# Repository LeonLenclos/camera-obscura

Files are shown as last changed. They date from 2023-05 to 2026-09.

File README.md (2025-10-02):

# Camera Obscura
Théâtre optique post-cinéma

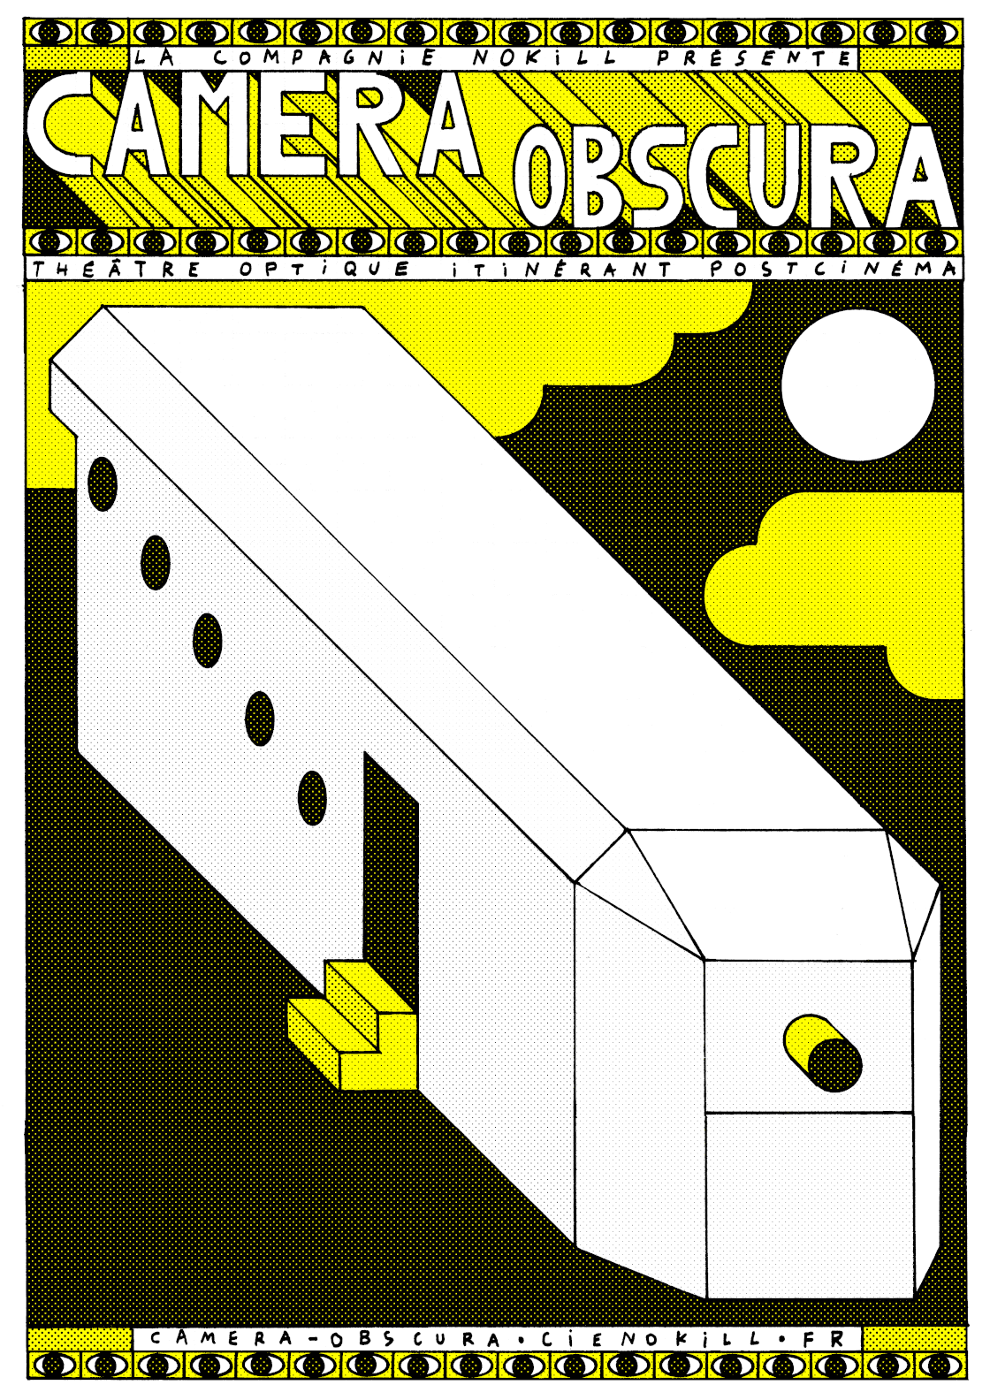
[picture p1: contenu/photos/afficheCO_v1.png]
Affiche Camera Obscura


*Camera Obscura* est un spectacle de théâtre optique itinérant de la Cie Nokill dont la première a eu lieu le 3 aout 2024. 

### Le dispositif

*Camera Obscura* est un dispositif qui propose au public l'expérience unique d'une séance de cinéma sans électricité. Les spectateur·ices s'installent dans la camera obscura et assistent à la projection d’un film réalisé en temps réel à l’extérieur. Les images sont projetées grâce à un système optique fait de lentilles et de miroirs. Les sons et la musique sont produits et interprétés en direct sur un ensemble d’instruments acoustiques et mécaniques.

### Souvenirs du futur

Le film projeté est [*Souvenirs du futur*](contenu/ecriture/souvenirs-du-futur.md). C'est une collection de fragments, des évocations vagues ou anecdotiques de futurs possibles. Des récits d'anticipation qui s'affranchissent des thèmes de la science fiction et proposent une vision ni utopique ni apocalyptique d'un futur pluriel, banal et étrange.

### Documentation du projet

Sur ce site nous avons rassemblé au fur et à mesure de la création, tous les contenus artistiques et techniques utiles. 

Même si à la base cette documentation est un outil de travail personnel, nous avons décidé de la mettre à disposition de toute personne intéressée par ce projet.

### Sommaire

- [Remorque](contenu/remorque.md), construction du théâtre optique "Camera Obscura".
- [Écriture](contenu/ecriture), textes, scenarios, découpages et références.
- [Objets](contenu/objet), plaques animées, marionettes, costumes, accéssoires, décors, utilisés dans le film.
- [Technique](contenu/technique), questions et réponses concernant les differents défis techniques. 
- [Prototypes](contenu/prototypes), liste des chambres construites pendant la création.
- [Production](contenu/production.md), partenaires du projet et calendrier des résidences.
- [Bibliographie](contenu/bibliographie.md), liens et documents utiles.

#### Documents

- [Dossier de création](contenu/dossier/dossier-camera-obscura.pdf), télécharger le dossier en pdf.
- [Fanzine](contenu/dossier/leprincipedelacameraobscura.pdf), télécharger *Le principe de la camera obscura* en pdf.
- [Ateliers](contenu/dossier/ateliers-camera-obscura.pdf), télécharger la doc des ateliers en pdf.

#### Divers

- [Todo](contenu/todo.md), bloc-notes des trucs à faire.
- [Media](contenu/media.md), liste de tous les media liés à la documentation de la création.
- [Meta](contenu/meta.md), Ressources liées à l'écriture de ce site.

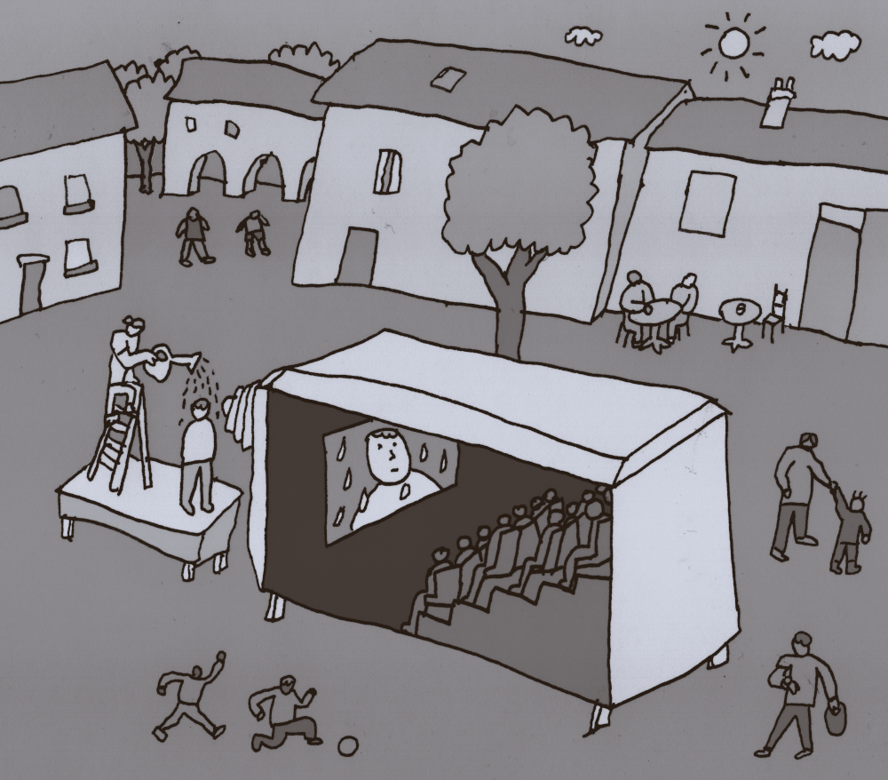
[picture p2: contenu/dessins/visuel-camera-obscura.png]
Dessin de la remorque


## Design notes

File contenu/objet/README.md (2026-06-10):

# Objet

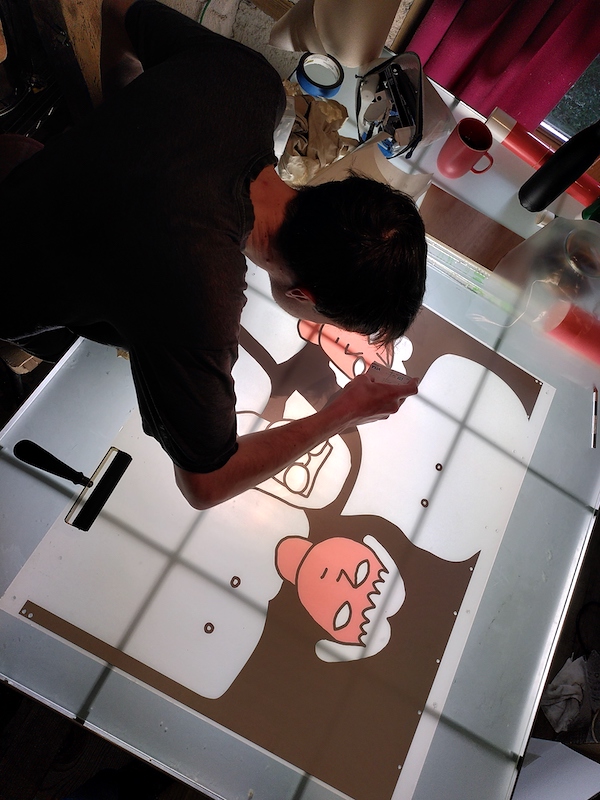
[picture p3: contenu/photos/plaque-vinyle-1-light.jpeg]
Pose de vinyle


Objets utilisés dans le film [*Souvenirs du futur*](../ecriture/souvenirs-du-futur.md).

- [Décors et accessoires](decors-accessoires.md)
- [Costumes](costumes.md) (et maquillage, coiffure)
- [Maquettes](maquettes.md)
- [Animations](animations.md) (plaques animées et marionettes)
- [Photos](photos.md)

## Rouleaux

- [titre](rouleau-titre.md) (source)
- [titre](rouleau-titre.pdf) (pdf)
- [photo](rouleau-photo.md) (source)
- [photo](rouleau-photo.pdf) (pdf)

```
# Créer pdf rouleau titre
wkhtmltopdf -T 0mm -B 0mm -L 0mm -R 0mm \
--page-width 500 --page-height 7010mm \
"https://camera-obscura.cienokill.fr/contenu/objet/rouleau-titre" rouleau-titre.pdf

# Créer pdf rouleau photo
wkhtmltopdf -T 0mm -B 0mm -L 0mm -R 0mm \
--page-width 780 --page-height 4010mm \
"https://camera-obscura.cienokill.fr/contenu/objet/rouleau-photo" rouleau-photo.pdf
```

## Billets

- [billets](billets/planche.md) (source)

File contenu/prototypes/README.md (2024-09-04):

# Les prototypes de chambres noires

dessin de trois prototypes
*De gauche à droite, les cameras 01, 02 et 03*

D'ici, on peut accéder aux fiches des différents protos de chambres noires (camera obscura). On distingue 2 types de réalisations :
- Les chambres individuelles, pour 1 regardeur à la fois (00, 01, 02, 03). Concues au départ pour tester les principes optiques du projet final (05) qui accueillera le spectacle, elles peuvent être disposées dans l'espace public en libre accès.
- Les chambres collectives pour un groupe de regardeurs dont le nombre peut varier de six (04) à vingt (05).

## Chambres individuelles

- [Camera obscura 00 - Mini camera obscura](camera00.md)
- [Camera obscura 01 - Les yeux dans le dos](camera01.md)
- [Camera obscura 02 - Chambre à antotype](camera02.md)
- [Camera obscura 03 - Chambre grand format](camera03.md)

## Chambres collectives

- [Camera obscura 04 - Chambre sprinter](camera04.md)
- [Camera obscura 05 - Chambre remorque](../remorque.md)

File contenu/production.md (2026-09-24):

[CLIQUER ICI POUR ALLER DIRECTEMENT À *MAINTENANT* DANS LE CALENDRIER DES RÉSIDENCES ↓](#maintenant)

# Historique de la création

- Août 2016 : Léon rencontre une camera obscura au musée du cinéma de Gérone
- Décembre 2017 : Bertrand rencontre une camera obscura naturelle dans sa chambre à coucher
- Mai 2019 : Léon rencontre une camera obscura naturelle dans le camion de la compagnie lors d'une résidence de *Turing Test*
- Mai 2020 : début du développement du spectacle
- Juillet 2020 : première tentative de créer des camera obscura dans des pièces de la maison avec différents objectifs placés sur des fenêtres obstruées
- Janvier 2021 : premier dossier de présentation
- Décembre 2022 : fabrication du premier prototype de camera obscura, *Les yeux dans le dos*
- Octobre 2023 : début de construction de la remorque
- Janvier 2024 : finalisation du scénario de *Souvenirs du futur*
- Avril 2024 : début du travail de mise en scène avec Lucile
- Août 2024 : première du spectacle

Soit quatre ans d'échanges et de réflexions éparses, deux ans de recherche et développement, un an de prototypage, un an de création à plein temps

# Générique

Un film de :

- Bertrand Lenclos
- Léon Lenclos

Avec :

- Lucile Balézeaux
- Bertrand Lenclos
- Léon Lenclos

Diffusion :

- Myléna Profit

Construction Remorque :

- Fabien Durand (Soudure)
- Zou Lenclos (Construction)

Aménagement Remorque :

- Jean-Claude Azemar (Vitrerie)
- Laurent Fayard (Menuiserie)
- Didier Pons (Peinture Carrosserie)
- Éva Ricard (Couture)

Accessoires :

- Steffie Bayer (Prothèse-marionette)
- Marco Cohen (Réflecteur)

Costume

- Lucile Balézeaux

Musique et Design Sonore

- Bertrand Lenclos

Dessin

- Léon Lenclos

Production :

- NOKILL

Coproduction :

- MIMA
- Le Parvis
- Le Quai des savoirs

Accueil en résidence :

- Le Kiwi / ARTO
- Le Périscope
- CIRCA
- Les Scènes croisées de Lozère
- L'Association des clous

Soutien :

- DRAC Occitanie
- DGCA Commission Art de la Rue
- Région Occitanie

Remerciements :

- Eric Amblard
- Sylvain Bahos
- Ronan Bouvier 
- Joël Boya
- Elise de Couleurs Papilles
- CréaLab de Graulhet 
- Jérémie Dain
- Paco Labat
- Florence Laffitte
- Zou Lenclos
- Thomas Letellier
- Frederic Lombardo
- Francis Lopez
- Juan P. Martínez Pastor
- Les Pasticiens Volants
- Marc Reynaud
- Evelyne Salançon
- Virginie Talou
- Gérard Tayeb
- Cie Titanos
- Arnaud Vidal

Logiciels libres :

- GIMP
- Git
- Inkscape
- LibreCAD 

Fournisseur :

- Aquabrasion
- Schiavon
- Ferrières
- Capus

Musique additionnelle :

*Marina*, Interprété par Georges Briez et son orchestre

# Historique de la création

- Août 2016 : Léon rencontre une camera obscura au musée du cinéma de Gérone
- Décembre 2017 : Bertrand rencontre une camera obscura naturelle dans sa chambre à coucher
- Mai 2019 : Léon rencotre une camera obscura naturelle dans le Camion de la compagnie lors d'une résidence de *Turing Test*
- Mai 2020 : Début du développement du spectacle
- Juillet 2020 : Première tentative de créer des camera obscura dans des pièces de la maison avec différents objectifs placés sur des fenêtres obstruées.
- Janvier 2021 : Premier dossier de présentation
- Décembre 2022 : Fabrication du premier prototype de camera obscura, *Les yeux dans le dos*
- Octobre 2023 : Début de construction de la remorque
- Janvier 2024 : Finalisation du scénario de Souvenirs du Futur
- Avril 2024 : Début du travail de mise en scène avec Lucile
- Août 2024 : Première du spectacle

Soit quatre ans de d'échanges et de réflexion éparses, deux ans de recherche et développement, un an de prototypage, un an de création à plein temps

# Calendrier des résidences

## Résidences passées

### du 7/12/2022 au 14/12/2022 : Graulhet (81) - Nokill
- construction maquette "les yeux dans le dos"
- début construction chambre à anthotypes

### du 2/3/2023 au 4/3/2022 : Graulhet (81) - Nokill
- finitions chambre à anthotype
- début construction chambre grand format
- début construction double miroir

### du 6/3/2023 au 8/3/2022 : Toulouse (31) - QDS
- Améliorations protos
- Recherches autour du soufflet
- Documentation des protos
- Tests en extérieur

### du 1/4/2023 au 6/4/2023 : Graulhet (81) - Chez Pons et au Fablab de la MJC de Graulhet
- construction soufflets des cameras 2 et 3
- construction du prisme de miroirs en toit d'Amici
- début construction camera 4
- prise de contact avec le Fablab d'Airbus 
- Amélioration cameras 1 et 2
- Construction camera 3
- Tests en extérieur
- Documentation vidéo avec Mathieu

### du 9/5/2023 au 12/5/2023 : Toulouse (31) - QDS
- Finissions soufflet OK
- Test anamorphose OK. On renonce à la projection frontale depuis le toit car la déformation est ingérable.
- Test camera sprinter OK. Ecran inadapté, à tester avec Grey +
- Test objectifs et lentilles OK. Les objectif ne remplissent pas l'écran. Les lentilles offrent un résultat exploitable.
- Test double mirroir OK. On fixe l'angle de prise de vue à 47° max. Ce qui correspond à 35mm en 4/3 sur le boitier 24/36. Soit un tirage de 2,25 m pour un écran de 2 m.
- màj doc et contact Gérard, Marc et Ronan
- pas de retour du Fablab Airbus

### du 10/6/2023 au 18/6/2023 : Mirepoix (09) - Mima
- Arrivée de Zou
- test camion
- test lentille achromatique Dia : 154 mm / focale : 2250 mm
- Tester 4 lentilles Dia 60 mm (focale : 2000 mm / 1500 mm / 850 mm / 660 mm) avec du montage.
- Tester lentilles avec miroir Amici.
- Tester bouts de séquence (ouverture, le pire).
- ecriture
- construction et test de marios

### en juillet 2023 (du 11 au 13) : Ramonville (31) - Arto
- test camion

### du 24/07/2023 au 28/07/2023 : Marseille (13) - Nokill
- plans remorque
- plans planchettes
- Mario

### du 9/10/2023 au 28/10/2023 : Graulhet (81) - Chez les Plasticiens volants
- Semaine 1 :
  - Extension plateau ✔
  - Fabrication des dix arches ✔
  - Fabrication de certains renforts ✔
  - Fabrication de certaines structures de l'avant ✔
- Semaine 2 :
  - À caler en plus de tout ça :
    - Proto hublots
    - Anticiper commande/achat materiaux :
      - pvc hublots
      - vitres hublots
      - Plancher OSB
      - Moquette (bleu foncé ?)
      - tissu parois kamut
      - Clous tapissiers ronds noir ?
      - Rails pour fixation isorel paroie et plafond
      - Peinture noire paroie régie ?
  - Lundi :
    - Fabrication Structure 2
    - Refaire renforts 5 et 6 en rajouttant 61mm
    - Couper les pates des structures 3 et 4
    - Préparer plateau (faisceau, accessoirs, etc.)
    - proto manchon
    - Découpe et pose du bas de caisse
  - Mardi :
    - Découpe et pose du bas de caisse
  - Mercredi (Pose du squelette sur la remorque) :
    - Fixer les gardes boue
    - Monter les arches par l'avant et l'arrière variable d'ajustement entre arches 7 et 6.
    - Rentrer les poutres de 6m, les renforts 9, les renforts 1
    - Refaire les renforts 4 en fonction.
  - Jeudi et Vendredi :
    - Fabrication proto fauteuils

- Semaine 3 :
  - Bonus :

  - Lundi matin
    - [x] Passage Fabien sur soudure et meulage
    - [x] encadrement des portes (prépa)
    - [x] prépa structure ecran
    - [x] Prépa renfort plancher gradins et toiture et renforts 1 (environ 22 renforts)
  
  - Lundi aprem
    - [x] Prépa Manchons x 80
    - [x] Soudure  renforts
   
  - Mardi matin
    - [x] Courses
    - [x] Soudure encadrement portes
    - [x] prépa trapes arrières et trapes latérale
    - [x] Souder Manchons x 80
    - [x] pate et fourrure (2 personnes)
    - [x] appeler Les clous.
    - [x] bouchage plateau
    - [x] fixer portes (1h)

  - Mardi aprem
    - [x] Soudure renforts plancher gradins et toiture et renforts 1 (environ 22 renforts)
    - [x] Poser Manchons
    - [x] Pose renforts plancher gradins et toiture et renforts 1 (environ 22 renforts)

  - Mercredi/Jeudi
    - [x] souder trapes arrières et trapes latérale
    - [x] Proto chaise avec accoudoir (2h prépa + 2h soudure)
    - [x] Tole et joints

  - Vendredi
    - [x] hublots
    - [x] faisseau electrique
    - [x] régler l'occultation base souflet
    
### du 30/10/2023 au 5/11/2023 : Assier (46) - Des clous
- Aménagement remorque :
    - [x] finition carosserie
    - [x] joint mastic PU
    - [x] plancher principal
    - [x] mofif trappe avant
    - [x] plancher coffre
    - [x] joint mastic PU
 
- Peut-être inviter Florian et Ludmila des scènes croisées à venir visiter la remorque (pour le choix du lieu quand on ira chez eux)

### Du 22/01/2024 au 30/01/2024 : Serre Boyer (04) - Chez Florence.
  - [x] écriture textes et musiques
  - [x] découpage et storyboard
  - [x] réalisation animatic
  - [x] dépouillement du storyboard
  - [x] Arrivée de Lucile

À prendre à Graulhet :
- petit sac caméra FX3 complet avec pied, semelle, lecteur cartes.
- couple schoeps, R87, cables audio, pied de micro, casque.
- instrument : Harmonium, scie, pavillon et percus
- ordi + disque dur externe
- planche et système pédale orgue, support pavillon.
- visseuse, boite vis, caisse rouge

À prendre à Marseille :
- Banc titre
- Ordi + cables bancs titre + clavier
- Matos dessin

### Du 30/01/2024 au 09/02/2024 : Graulhet chez les Plasticiens (81)

- [x] habillage alu bas grille extraction
- [x] cornière trappe est
- [x] Médium mur sud
- [x] finition Médium raccord plafond
- [x] alu trappe
- [x] passer cable caméra recul
- [x] cales plafond
- [x] contre marche
- [x] grille sur plancher
- [x] isolation sous plancher bas
- [x] Medium nord et porte
- [x] test enduit bas de caisse galva
- [x] coup de peinture noire
- [x] redessiner caisses à la bonne dimension

### Du 12/02/2024 au 16/02/2024 : avec Fabien (81)

 - [x] support Amici
 - [x] série fauteuils
 - [x] claisse clim

### Du 12/02/2024 au 16/02/2024 : Marseille (13)

 - [x] conception et dessin exostructure en tube
 - [x] conception et dessin tourelle + adaptation lentille existantes
 - [x] conception et dessin télécommande
 - [x] prépare une anim pour test

### Du 19/02/2024 au 25/02/2024 : Graulhet chez les Plasticiens (81)

 - [x] verrou
 - [x] coupe pied fauteuil
 - [x] conception machine à vent
 - [x] installation musique

Courses et fournitures :

 - [x] 10 crochet 50mm + 12 crochet 35 mm PROZIC
 - [x] disque tronconneuse 38 mm speed clic
 - [x] METISSE COTON 100 mm + PLAQUE LIEGE 30 mm

### Du 26/02/2024 au 03/03/2024 : Graulhet chez les Plasticiens (81)

Jour 1:

- [x] Structures en alu
  - [x] réalisation  rail
    - [x] couper alu
    - [x] assembler / fixer à la remorque (→ VIS RACCORDS / CROCHETS)
 - [x] réalisation chariot
    - [x] couper alu
    - [x] assembler (→ VIS RACCORDS)
    - [x] Fixer roues (→ VIS)
    - [x] Fixer paliers (→ 4× VIS M60 L=50)
 - [x] réalisation cage
    - [x] couper alu
    - [x] réparer manchons concernés
    - [x] assembler / fixer à la remorque  (→ VIS RACCORDS / CROCHETS)

Jour 2:
- [x] courses CP 
- [x] Planchette
  - [x] Fabrication planchette (→ BOIS CP10?)
  - [x] Fixation planchette-chariot (CROCHETS)
- [x] Soufflet
  - [x] Fixation soufflet-remorque
  - [x] Fixation soufflet-planchette
- [x] Écran
  - [x] Fixation écran
- [x] test image avec une lentille d'opticien collée à l'arrach sur la planchette.

Jour 3:
- [x] courses metal

Jour 4:
- [x] Test Plaque MIRE
  - [x] Montage tringle sur cage (→ ACIER / CROCHETS)
  - [x] Installation reflecteur
  - [x] Test image + mécanique 

Jour 5:
- [x] Amici
  - [x] Couper miroir
  - [x] Poser miroir
  - [x] Finir structure
  - [x] Perche
  - [x] Installer sur chariot (CROCHETS)

### Du 04/03/2024 au 11/03/2024 : Léon à Marseille (13)

 - [x] conception et dessin réflecteur
 - [x] conception et dessin support décor
 - [x] fin dessin plaque

### Du 04/03/2024 au 31/03/2024 : Graulhet chez les Plasticiens (81)

Courses et fournitures :
 - [x] SMBOIS
   CP antifeu plafond + siège 5 plaques CP IGNIFUGE peuplier

 - [x] BRUSSON
- 2 x CALE DE ROUE PETIT MODELE UK46 Ref. 1310009 
- 1m x FIL PLAT 2 X 0.75mm système rapide 9 à 36volts Ref. 0560970
- 1 x POIGNEE ST ETIENNE nouveau modèle embouti Ref. 0680096
- 12 x FERMETURE CAISSE MUNITION mini. Ref. 0700421
- 4 m x CLIP / JOINT CAOUTCHOUC A RECOUVREMENT Ref. 1400524
- 10 m x RONDIN Ø 9mm ADHESIF JOINT CAOUTCHOUC Ref. 1400170
- 8 m x JOINT DEMI-LUNE 7.7 x 11 mm sur ADHESIF Ref. 1400169 

 - [ ] COPROVER
vitre soufflet 6mm à mesurer et commander coprover

 - [x] CONNEXION PRESSION
- 2 x ARB2B040BU
- 2 x ARV1Z032CU
- 1m x ATF1Z032AU

 - [x] ARCELLOR
- 16 barres de 6m Tube carré 30x2mm Aluminium extrudé AW6060T6 EN 573-3 6000
- 4 barres de 6m  tube rond 50x2mm Aluminium extrudé AW6060T6 EN 573-3 6000
- 10 barres de 6m barre rectangulaire 40x5mm Aluminium extrudé AW6060T6 EN 573-3 6000

 - [x] OUTLET
- https://www.roues-roulettes-outlet.fr/gris-roulette-pivotante-blockage-total.html

 - [x] PIXARPRINTING
- [x] test transparent 1 plaque
- [x] 11 fichiers plexi noir

 - [x] PLEXIGLASS
- https://www.plexiglas-shop.com/fr/produits/plexiglas-gs-0f00-gt-clear.html
1/2 plaque 4mm pour rail
1/2 plaque noir pour marios
 - [x] compter les autres
 - [x] plaques sauf entières (pixart printing)

 - [x] ANTALIS

 - [x] CENTURION

 - [x] ROULETTES CDISCOUNT

 - [x] VIS EXPRESS
- https://www.vis-express.fr/fr/ecrou-relieur-tete-bombee-fendue-inox-a4/39289-980475-ecrou-relieur-tete-bombee-fendue-6x8-m4-6-dk9-inox-a4-3663072187511.html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
- https://www.vis-express.fr/fr/vis-metaux-fhc-tete-fraisee-empreinte-hexagonale-creuse-hexagonal-creux-classe-109-iso10642vs4721/48099-931086-vis-metaux-fhc-tete-frai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
- https://www.vis-express.fr/fr/vis-metaux-sans-tete-six-pans-creux-sthc-hexagonal-creux-bout-pointeau-din-914/32266-526584-vis-metaux-sans-tete-six-pans-creux-sans-te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
- (https://www.vis-express.fr/fr/ecrou-oreilles-din-315/31487-950900-ecrou-oreilles-m5-acier-zing-blanc-3663072092501.html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)
- https://www.vis-express.fr/fr/ecrou-embase-collerette-crantee-din-6923-din-6923collerette-crantee/31363-1001456-ecrou-a-a-collerette-embase-crantee-m5-acier-zing-bla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

 - [ ] VELCRO
 
  - [x] rail caisses clim
  - [x] plaque clim
  - [x] Aller chez schiavon
  - [x] découpe tourelle (→ ALU 4mm)
  - [x] rectification usinage arbres
  - [x] montage arbre tourelle
  - [x] Découpage fût (-> MATERIAUX ?)
  - [x] Assemblage fût
  - [x] obturateurs
  - [x] commande obturateurs
  - [x] montage arbre télécommande
  - [x] adaptation remorque
  - [x] seuil porte avec plat
  - [x] cache avant
  - [x] test Découpage vinyl et plexi
  - [x] réalisation structure  réflecteur
  - [x] pose Caméra recul

### Du 1/04/2024 au 7/04/2024 : Graulhet (81)
 - [x] couper plexi avec marge 1 cm
 - [x] coupe et perce 40 barres de 800 en alu ep 5 x 40
 - [x] reserver FabLab du mardi au vendredi pour laser plexi et coupe vinyle

### Du 08/04/2024 au 13/04/2024 : Graulhet chez les Plasticiens (81)

Dans l'ordre du plus ou moins urgent:

- [x] courses chez brusson
- [x] repérage Ramonville 
- [x] Percer les plaques (barres)
- [x] crochets plaques
- [x] Réflecteur (roues, surface, système de réglage)

### Du 15/04/2024 au 20/04/2024 : Nimes (30) - Périscope

Objectifs :

- Finir fabrication plaques
- Travailler manip et bande son anims.
- "Un atelier collectif autour de la création d'un court film qui utilise certaines des techniques en jeu dans la création en cours Camera Obscura. Les techniques en question se situant quelque part entre papier decoupé, théâtre d'ombre et lanterne magique."

### Liste matos pour Nimes

##### Les plaques

- 28 (14×2) Crochets (avec boulon et poulie)
- 28 (14×2) Barres en alu
- Toutes les plaques fixes (imprimées et vierges) et toutes les plaques d'anim
- Rails et autres accéssoires
- Pièces des marionettes
- Les rouleaux de vynile précoupé
- Le carton des chutes (vynile et plexi) au cas où
- sangles et mousse

##### Matos et outils pour fabriquer les plaques

- Table en verre + Néon
- Makita (mèches M4, M5, Fraise)
- Martyrs et cales pour perçage
- Réglette gabaris en plexi pour perçage.
- Cutter / Exacto / Ciseaux
- Planche à découper
- Elastiques
- Pinceau propre
- Rouleau d'essuie-tout
- Pschit-pschit avec le mellange (1.3 litres d'eau / 4 gouttes de liquide vaisselle / 4 cuillères à soupe d'alcool à 90 (isopropylique))
- 1 bouteille alcool
- Rouleau de transfert
- Rouleau à maroufler, carte bleu usagée
- Grosse poubelle noire du local (?)
- Torchon
- scie sauteuse
- scie à métaux
- papier de verre (avec cale à poncer)
- Kit visserie plaques (vis de 4 courtes/longues fraisées/bombées, écrous de reliure, vis pour écrous de reliure, rondelles)
- clé à laines, clé à pipes

##### Pour tester les plaques en intérieur

- Une découpe
- 3 pieds projo
- geuzes
- Le rail
- Écran papi pour reflecteur interieur
- Gants blancs

##### Pour tester les plaques en exterieur

- Le grand réflecteur
- Un praticable (?)
- 2 escabeau

##### Son

J'ai listé les instruments cité dans le séquenciers aux sequences animées, a toi de voir si c'est la peine de prendre tout ou moins ou plus.

- Clés
- Harmonium
- Ocean drum
- Spring Drum
- Coquillages
- Scie
- Bulles
- Grinçoir
- Guitare
- Tube accordé
- Frog drum
- Balle rebondissante
- Aplaudisseur
- Rondelles
- Gramophone
- Disque pour craquement)
- Percus pour comportement (monocorde, cymbales, gong, grosse caisses)

##### Kit cinéma

- Pied camera
- Sac camera avec micros, cable et pied

##### Projection

- 1 VP secour avec rotule
- 1 écran/moniteur TT

##### Ateliers

- Carton fin (pochette dessin)
- Tissu noir
- Les écrous de relieurs achetés à graulhet chez cuir shop là malette verte
- Emporte pièce adapté
- Si il y a : Une plaque de plexi transparent environ A3 ou A2 pour servir de support aux animations verticales faites pendant l'atelier
- Des bons ciseaux

##### Divers

- 2 Prolongs + 2 Multiprises
- Pinces et serre-joints stanley
- 2 caisses de plaques
- scotch bleu
- Ordi + chargeur + HD cables
- Kit camera de reccul
- caisse rouge
- bijoute totale
- glaciere garnie

##### A prendre de marseille

- Papiers noir, papiers transparents, papiers colorés.
- Emporte pièce
- Perforeuse classeur
- Table lumineuse (?)
- Poscas / marqueurs
- Exacto

### Atelier du samedi

- On fait tout en 2D
- Pantins qui se manipulent à l'envers (marche), bras en l'air, etc.
- Animation style plaque de lanterne à système.
- Cutout animation en stop-motion (?)
- Privilégier les silhouettes 
- Faire écrire un ou des souvenirs du futur
- Choisir une palette limitée
- Filmer à l'horizontale et à la verticale.

## Premières résidences de mise en scène

### Du 22/04/2024 au 30/04/2024 : Auch (32) - Circa

- FX3 + Liaison HF CARO + tvlogic pour retour vidéo. Vidéoprojecteur.
Accessoires :
  - lunettes spéciales
  - clavier tt

Pirouette Circaouette mercredi 24 avril entre 15h30 et 16h30 dans la roulotte
29/4 à 15h am ou 30/4 à 11h

Objectif pour auch, pouvoir travailler toutes les scènes sauf :
- Je me souviens de l’embouteillage

- écriture et jeu

### Du 6/05/2024 au 07/06/2024 : Graulhet chez les Plasticiens (81)

Achat : 

- [x] tracker ★★★

| modele | prix | abo | autonomie |
|---|---|---|---|
| [Slkon](https://www.sklon.fr/218-traceur-gps-espion-ultra-longue-autonomie-jusqu-a-240-jours.html) | 229€ | payer sim avec sms | 240 jours |
| [Protech AT701](https://www.hd-protech.com/traceur-gps/795-traceur-gps-longue-autonomie-4g-lte-m1-nb-iot-suivi-temps-reel-at701.html) | 289€ | payer sim avec sms et data | 5 ans à 1 pos/j |
| [Protech AT705](https://www.hd-protech.com/traceur-gps/808-traceur-gps-sans-cablage-sans-abonnement-aimante-tres-longue-autonomie-at705.html) | 299€ | payer sim avec sms et data | 10 ans à 1 pos/j |
| [TrackMy](https://trakmy.fr/produit/traceur-gps-ultra/) | 129€TTC | 46.80€TTC/an (1 an offert) | 5 ans à 3h/5j/semaine |
| [Capturs](https://www.capturs.com/fr/produit/endurance-traceur-gps/) | 139€HT | 36€HT/an | 5 ans à 1 pos/j |
| [Secutec](https://www.secutec.fr/balise-gps-4g-ultra-longue-autonomie-4-ans-maximum.html/) | 349€ | 19/an (2 ans offert) | 4 ans à 1pos/j |

- [x] ★★★ velcro reflo
- [x] ★★★ acrifix
- [x] ★★★ aimant x 40 percé fraisé 2cm
- [x] ★★★ Lame de scie ruban (HY-7305080144)
- [x] ★★★ fil Alu 0,8mm
- [x] ★★★ velcro siège et mur
- [x] ★★★ rivets M5

Todo reportés de avant nimes

- [x] ★★★ Rack plaques XL + 10 cm en haut + 20 cm en bas + profonde (voir manivelle photo)
- [x] ★★ **1H** tronconner support droite dans un rack et support gauche dans l'autre. 
- [x] ★★★ rangement des outils

Todo notés à Nimes Concernant les plaques
- [x] ★★★ **1H** *Podium* test collage réparation
- [x] ★★★ **1H** *Golden Record 2*  Fixer un bout de plexi pour butée là où c'est cassé
- [x] ★★ *Podium* Poignées en plexi pour le 8e (4mm) 
- [x] ★★ *Podium* dessiner et dé<coupe laser Suite des marches (raccord + aimant)
- [x] ★★ *Période malheureuse* poignée en plexi (4mm)
- [x] ★★ *Période malheureuse* Vinyle (tout)
- [x] ★ *Période malheureuse* doubler les rails
- [x] ★ *Niveau de l'eau* animer mario dame
- [x] Raccourcir crochets :
  - [x] *Periode heureuse* Droit
  - [x] *Mutation 2* Gauche + droit
  - [x] *Période malheureuse* gauche + droit

Reflecteur
 - [x] ★★★ **2H** poser velcro
 - [x] ★★★ **4H** fabriquer tissus noir
 - [x] ★ roues plus grosses

Rail, Amici et planchette
 - [x] ★★★ **1H** faire 2 rails de 5m (3+2) avec 3 crochet et 2 support bas de 5m (3+2) avec 3 crochet
 - [x] ★★★ rainure moyeux tourelle
 - [x] ★★★ **3H** changement miroir Amici (4 mm decoupe laser) coller alu sur cadre
 - [x] ★★★ **2H** remonter planchette / fabriquer cache

Régie
 - [x] ★★ **1H** revoir embouchure pavillon
 - [x] ★★ **2H** support tom tonerre, coquillages, clés etc...
 - [x] ★★★ **2H** SAS régie
 - [x] ★★ porte guitare
 - [x] ★★ raccourcir manivelle vent

New Plaques
 - [x] ★★★ faire photo St Tropez et mode
 - [x] ★★★ faire fichier film photos + journal pour print
 - [x] ★★★ faire fichier générique
 - [x] ★★★ **2H** monter plaque photo
 - [x] ★★★ **2H** monter plaque générique

Fauteuil
 - [x] ★★★ **4H** prépa bois fauteuil
 - [x] ★★ achat mousse fauteuil
 - [x] ★★ achat tissus fauteuil

Etanchéité
 - [x] ★★★ achat rivet M5
 - [x] ★★★ achat rondelle caoutchou M5
 - [x] ★★★ **32H** remplacement rivet toit et avant

Fermeture/huisserie
 - [x] ★★★ **1H** verrou régie
 - [x] ★★★ **4H** pose plexi hublot

Finition salle
 - [x] ★★★ pose plafond
 - [x] ★★★ **4H** cache écran (côtés et haut en tissus) fixé avec velcro éventuellement finition cornière noire.

acces public 
 - [x] ★★★ dessiner escalier
 - [x] ★★★ coupe alu escalier
 - [x] ★★★ **2H** coupe Bois escalier
 - [x] ★★★ **4H** montage escaliers

### Le 29/05/2024 : Marseille (13) - Photos

- 3 x St Tropez / 1 mode

### Du 11/06/2024 au 13/06/2024 : Graulhet chez les Plasticiens (81)

- Décor et installation technique/Montage

### Du 16/06/2024 au 22/06/2024 : Graulhet chez les Plasticiens (81)

- Mise en scène

### Du 17/06/2024 au 23/06/2024 ou du 24/06/2024 au 30/06/2024 : Mende (48) - Scènes croisées de Lozère
 - [ ] Anticiper accés et emplacement roulotte à Mende

- Tringle costumes
- Table accessoires
- Table marionettes
- Efffet neige
- Effet vent

LISTE MINI MATÉRIEL CO
 - [ ] 3 Rack anim
 - [ ] pochette mario + pochette bateau
 - [ ] 2 décors
 - [ ] reflecteur + 2 triangles + 4 traverses + 2 bidons + 2 élingues
 - [ ] 3 praticables + 8 pieds 80 + 4 peids 40 + 4 escaliers + 16 lawyer
 - [ ] sac accessoire CO (Poulie niveau de l'eau, 12 jonctions praticables, 2 cornières réflecteur)
 - [ ] 4 rails plaques (3m + 2m)+ pied gravity avec adaptateur + support décor
 - [ ] Cage (HE, HO, HN, NE, NO)
 - [ ] rail (2 arches + 2 traverses)
 - [ ] Chariot + miroir Amici
 - [ ] Soufflet
 - [ ] Valises costumes
 - [ ] Instruments
 - [ ] Accessoires
 - [ ] Table marionettes
 - [ ] Table accessoires

OUTILS/ACCESSOIRES
 - [ ] Makita
 - [ ] niveau bulle
 - [ ] Caisse outil rouge
 - [ ] Caisse bleue rivet
 - [ ] Sac scotch/sangles/pinces
 - [ ] Sac bijoute
 - [ ] Caisses visserie
 - [ ] meuleuses/scie sauteuse/base consommables (disque/papier de verre/lame scie)
 - [ ] Talkie
 - [ ] Frein filet
 - [ ] Colle plexi
 - [ ] Chutes plexi + Chutes vynile
 - [ ] Marches en bois

CAPTA
- [ ] Appareil photo
- [ ] VP
- [ ] Schopes
- [ ] Cables
- [ ] Ordi

 MATERIEL
 - [ ] Tube de 35
 - [ ] Crochets
 - [ ] Planches
 - [ ] Vynile noir
 - [ ] Vitre 6mm
 - [ ] Fil de fer

COURSES
- [x] 2x tiges filetés 1m M12

- Mise en scène

- ### Du 03/07/2024 au 14/07/2024 : Graulhet chez les Plasticiens (81)
finitions remorque et autres

PLAQUES
- [x] ★★ *Niveau de l'eau* Poignées poissons
- [x] ★★ Bavettes transitions :
  - [x] *Titres* 
  - [x] *Mutation*
  - [x] *Golden Record* 
  - [x] *Comportement*
- [x] ★ *Prologue* Améliorer fluidité bateau essayer une manivelle
- [x] ★ *Comportement 1* Allonger rails des 2 petits caches noirs.
- [x] ★ *Podium* Vinyle points verts
- [x] ★ *Période heureuse* fluidité

NEW PLAQUES
 - [x] ★★★ faire fichier générique OK
 - [x] ★★★ print générique OK
 - [x] ★★★ achat support plastique
 - [x] ★★★ monter rouleau photo
 - [x] ★★★ monter rouleau générique

MARIOS
 - [x] ★★★ système rangement mario

DIVERS
 - [x] ★★ **2H** SACD
 - [x] ** **4H** Isolation trappes

REFLECTEUR
 - [x] ★★★ decaler axe
 - [x] ★★★ reparer barre bouladou

MACHINERIE
 - [x] ★★ **1H** revoir 2 réglages
 - [x] raccourcir l'avant du chariot

FAUTEUIL
 - [x] ★★★ **1H** fin polissage fauteuil
 - [x] ★ fin couture housse
 - [x] ★ montage fauteuils

REGIE
 - [x] ★★★ tube extérieur avec passage de cuve
 - [x] ★★ new installation percu basse

DECOR
 - [x] ★★★ **4H** décor chambre taille double (200x145 - Remonter décor de 5cm - matelas du bord gauche au centre à 35cm du haut du décor, couverture à 20cm du haut du matelas)
 - [x] ★★ syteme rangement décors (housse en skaï blanc)

COSTUME
 - [x] ★★★ achat costumes      
 - [x] ★ finition prothèse (rallonge tige et col)

ETANCHEITÉ
 - [x] ★★★ **2H** finition pose joint trappe et plaque arrière
 - [x] ★★ **1H** remplacement rivets arrière

FERMETURE
 - [x] ★★ **4H** pose volets hublot

SALLE
 - [x] ★★ pose tissus

PUBLIC
 - [x] ** Rampes escalier

CLIM
 - [x] ★★ poignée caisses clim
 - [x] ★★ Achat Excelsior : matériel intérieur caisse clim
 - [x] ★ conception ventilation

### Du 15/07/2024 au 21/07/2024 ou du 22/07/2024 au 28/07/2024 : Tarbes (65) - Le Parvis
 - [x] Anticiper accés et emplacement roulotte
       
- Mise en scène + 2 avant-premières

### du 29/7/2024 au 4/8/2024, Mirepoix (09) - Mima
- [x] Anticiper accés et emplacement roulotte

- Finitions et premières

### du 12/4/2025 au 15/5/2025, Graulhet (81) - Plastoc - Améliorations techniques et reprise
 - [x] ★★★ rampe PMR
 - [x] ★★★ système démontage sièges place PMR
 - [x] ★★★ cablage  
 - [x] ★★★ pose panneaux solaires/chargeur batterie dans boitier.
 - [x] ★★★ pose Tableau 220V/circuit alim/circuit intérieur
 - [x] ★★★ sortie de secour
 - [x] ★★★ système ventilation arrière
 - [x] ★★★ peinture noire intérieure
 - [x] ★★★ pose mini-ventilateur

### du 19/5/2025 au 30/5/2025, Graulhet (81) - Plastoc - Améliorations
 - [x] ★★★ achat et installation extincteur
 - [x] ★★★ achat lunette
 - [x] ★★★ modif reflo hauteur réglable (manchon)
 - [x] ★★★ défonce plancher porte
 - [x] ★★★ reparation orgue
 - [x] ★★★ changer 1 ventilo
 - [x] ★★★ changer 1 mini-ventilo
 - [x] ★★★ fixation ventilo
 - [x] ★★★ trouver renfort pour montage VES
 - [x] ★★★ prépa Bobigny
 - [x] ★★★ resa hotel Bobigny
 - [x] ★★★ 2 strap XLR
 - [x] ★★★ lumière feu de gabarit
 - [x] ★★★ range mailloche
 - [x] ★★★ chgt matière machine à pluie
 - [x] ★★★ achat IVECO C15 3.0l L2H2
 - [x] ★★★ storyboard clip
 - [x] ★★★ pose prise alume cigare 12V + USB + Voltmetre soute
 - [x] ★★★ boite Tracker

### du 19/6/2025 au 30/6/2025, Graulhet (81) - Plastoc - Améliorations

 - [x] ★★★ carte grise
 - [x] ★★★ chgt assurance new CG
 - [x] ★★★ ré-impresion générique et photo
 - [x] ★★★ couchette remorque
 - [x] ★★★ Arrêt sur les rails des plaques
 - [x] ★★★ Refaire plaque période malheureuse 
   - [x] ★★★ découpe plexi
   - [x] ★★★ découpe vynile
 - [x]  ★★★ Maintence plaque 
 - [x]  ★★★ Prépa tournage
 - [x]  ★★★ Cache fusible camion
 - [x]  ★★★ tester gaufre carton

### du 30/7/2025 au 3/8/2025, Graulhet (81) - Plastoc - Améliorations
 - [x]  reparation reflo
 - [x]  test tuyau microporeux

### du 30/8/2025 au 5/9/2025, Graulhet (81) - Plastoc - Améliorations
 - [x]  changer depron

# MAINTENANT

### hiver 2025/2026

GENERAL

 - [ ] ★★★ achat cric + chandelles
 - [x] ★★★ installation tuyau micro poreux + structure
 - [ ] ★★★ solution pour reglage latéral aimant principal
 - [ ] ★★★ avoir des pieds de 60 pour les praticables 
 - [ ] ★★★ centrer gravité antotype
 - [ ] ★★ peinture porte
 - [x] ★★ revoir jeu de cales
 - [ ] ★★ renfort rampe PMR

CAMION
 - [ ]  ★★★ Caméra(s) de recul
 - [ ]  ★ Sono camion

REGIE
 - [x] ★★★ changer sim tracker 
 - [x] ★★★ cale démarrage gramophone
 - [ ] ★★★ pluie seau
 - [ ] ★★ diffusion arrière passer les PVC ?
 - [ ] ★ trouver machine à applaudir
 - [ ] ★ corde contrebasse
 - [ ] ★★ régler flair soufflet
 - [ ] ★★ régler étanchéïté cache avant
 - [ ] ★★★ Kit nettoyage optique
 - [ ] ★★★ arret tourelle

EXT
 - [ ] ★ niveau + boussole
 - [ ] ★★★ système locket trappe arrière en acier
 - [x] ★★★ cadenas trappes arrieres
 - [ ] ★★★ bavette en skaï blanc
 - [ ] ★★★ sécu ext fermetures portes trappes
 - [ ] ★★★ réparer portes trappes latérales 
 - [ ] ★★★ réparation porte principale

PLAQUES
 - [/] ★★★ barre de vérouillage plaque
 - [ ] ★★★ descendre la vis de calage du podium
 - [x] ★★★ peigne frites
 - [ ] ★★★ faire spare marionnette parapluie

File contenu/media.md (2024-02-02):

# Media

Cette page rassemble tous les medias liés à la documentation de la création. Ce sont les images, vidéos, etc. utilisées dans les différentes pages du site.

# Vidéos

Les vidéos sont hébergées sur Vimeo et rassemblées dans [un showcase nommé Camera Obscura](https://vimeo.com/showcase/10324493)

<div style='padding:56.25% 0 0 0;position:relative;'>
    <iframe src='https://vimeo.com/showcase/10324493/embed' allowfullscreen frameborder='0' style='position:absolute;top:0;left:0;width:100%;height:100%;'></iframe>
</div>

# Images

Les images sont réparties dans 4 dossiers. Elles sont hébergées sur le git. Les images en bitmap (non vectorielles) sont compressées pour alléger le site.

## Animations

le dossier [`animations/`](https://github.com/LeonLenclos/camera-obscura/tree/main/contenu/animations) contient les fichiers des animations (voir aussi : [objet/animations](objet/animations).

{% include gallery.html folder="/contenu/animations/" %}

## Photos

le dossier [`photos/`](https://github.com/LeonLenclos/camera-obscura/tree/main/contenu/photos) contient les photos prises pendant la création.

{% include gallery.html folder="/contenu/photos/" %}

## Plans

le dossier [`plans/`](https://github.com/LeonLenclos/camera-obscura/tree/main/contenu/plans) contient les dessins techniques, patrons et plans utiles pendant la création.

{% include gallery.html folder="/contenu/plans/" %}

## Dessins

le dossier [`dessins/`](https://github.com/LeonLenclos/camera-obscura/tree/main/contenu/dessins) contient les dessins non-techniques et les illustrations.

{% include gallery.html folder="/contenu/dessins/" %}

## Img

le dossier [`img/`](https://github.com/LeonLenclos/camera-obscura/tree/main/contenu/img) contient toutes les images qui n'entrent pas dans les catégories précédentes, notamment les gif animés et les montages photos.

{% include gallery.html folder="/contenu/img/" %}

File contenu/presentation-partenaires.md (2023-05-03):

# Camera Obscura
#### Fiche de présentation à l'intention des partenaires techniques et scientifiques.

*Camera Obscura* est un projet de théâtre optique itinérant dont la première est prévue pour l'été 2024.

<div style="display:flex;flex-direction:row;flex-wrap:wrap;">
illustration camera obscura
illustration camera obscura
</div>

## En résumé

Une salle de cinéma est posée dans l'espace public, une vingtaine de spectateurs s'y installent, la salle est plongée dans le noir et le public assiste à la projection d'un court-métrage d'une vingtaine de minutes.

La particularité de ce film est qu'il est produit sans pellicule, ni vidéo, ni électricité, et qu'il n'utilise comme énergie que celle du soleil et des comédiens.

<div style="display:flex;flex-direction:row;flex-wrap:wrap;">
illustration camera obscura
illustration camera obscura
</div>

Les images sont des captations du monde extérieur qui transitent par un dispositif optique fait d'objectifs, de prismes et de miroirs. Les sons et la musique sont produits et interprétés en direct grâce à un ensemble d'instruments acoustiques et mécaniques.

L’enjeu principal de cette création est donc de créer l’illusion de la projection d’un film et de reproduire les codes et les formes du cinéma, sans en utiliser la technologie.

Cette démarche s'inscrit à la fois dans une idée de sobriété énergétique et dans la volonté de créer une esthétique et une expérience unique.

## Défis techniques

Ce projet s'accompagne d'un grand nombre de défis techniques dans des domaines variés :
- Comment afficher une image [lumineuse](technique/luminosite.md) de [grande dimension](technique/calage.md) sans autre source de lumière que le soleil dans un véhicule transformé en salle de cinéma itinérante ?
- Comment [redresser une image](technique/renversement.md) naturellement renversée par son passage à travers un objectif ?
- Comment maintenir une [température supportable](technique/isolation.md) et assurer un renouvellement de l'air dans une remorque exposée au soleil sans apport extérieur d'énergie ?
- Comment servir des popcorns aux spectateurs, sans utiliser ni gaz ni électricité pour les cuire ?
- Comment donner l'[illusion d'un son "cinéma"](technique/son.md) en se limitant à des systèmes acoustiques ?
- Comment construire une [salle de cinéma](prototypes/camera05.md) légère, durable, compacte et mobile adaptée à l'accueil du public ?

Pour relever ces défis, nous cherchons activement des partenaires : des interlocuteurs pour la conception, mais aussi des lieux et des moyens de fabrication, et des circuits d'achat ou de récupération de matériel.

<div style="display:flex;flex-direction:row;flex-wrap:wrap;">
illustration camera obscura
illustration camera obscura
</div>

## La compagnie Nokill

*Camera Obscura* sera le cinquième spectacle de notre compagnie. Dans les spectacles précédents dont les teasers et les descriptions sont disponibles sur [le site de la compagnie Nokill](http://cienokill.fr/), nous convoquons régulièrement sur scène des dispositifs techniques qui nous servent de supports pour raconter des histoires, des robots dans [*Turing Test*](http://turing-test.cienokill.fr/), des machines pré-cinématographiques dans [*L'Envol*](http://cienokill.fr/spectacles/lenvol/), des hologrammes dans [*Elektra*](http://cienokill.fr/spectacles/elektra/). *Camera Obscura* s'inscrit dans la continuité de cette démarche.

## La documentation du spectacle

Comme nous avons eu l'occasion de le faire pour [*Turing Test*](http://turing-test.cienokill.fr/), nous documentons l'intégralité du processus de création sur [un site dédié à *Camera Obscura*](https://camera-obscura.cienokill.fr/), vous pourrez y trouver du contenu concernant les différents aspects du spectacle (technique, artistique, production). Nous sommes aussi disponibles pour échanger [par mail](http://cienokill.fr/contact/) ou en visio, pour répondre à vos questions et vous parler du projet plus en détail.

<div style="display:flex;flex-direction:row;flex-wrap:wrap;">
illustration camera obscura
illustration camera obscura
</div>

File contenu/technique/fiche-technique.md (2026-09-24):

## Fiche technique
# *Camera Obscura*, Cie NOKILL

<small>Version du 24 juin 2026 <span class="print">(La version la plus récente est consultable en ligne à cette adresse :<br/>[camera-obscura.cienokill.fr/contenu/technique/fiche-technique.html](https://camera-obscura.cienokill.fr/contenu/technique/fiche-technique.html)</span> </small>

<span class="web">Une version PDF de ce document est téléchargeable à cette adresse :<br/>
[camera-obscura.cienokill.fr/contenu/technique/fiche-technique-camera-obscura.pdf](https://camera-obscura.cienokill.fr/contenu/technique/fiche-technique-camera-obscura.pdf)</span>

## Équipe
#### Contact comédien·nes
- Léon Lenclos – 06 27 65 68 33 – contact@leonlenclos.net
- Bertrand Lenclos – 06 09 90 38 97 – bebert@nokill.fr
- Lucile Balezeaux – 06 64 08 84 31 – lucile.balezeaux@gmail.com

#### Contact technique
- Léon Lenclos – 06 27 65 68 33 – contact@leonlenclos.net
- Bertrand Lenclos – 06 09 90 38 97 – bebert@nokill.fr

#### Contact diffusion
- Myléna Profit – 06 11 99 24 73 – diff@nokill.fr
  
#### Contact administration et production
- Bertrand Lenclos – 06 09 90 38 97 – admin@nokill.fr

## Représentations
### Résumé
Camera Obscura est une salle de cinéma itinérante. Le public entre à l'interieur de la camera obscura pour assister à la projection d'un film produit en direct à l'exterieur.

### Durée 
- Accueil public : 5 minutes
- Spectacle : 30 minutes
- Sortie : 5 minutes

Total : 40 minutes

### Horaires
4 représentations par jour à des horaires ensoleillés.
Les horaires possibles dépendent de l'angle d'élévation du soleil qui doit être supérieur à 30°.

Par exemple : 
- à Toulouse le 20 juin la plage des horaires possible est de 10h30 à 19h30 (Par exemple : 11h30 - 12h00 / 15h30 - 16h00 / 16h30 - 17h00 / 17h30 - 18h)
- à Toulouse le 2 octobre la plage des horaires possible est de 12h à 17h30 (Par exemple : 12h30 - 13h / 14h30 - 15h00 / 15h30 - 16h00 / 16h30 - 17h)

Il est indispensable de nous consulter avant de définir les horaires de jeu.

## Public

### Jauge 
Par représentation :

- 21 places assises
- ou 19 places assises + 1 place PMR
- ou 17 places assises + 2 places PMR

### Accessibilité
- Accès PMR : par rampe TPMR côté sortie de secour.
- Personnes malvoyantes : peut convenir (contient textes, bruitages et musiques).
- Personnes malentendantes : peut convenir (spectacle très visuel).

### Accueil public
- À partir de 8 ans.
- Prévoir une personne avant les représentations pour accueil billetterie.
- Prévoir éventuellement une personne pendant les représentations pour gestion du public à l'extérieur (à valider en amont en fonction des lieus).

## Accueil compagnie

### Accès au site

Véhicules sur site :
- La "remorque" : la salle de spectacle *Camera Obscura*
- Le "camion" : transport du matériel, tracteur de la remorque et loge rapide

Caractéristiques véhicules :
- Hauteur remorque : 3,10 m
- Largeur remorque : 2,50 m
- Longueur remorque : 7,50 m
- Longueur remorque + camion : 13,5 m
- Poids remorque : inférieur à 3,5 t
- Poids camion : inférieur à 3,5 t
- Poids remorque + camion : inférieur à 7 t

Du fait de l'encombrement des véhicules, l'itinéraire d'accès au site doit être étudié en amont avec la compagnie.

### Montage/Démontage
- Montage : 1 service
- Démontage : 1 service
- Un·e technicien·ne supplémentaire nécessaire pour le montage et le démontage

### Transport, repas, nuitées
À la charge de l'organisateur. Nuitées en chambres individuelles. Pas de régime alimentaire particulier.

## Besoins techniques

### Implantation

- Dimensions remorque : 2,50 × 7,50 m
- Espace minimum nécessaire : 8 × 13 m
- Terrain : plat (pente max : 3 %)
- Orientation : l'avant de la remorque doit être orienté nord-nord-est (entre 20 et 25°)
- Ensoleillement : l'espace de jeu doit être ensoleillé pendant les horaires de jeu (pas d'ombre portée d'arbre ou d'architecture sur l'espace de jeu)

La Camera Obscura s'installe en ville ou à la campagne, sur une place vivante, dans une zone industrielle abandonnée, dans un parc, en pleine nature, au coeur d'un festival, etc.

Le camion doit rester à proximité de l'espace de jeu (à moins de 30 m).

Prévoir un gardiennage la nuit.

###  À fournir

- Un point d'eau à moins de 25 m (connecteur rapide type gardena) pour remplir des bidons pour lester le matériel et pour alimenter le système de refroidissement de l'air à l'intérieur de la remorque. 
- Une ligne 16A à la remorque.

###  Contraintes météo

- Le spectacle peut être joué par temps couvert et faibles précipitations.
- Le spectacle ne peut pas être joué en cas de pluie abondante (>1 mm/h) ou de vent dépassant 65 km/h.
- Pour la santé des comédiens et le bien-être du public, le spectacle ne peut pas être joué à des températures dépassant 40°C.

## Plan

implantation

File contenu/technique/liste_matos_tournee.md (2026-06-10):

JEU

 - [ ] Remorque Camera Obscura + roue de secours + Manivelle + 2 cales métal + clés
 - [ ] Caisse grise de cales bois + boule antivol rouges et basteing + Niveau bulle jaune
 - [ ] Sac mangrove accessoire CO
   - [ ] Poignées portes x 4 + 2 carrés
   - [ ] Poulie niveau de l'eau
   - [ ] contre-poids chariot
   - [ ] 12 jonctions praticables
   - [ ] 2 cornières réflecteur
   - [ ] 12 ? colliers clamp
   - [ ] clavette commande tourelle
 - [ ] 4 Stapontins
 - [ ] 3 Racks anim
 - [ ] 1 Racks mario
 - [ ] 2 Décors chambre
 - [ ] Reflecteur
   - [ ] 2 triangles
   - [ ] 4 traverses
   - [ ] 2 bidons
   - [ ] 2 élingues
   - [ ] Table polycarbonate accessoires
   - [ ] Miroirs
   - [ ] Sac linge sale
 - [ ] 4 praticables + 8 pieds 80 + 12 pieds 40 + 3 escaliers
 - [ ] 8 lawyer grand + 8 lawyer petits
 - [ ] 6 basteings
 - [ ] 4 rails plaques (3m + 2m)+ pied gravity avec adaptateur
 - [ ] 2 pieds manivelles avec crochets + 2 Barres décor
 - [ ] Cage (HE, HO, HN, NE, NO)
 - [ ] Rail (2 arches + 1 traverse)
 - [ ] Chariot
 - [ ] miroir Amici
 - [ ] Soufflet
 - [ ] Drapeau reflecteur + clamp
 - [ ] Tuyau PVC voix extérieures
 - [ ] 2 systèmes ventilos soutes 12 V
 - [ ] 2 cadres refroidissement + pompe + Tuyan en Y
 - [ ] Piscine + bache 2m
 - [ ] gonfleur Ryobi
 - [ ] Sac secteur (1 x P17/P17, 1 P17/secteur, 2 rallonges, 1 triplette)
 - [ ] 1 tapis brosses
 - [ ] pompe à vélo rouge
 - [ ] Tissus Bavettes noires
 - [ ] 1 enrouleur tuyau eau + petit tuyau + adaptateurs
 - [ ] Talkies
 - [ ]  Instruments en place
   - [ ]  (gramophone avec disque, cale et aiguilles
   - [ ]  Guitare avec médiateur et bottle neck
   - [ ]  Scie avec colophane et archet
   - [ ]  Orgue avec pédale et ficelle
   - [ ]  Sanza
   - [ ]  Machine à pluie
   - [ ]  Machine à vent
   - [ ]  Clés
   - [ ]  Coquillages
   - [ ]  Machine à tonerre
   - [ ]  Daff
   - [ ]  Appeau
   - [ ]  Tube ré
   - [ ]  2 sticks et 2 mailloches
   - [ ]  Seau eau + éponge
   - [ ]  Talon aiguille
 - [ ] 3 housses costumes
   - [ ] ...
   - [ ] ...
 - [ ] Prothèse
 - [ ] Valise Accessoires jeu
   - [ ] ...
   - [ ] ...
 - [ ] Clavier
 - [ ] Tabouret de jeu
 - [ ] Corde et pancartes "spectacle en cours"

SPARE

 - [ ] Spare optiques
 - [ ] Spare miroirs
 - [ ] Spare gramophone
 
OUTILS/MAINTENANCE

 - [ ] Makita avec embouts et selection mèches
 - [ ] Caisse outil rouge
 - [ ] Sacs scotch/sangles/pinces/bijoute
 - [ ] Caisses visserie vrac
 - [ ] caisse maintenance plexi (colle, visserie 4mm)
 - [ ] Raclette, aspirateur
 - [ ] Poubelle
 - [ ] Sac chiffon et alcool

MERCH/DETENTE/ACCUEIL

 - [ ] 4 chaises longues
 - [ ] Table campings + 4 tabourets
 - [ ] Carton affiche, cartes postales et fanzines, caisse monnaie
 - [ ] Porte affiches/horaires
 - [ ] Caisse jouets optiques
 - [ ] Caisse bibliotheque
 - [ ] livres des confs

BRICOLAGE

 - [ ]  vis M4 + raclette à maroufler + vaporisateur
 - [ ]  carton gaufre

OPTION CAPTA

Image

- [ ] Appareil photo complet (4 cartes, 3 batteries, Chargeur, lecteur USBC)
- [ ] 3 optiques fixes + 1 Zoom
- [ ] Petit panneau LED + ses batteries + chargeur
- [ ] Pied camera
- [ ] Clamp, Rotule, pied manfroto (meme que pour EXPERIENCE 2250mm)
- [ ] Ronin
- [ ] Led Lenser

ordi

- [ ] Ordi complet + casque
- [ ] 2 disques durs

Son
- [ ] Schoeps + suspension
- [ ] 4 Cables
- [ ] pied de micro
- [ ] perchette + suspension
- [ ] HF Léon

OPTION CAMPING

- [ ] 2 ventilateurs Envol
- [ ] frigo
- [ ] 4 vélos
- [ ] une remorque
- [ ] 1 table camping + 1 chair
- [ ] réchaud à gaz
- [ ] bouteilles de gaz
- [ ] kit vaiselle
- [ ] auvent barnum
- [ ] lumière extérieure
- [ ] douchette
- [ ] hamac
- [ ] drap Léon + Ber + Nina
- [ ] gros bidon eau potable
- [ ] 2 matelas
- [ ] kit rallonge triplette camping
- [ ] rideaux camion
- [ ] bouilloire

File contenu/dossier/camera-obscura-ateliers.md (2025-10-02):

# Ateliers Camera Obscura

La Cie Nokill propose un atelier autour du spectacle *Camera Obscura* animé par deux de ses comédien·nes.

### En Pratique

* Nombre de Participant·es : 15 personnes ou 30 personnes avec un·e encadrant·e.
* Public : adultes et enfants à partir de 8 ans.
* Durée : entre 2 et 3 heures.
* Nombre d'intervenant·es : 2
* Matériel à fournir : Une paire de ciseaux par personne.
* Coût de l'atelier : Le devis peut être demandé par mail à cie@nokill.fr il comprend les salaires des intervenant·es et le prix du matériel fourni par la compagnie.

### Présentation

Cet atelier est une introduction au principe optique de la *camera obscura*. Malgré quelques éléments théoriques, il se concentre plus sur l'expérimentation pure à travers l'expérience de différentes *camera obscura* et la fabrication d'une caméra originale par participant·e.

### Objectifs

* Découvrir le principe de la *camera obscura*, un phénomène naturel utilisé jusque dans nos téléphones portables et se le réapproprier à travers une démarche low-tech. 
* Se construire une camera par personne en conciliant rigueur pour la réalisation technique et créativité pour la décoration.
* Repartir de l'atelier avec une *camera obscura* par personne.

### Déroulé

* Présentation rapide du spectacle (~10 min)
* Explication rapide du concept de *camera obscura* (~10 min) : sans trop entrer dans les détails techniques, on explique en quoi consiste le principe de la *camera obscura*, son histoire et ses applications dans la vie de tous les jours.
* Démonstration (~20 min) : un prototype amené par la compagnie est montré aux participant·es. Si l'espace le permet on peut aussi tenter l'expérience de transformer la salle dans laquelle se déroule l'atelier en une *camera obscura* géante !
* Fabrication (~60 min) : chaque participant·e se lance dans la fabrication de sa caméra en suivant les consignes données par les intervenant·es.
* Décoration (~30 min) : à l'aide de ciseaux de papier et de colle, chaque participant·e décore sa caméra de manière libre.
* Exploration (~30 min) : le groupe sort à l'extérieur pour regarder le monde à travers sa caméra.

### Les caméras fabriquées

Les caméras sont conçues à partir d'une boite ou d'un tube en carton. D'un côté de la caméra : une lentille (fournie par la compagnie). À l'intérieur un écran (en papier calque) sur lequel l'image de l'extérieur apparaît à l'envers. Sur les parois, on colle du papier découpé pour personnaliser la caméra. L'objet obtenu mesure une trentaine de centimètres de long.



### En amont des ateliers et du spectacle

Si vous souhaitez préparer l'atelier ou le spectacle en amont (facultatif) voici quelques pistes :

* Le fanzine : [https://camera-obscura.cienokill.fr/contenu/dossier/leprincipedelacameraobscura.pdf](https://camera-obscura.cienokill.fr/contenu/dossier/leprincipedelacameraobscura.pdf)
* Le site du spectacle : [https://camera-obscura.cienokill.fr/](https://camera-obscura.cienokill.fr/)

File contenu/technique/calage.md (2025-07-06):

## Calage des éléments optiques

### Contraintes liées au spectacle

- Les dimensions limitées de la remorque nous imposent un léger gradinage (20 cm par rang) et une rétroprojection. C'est avec cette configuration que nous obtenons le meilleur confort de vision pour une taille de remorque raisonnable.
- La régie : Nous voulons un espace de jeu d'1,4 m dans la remorque à l'arrière de l'écran.
- Nous voulons une taille d’image de 1,80 m × 1,31 m (format 1,37) sans trop de vignettage.
- Nous voulons utiliser plusieurs objectifs avec des focales différentes et des renvois d’angle, et alterner leur usage avec un système d'obturateurs manuels afin de reproduire l’illusion d’un montage type cinéma où plusieurs plans différents s’enchaînent.

### liste des objectifs et lentilles mis en oeuvre dans les essais :

Nous avons mené une longue recherche de lentilles adaptées à notre usage.

Objectifs et lentilles essayées et abandonnés :

- Process lens Fax Rokkor 150mm F4.5 : **Champs trop limité par le fût**
- Process lens Zeiss S-tessar 300 mm f5,6 : **Champs trop limité par le fût**
- Process lens Apo Ronar Rodenscock 360 mm - F9 : **Champs trop limité par le fût**
- Process lens Ilex Paragon 380 mm - F9 : **Champs trop limité par le fût**
- Process lens Nikon APO Nikkor 610 mm - F9 : **Champs trop limité par le fût**
- Process lens Wray Lustrar 1060 mm - F16 : **Champs trop limité par le fût**
- Lentilles brut d'opticien ø60 - 2000 mm / 1500 mm / 1000 mm / 750 mm : **Très bon résultats, mais pas assez lumineux**
- Doublet achromatique ø154 - 2250 mm et 750 mm : **Bonne luminosité mais trop d'abérations sur les bords**

Meilleur résultat a été obtenu avec la combinaison des lentilles suivantes :

- Lentilles brut d'opticien ø80 en polycarbonate - 800mm / 660mm : **Satisfaisant mais limite en luminosité**
- Lentilles "Full field diopters" (cinéma) ø138 - 2000mm / 1000mm : **meilleur compromis obtenu jusqu'à maintenant**

Solutions envisagées pour améliorer la luminosité des focales "courtes" :

- Fabrication sur mesure de Lentilles type ø138 Full field diopters - 800mm et 660mm

### Réglage de la mise au point

Le réglage de la mise au point sur le sujet qui se trouve à l’extérieur dépend directement de la distance objectif/écran (tirage) et de la focale.

Nous changeons de focale (changement d'objectif) pour changer radicalement la mise au point.

Nous déplacons la planchette (l'objectif) sur son axe pour un réglage plus fin de la mise au point. Ce mouvement est possible grace à l'utilisation d'un [soufflet](soufflet.md) d'un débatement de 40 cm.

Ces deux réglages (selection de l'objectif et translation de la planchette) sont commandés depuis la régie.

Les diagrammes suivants montrent la distance de mise au point en fonction de la distance de tirage pour les trois focales utilisées :

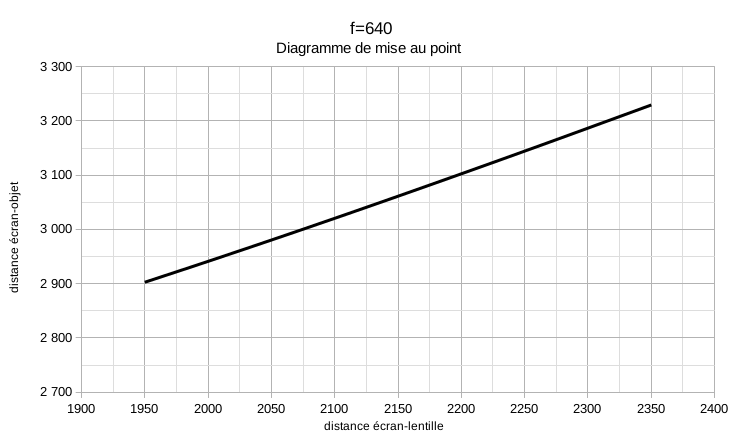
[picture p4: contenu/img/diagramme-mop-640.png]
Diagramme de mise au point f=640

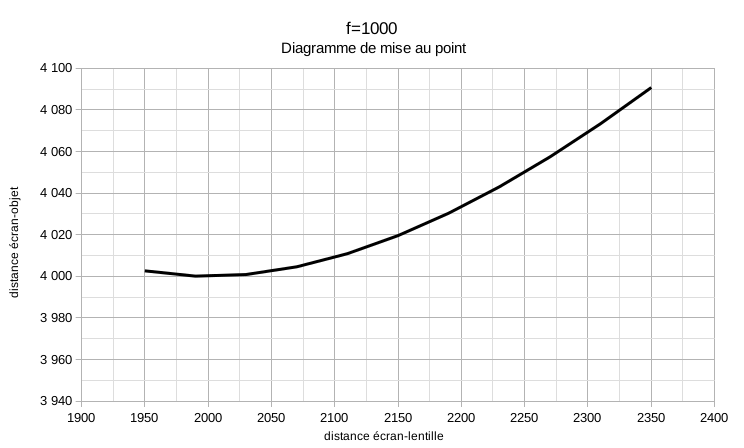
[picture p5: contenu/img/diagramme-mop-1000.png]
Diagramme de mise au point f=1000

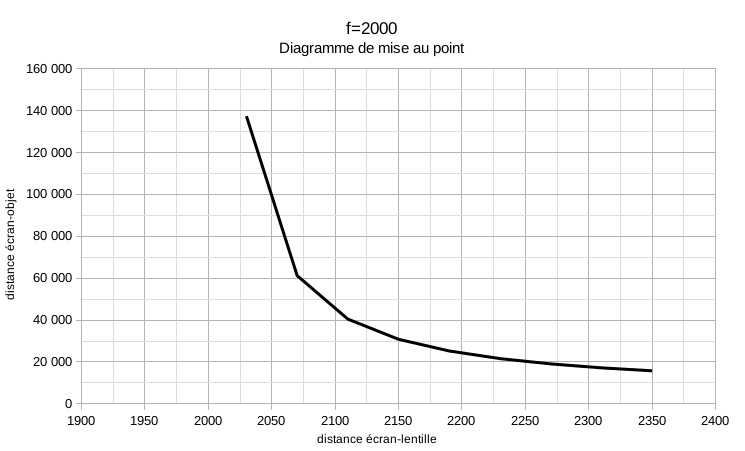
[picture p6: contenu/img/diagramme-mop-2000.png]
Diagramme de mise au point f=2000


### Angle de champ

Pour des raisons pratiques et artistiques nous avons fixé l’angle de champ horizontal à ~45°, ce qui correspond à un tirage de ~2,2 m pour notre écran de 1,8 m.

Cet angle (~45°) correspond à un objectif de 35mm en photo (format 24x36) et à un objectif de 24mm en cinéma (format 35mm).

Contre-intuitivement, le changement de focale n'affecte pas l'angle de champ si le tirage reste le même. L'angle de champ ne dépend que du tirage (distance lentille-écran).

Lorsque l'on déplace la planchette (translation) pour faire la mise au point, l'angle de champs varie (de +/- 3°) ce qui donne un effet *zoom*.

On a pris l'habitude de parler de l'angle entre la gauche et la droite de l'image (horizontal). Plus tard lors de discussions avec des opticiens on a compris qu'il pouvait être plus pertinent de parler de l'angle diagonal. Avec notre ratio d'image (1:1,37) un angle horizontal de ~45° correspond à un angle diagonal de ~55°.

### Valeur de plan

L'option choisie pour obtenir differentes valeurs de plan est de maintenir un tirage constant et de changer la focale.

Avec une focale égale à la distance de tirage, on aura le point à l'infini et donc un plan large.

Avec une focale plus courte, l'angle ne change pas mais la distance de mise au point diminue et un personnage pourra par exemple apparaître en gros plan.

Contre-intuitivement, les longues focales nous permetteront de faire les plans larges et les courtes focales, les plans serrés.

### Dynamiques

Avec une focale fixe, comment differentes valeurs changent si l'on change la distance lentille-écran.

Distance lentille-écran          | ↗ | ↘ |
---------------------------------|---|---|
Angle de champ                   | ↘ | ↗ |
Distance lentille-objet          | ↘ | ↗ |
Distance objet-écran avec f≳1000 | ↘ | ↗ |
Distance objet-écran avec f≲1000 | ↗ | ↘ |
Grandissement objet net          | ↗ | ↘ |
Grandissement objet fixe         | ↗ | ↘ |

Avec une distance lentille-écran fixe, comment differentes valeurs changent si l'on change la focale.

Focale                           | ↗ | ↘ |
---------------------------------|---|---|
Distance lentille-objet          | ↗ | ↘ |
Distance objet-écran             | ↗ | ↘ |
Profondeur de champ              | ↗ | ↘ |
Facteur d'éclairage              | ↗ | ↘ |
Vergence                         | ↘ | ↗ |
Grandissement objet net          | ↘ | ↗ |
Grandissement objet fixe         | = | = |
Angle de champ                   | = | = |

### Valeurs et formules

Valeurs :

- Largeur écran : 1,8 m
- Angle de champ horizontal : ~45°
- Distance lentille-écran (tirage) : 2,15 m

Formules :

- Relation de conjugaison : `1/2,15 + 1/d = 1/f`
- Distance objet en fonction de la largeur objet : `d ≈ l/(2*tan(22.5)) ≈ l/0.83`
- Focale en fonction de la distance objet : `f ≈ 1/(1/2,15 - 1/d) ≈ 1/(0.47-1/d)`
- Largeur objet en donction de la distance objet : `l ≈ d*(2*tan(22.5)) ≈  d*0.83`

### Tables

Version à jour de ces tableaux : [calcul_otpique.ods](calcul_otpique.ods)

#### Système

| | |
|---|---|
| **Ratio** | **1,37** |
| **Largeur écran** | **1800** |
| **Hauteur écran** | **1314** |
| **Diagonale écran** | 2229 |
| **Tirage** | **2150** |
| **Tirage min (t-)** | 1950 |
| **Tirage max (t+)** | 2350 |
| **Amplitude (amp)** | 400 |
| **CdC** | 0,5 |

#### Angle de champ

| angle | radian | degré |
| --- | --- | --- |
| **horizontal** | 0,79 | **45,4** |
| horizontal t-  | 0,86 | 49,6 |
| horizontal t+  | 0,73 | 41,9 |
| **vertical** | 0,59 | **34,0** |
| vertical t- | 0,65 | 37,2 |
| vertical t+ | 0,55 | 31,2 |
| **diagonal** | 0,96 | **54,8** |
| diagonal t- | 1,04 | 59,5 |
| diagonal t+ | 0,89 | 50,7 |

#### Détail lentilles souhaitées

| **Focale** | **2000** | **1000**  | **640** | **2000** | **1000**  | **660** |
| --- | --- | --- | --- | --- | --- | --- |
| **Diametre** | 154 | 154 | 154 | 80 | 80 | 80 |
| **Vergence** | 0,5 | 1,0 | 1,6 | 0,5 | 1,0 | 1,5 |
| **Ouverture** | 13,0 | 6,5 | 4,2 | 25,0 | 12,5 | 8,3 |
| **Ouverture conv** | f/11 | f/5,6 | f/4 | f/22 | f/11 | f/8 |
| **Facteur d’éclairage** | 0,52 | 0,26 | 0,17 | 0,27 | 0,14 | 0,09 |
| **Distances objet** | | | | | | |
| **Ditance objet-lentille** | **28 667** | **1 870** | **911** | **28 667** | **1 870** | **952** |
| Ditance objet-lentille t-  | #N/A | 2 053 | 953 | #N/A | 2 053 | 998 |
| Ditance objet-lentille t+  | 13 429 | 1 741 | 880 | 13 429 | 1 741 | 918 |
| Ditance objet-lentille amp | #N/A | 312 | 73 | #N/A | 312 | 80 |
| **Distance objet-ecran** | **30 817** | **4 020** | **3 061** | **30 817** | **4 020** | **3 102** |
| Distance objet-ecran t- | #N/A | 4 003 | 2 903 | #N/A | 4 003 | 2 948 |
| Distance objet-ecran t+ | 15 779 | 4 091 | 3 230 | 15 779 | 4 091 | 3 268 |
| Distance objet-ecran amp | #N/A | 88 | 327 | #N/A | 88 | 320 |
| **Profondeur de champ** | | | | | | |
| **H** | 616000 | 308000 | 197120 | 320000 | 160000 | 105600 |
| **PPN** | 27392 | 1858 | 907 | 26310 | 1848 | 944 |
| **DPN** | 30066 | 1881 | 915 | 31487 | 1892 | 961 |
| **PDF** | **2674** | **23** | **8** | **5178** | **44** | **17** |
| **Dimensions** | | | | | | |
| **Grandissement** | **0,07** | **1,15**  | **2,36**  | **0,07** | **1,15**  | **2,26**  |
| **Largeur objet** | 24 000 | 1 565 | 763 | 24 000 | 1 565 | 797 |
| **Hauteur objet** | 17 518 | 1 142 | 557 | 17 518 | 1 142 | 582 |
| Grandissement t- | #N/A | 0,95 | 2,05 | #N/A | 0,95 | 1,95 |
| Grandissement t+ | 0,18 | 1,35 | 2,67 | 0,18 | 1,35 | 2,56 |
| Grandissement amp | #N/A | 0,40 | 0,63 | #N/A | 0,40 | 0,61 |
| Grandissement obj fixe t-  | 0,07 | 1,04 | 2,14 | 0,07 | 1,04 | 2,05 |
| Grandissement obj fixe t+  | 0,08 | 1,26 | 2,58 | 0,08 | 1,26 | 2,47 |
| Grandissement obj fixe amp | 0,01 | 0,21 | 0,44 | 0,01 | 0,21 | 0,42 |

#### Résumé lentilles évoquées

| **Focale** | **2250** | **2000** | **1800** | **1500**  | **1200**  | **1000**  | **750** | **660**  | **640**  |
| --- | --- | --- | --- | --- | --- | --- | --- | --- | --- |
| **Distances objet** | | | | | | | | | |
| **Ditance objet-lentille** | **#N/A** | **28 667** | **11 057** | **4 962** | **2 716** | **1 870** | **1 152** | **952**  | **911**  |
| Ditance objet-lentille t-  | #N/A | #N/A | 23 400 | 6 500 | 3 120 | 2 053 | 1 219 | 998 | 953 |
| Ditance objet-lentille t+  | 52 875 | 13 429 | 7 691 | 4 147 | 2 452 | 1 741 | 1 102 | 918 | 880 |
| **Dimensions** | | | | | | | | | |
| **Grandissement** | **#N/A** | **0,07** | **0,19** | **0,43**  | **0,79**  | **1,15**  | **1,87**  | **2,26** | **2,36** |
| **Largeur objet** | #N/A | 24 000 | 9 257 | 4 154 | 2 274 | 1 565 | 964 | 797 | 763 |
| **Hauteur objet** | #N/A | 17 518 | 6 757 | 3 032 | 1 660 | 1 142 | 704 | 582 | 557 |

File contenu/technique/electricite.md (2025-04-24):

## Plan de l'installation électrique

plan

## Schéma de l'installation électrique 

schema

## Mesures

Ventilateur salle en série de 5 : 2,4 V - 75 mA - 0.18 W par ventil. (< 1 A les 10 ventil.)

- Résistance ventil 12 H
- En série 60 

- 5 ventilateurs en série = 0.2 A 
- 5 ventilateurs en série = 2 W

-> 0.75mm2 

25m de 0.75mm2

https://mon-fourgon-amenage.fr/electricite/section-de-cable

Ampoules GU5.3

Pour les blocs de secours : Ampoule LED SMD GU5.3 MR16 1,3W (9W) 80lm

- consomation totale 2.6 W
- cable 13m de 0.75mm2

Pour les services : Ampoule LED 24 SMD GU5.3 MR16 3W 280lm (120°)

- consomation 9 W
- 25m

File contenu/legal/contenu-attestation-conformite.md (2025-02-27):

---
type: legal
---

# Camera Obscura

## Contenu de l'attestation de conformité

Note : la numérotations des parties de ce document est celle de l'annexe 1 de l'arrêté du 4 mai 2023 portant expérimentation d'itinérance des établissements recevant du public.

### 1. Attestation de conformité

#### 1.1. Nom, raison sociale, adresse de l'établissement.

Nom de l'établissement recevant du public itinérant : CAMERA OBSCURA

CAMERA OBSCURA est une création de la Cie NOKILL.

SARL NOKILL  
Siège social : NOKILL — 6 rue du Dr Bastié — 81300 Graulhet  
SIRET :	39102418900055  
RSC : CASTRES 391 024 189  
Licence spectacle :	PLATESV-R-2022-004670 – Catégorie 2  

#### 1.2. Classement de l'établissement.

CAMERA OBSCURA est un Établissement Recevant du Public (ERP) itinérant du second groupe (catégorie 5).

#### 1.3. Description de l'établissement.

CAMERA OBSCURA est une salle de spectacle itinérante.

La **notice technique du fabricant** ci-jointe donne une description détaillée de l'établissement.

Les **PV de réaction au feu** ci-joints complètent cette description. 

##### 1.3.1. Plans de l'établissement proprement dit.

La **notice technique du fabricant** ci-jointe contient les plans de l'établissement.

##### 1.3.2. Plans des aménagements intérieurs possibles.

La **notice technique du fabricant** ci-jointe contient les plans des aménagements intérieurs possibles.

##### 1.3.3. Plans des installations électriques.

Veuillez trouver ci-joint le **plan des installations électriques**.

##### 1.3.4. Plans des installations de chauffage et de ventilation.

Veuillez trouver ci-joint le **plan des installations de ventilation**. Aucun chauffage n'est installé dans l'établissment. 

##### 1.3.5. Plans d'autres installations, techniques éventuelles.

La **notice technique du fabricant** ci-jointe contient les plans de toutes les installations techniques de l'établissemnet.

#### 1.4. Moyens de secours contre l'incendie.

##### 1.4.1. Inventaire du matériel.

Le document **Consignes de sécurité** ci-joint contient l'inventaire du matériel de secours contre l'incendie.

##### 1.4.2. Implantation des moyens d'extinction.

Le document **Consignes de sécurité** ci-joint contient un plan d'implantation des moyens d'extinction.

##### 1.4.3. Liste nominative du personnel chargé de la sécurité.

Voici la liste des personnes chargées de la sécurité de l'établissement :

- Léon Lenclos
- Bertrand Lenclos

##### 1.4.4. Consignes de sécurité.

Veuillez trouver ci-joint le document **Consignes de sécurité**.

#### 1.5. Contrôle de la solidité et de la stabilité à la conception, dans les conditions prévues à l'article 37 de l'arrêté du 25 juillet 2022 fixant les règles de sécurité et les dispositions techniques applicables aux structures provisoires et démontables.

En tant qu'ERP itinérant du second groupe, l'**attestation du fabricant** ci-jointe vaut Contrôle de la solidité et de la stabilité. 

#### 1.6. Etude de la sous-commission départementale pour la sécurité contre les risques d'incendie et de panique dans les établissements recevant du public pour les établissements du premier groupe et ceux du second groupe comportant des locaux d'hébergement définie au chapitre Ier du titre III du décret n° 95-260 du 8 mars 1995.

L'établissement n'est pas concerné en tant qu'ERP itinérant du second groupe ne comportant pas de locaux d'hébergements. (Voir l'article 4 de l'arrêté du 4 mai 2023 portant expérimentation d'itinérance des établissements recevant du public)

#### 1.7. Visite de réception et avis de la commission.

L'établissement n'est pas concerné en tant qu'ERP itinérant du second groupe ne comportant pas de locaux d'hébergements. (Voir l'article 4 de l'arrêté du 4 mai 2023 portant expérimentation d'itinérance des établissements recevant du public)

#### 1.8. Visa du préfet du département ou du préfet de police pour Paris.

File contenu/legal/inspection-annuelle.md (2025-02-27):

---
type: legal
---

# Camera Obscura

## Rapport d'inspection annuelle en exploitation

### Préambule

Ce rapport préremplit par NOKILL pour l'ensemble démontable CAMERA OBSCURA a été rédigé conformément à l'Arrêté du 25 juillet 2022 fixant les règles de sécurité et les dispositions techniques applicables aux structures provisoires et démontables.

Il a été rédigé en suivant le modèle de rapport de vérification après montage qui figure à l'annexe VI de cet arrêté.

Il doit être complété et signé par un·e technicien·ne comptétent·e après que les vérifications exhaustives soient réalisées par le ou la technicien·e compétent·e à l'issue d'une visite effectuée sur l'installation.

### Personne en charge de la vérification

**Nom et Prénom :** <input>  
**Courriel :** <input>  
**Téléphone :** <input>

### L'événement

**Nom de l'évennement :** <input>  
**Adresse :** <input>  
**Dates :** <input>  
**Description sommaire :** <input>

### La compagnie

La Cie NOKILL est l'exploitant et l'installateur de l'Établissement itinérant recevant du public CAMERA OBSCURA.

**Nom :** NOKILL   
**Adresse :** 6 Rue du Docteur Bastié — 81300 Graulhet 
**Courriel :** cie@nokill.fr
**Téléphone :** 0609903897

**Responsable du montage :** Léon Lenclos  
**Téléphone :** 0627656833  
**Fonction :** artiste / référent technique

### Documents consultés 

- Notice technique du fabricant ;
- plan d'implantation ;
- rapport de vérifications des installations électriques ;
- plan des installations électriques ;
- attestation de bon montage ;
- Consignes de sécurité ;
- PV de réaction au feu.

### Caractéristiques de l'ensemble démontable

__TODO: Vérifier toutes les dimensions de ce chapitre__

**Dénomination de l'ensemble démontable :** Camera Obscura
**Fabriqué par :** NOKILL  
**Descriptif sommaire :** Salle de spectacle itinérante  
**Catégories :**

- Établissement Itinérant Recevant du Public du second groupe (catégorie 5)
- Ossatures classées OP1 et OS1

**Description des tribunes :**

Gradins à l'intérieur de la remorque équipés de sièges.

- hauteur du plus au rand par rapport au plancher : 640 mm;
- ouverture : 2250 mm
- nombre de travées : 5
- nombre de rangs : 5 
- l'effectif maximum admissible : 25

**Déscription de la structure scénique :**

Structure tubulaire en aluminium fixée à la remorque autour d'une scène composée de deux praticables et équipée d'escaliers de service.

Dimension de la structure tubulaire :

- Ouverture : 2600 mm
- Profondeur : 2800 mm
- Hauteur : 3000 mm

**Description des accès public :**

__TODO: Faire la description des accès public__

**Description du réflecteur :**

Structure mobile sur roues.

- Dimensions au sol : 2000 × 2000 mm;
- Hauteur : 3000 mm;

### Constatations

**TODO: Vérifier si on est bon sur tous ces elements**

Chaque partie fait l'objet de l'un des avis suivants :

- Satisfaisant (S) : la constatation S valide la conformité de l'ensemble démontable. Elle valide également le constat d'adéquation de l'ensemble démontable avec le dossier de sécurité, le bon état de conservation de ses éléments constitutifs, le bon assemblage de son ossature, les points d'appui au sol, etc.
- Non satisfaisant (NS) : la constatation NS sanctionne les distorsions de conformité entre l'ensemble démontable monté et les règles de sécurité et les dispositions techniques qui lui sont applicables.
- Sans objet (SO) : la constatation SO est émise lorsque l'ensemble démontable n'est pas concerné par certaines dispositions ou qu'il ne comprend pas d'installation technique mentionné dans l'arrêté.
- Hors mission (HM) : la constatation HM s'applique aux articles des règles de sécurité et des dispositions techniques applicables à l'ensemble démontable dont la vérification n'a pas été confiée au vérificateur.
Les constatations portent sur tous les articles mentionnés dans le tableau ci-dessous.

Les constatations NS font l'objet d'un commentaire explicatif. Une liste complète de ces constatations, de leurs commentaires numérotés en une série unique, et de l'identification précise du matériel ou de l'équipement concerné, est établie en début ou en fin de rapport avant l'avis final.

Les autres constatations peuvent faire l'objet d'une explication ou d'une observation complémentaire.

Le tableau ci-dessous suis le modèle de l'annexe VI, mais a été modifié pour correspondre au cas particulier d'un ensemble de structures catégorisées OS1 et OP1, au cas particulier d'un établissement itinérant recevant du public du second groupe au sens de l'arrêté du 4 mai 2023 portant expérimentation d'itinérance des établissements recevant du public et aux spécificitées de l'ensemble visé par se rapport.

Note : la colonne "art." donne la référence de l'article de l'arrêté concerné par chaque point examiné.

|art.|Points examinés|Constatations et commentaires|S|NS|SO|HM|
| - | --- | ---|-|--|--|--|
|3| Principes généraux | | | | | |
|5| Adéquation de la capacité d'accueil | | | | | |
|6| Lieu d'implantation | | | | | |
|7| Adéquation avec le sol : Etat du sol, calage, plaque de répartition,… | | | | | |
|9| Identification ; Marquage : Marque, modèle, Année,… | | | | | |
|10| Respect des charges d'exploitation et charges climatiques | | | | | |
|11| Adéquation, état et assemblages des ossatures| | | | | |
|12| Etat et assemblage des planchers : Etat, jeu, décalage,… | | | | | |
|13| Etat et assemblage des contremarches : Etat, jeu, décalage,… | | | | | |
|14| Places assises pour les gradins : Nombre, implantation,… | | | | | |
|16| Dégagements : Nombre, qualité, répartition et balisage | | | | | |
|18| Dessous : Inaccessible au public, potentiel calorifique,… | | | | | |
|19| Escaliers et rampes accessibles au public : Qualité, état, assemblage,… | | | | | |
|20| Garde-corps : Qualité, état, assemblage,… | | | | | |
|21| Sièges et bancs fixes : Qualité, état, assemblage,… | | | | | |
|22| Sièges et bancs non fixes : Nombre | | | | | |
|23| Sièges : Caractéristiques, PV de réaction au feu | | | | | |
|25| Impact sur le niveau de sécurité du lieu d'accueil | | | | | |
|26| Examen d'adéquation : accroches, accessoires de levage | | | | | |
|27| Habillages : PV de réaction au feu, état, assemblage,… | | | | | |
|29| Les câbles électriques ne font pas obstacle à la circulation des personnes | | | | | |
|29| Présence du plan des installations électriques avec la localisation des dispositifs de coupure d'urgence. | | | | | |
|30| Présence du rapport de vérification des installations électriques. | | | | | |
|31| L'éclairage de sécurité est en adéquation avec les conditions d'exploitation. | | | | | |
|32| Modalités d'évacuation (existent ou pas)| | | | | |
|33| Diffusion de l'alarme et de l'alerte. | | | | | |
|34| moyens d'extinction | | | | | |
|36| Notices techniques : Présence | | | | | |
|47| Ensemble démontable existant : Avis solidité | | | | | |
|48| Ensemble démontable existant : Marquage | | | | | |

### Avis final

Ce rapport est rendu suite à la visite de l'ensemble démontable et après vérification de de la conformité de toutes les parties de l'ensemble démontable.

**Date de la vérification :** <input>  
**Date du rapport d'inspection :** <input>  
**Nombre de pages du rapport :** <input>  

**Observations :**

<input class=long>

**L'avis final est :** (Rayer la mention inutile)

- Favorable à l'exploitation de l'ensemble démontable 
- Défavorable à l'exploitation de l'ensemble démontable

**Nom et prénom du ou de la technicien·ne compétent·e ayant effectué la vérification :** <input>

Fait à <input>, Le <input>.

Signature du ou de la technicien·ne compétent·e :

**ATTENTION CE DOCUMENT EST EN COURS DE RÉDACTION NE PAS SIGNER**

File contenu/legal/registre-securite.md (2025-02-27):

---
type: legal
---

# Camera Obscura

## Registre de sécurité

Ce registre de sécurité est composé par NOKILL en tant qu'exploitant de CAMERA OBSCURA conformément à l'annexe I de l'arrêté du 4 mai 2023 portant expérimentation d'itinérance des établissements recevant du public. 

Il est composé de deux parties :

- [**L'attestation de conformité**](contenu-attestation-conformite.md) rassemble des informations et des éléments descriptifs concernant l'ERP, sa nature, sa sécurité et sa solidité, la conformité doit être attestée chaque année par le prefet.
- [**Le registre d'exploitation**](contenu-registre-exploitation.md) permet de faire l'historique des modifications et des vérifications de l'ERP pendant l'exploitation.

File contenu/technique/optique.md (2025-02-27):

# Principe optique

## Le principe de la camera obscura

Le spectacle consiste à inviter le public à l'interieur d'une chambre noire géante. La chambre noire (camera obscura en latin) est le principe optique à la base du fonctionnement de l'œil, des cameras et des appareils photos. C'est le procédé par lequel une image apparait sur un écran, quand on se trouve dans milieu sombre avec une petite ouverture donnant sur un milieu lumineux.

## Découverte de la camera obscura

La chambre noire est un dispositif étonnement basique et simple à mettre en oeuvre. Dans sa forme la plus primitive c'est donc :

- un espace obscure (intérieur)
- un espace éclairé (extérieur)
- un trou entre les deux espaces

Réunir ces conditions suffit pour que la magie opère et qu'une image de l'extérieur soit projetée à l'intérieur.

Le dispositif est tellement simple qu'il peut apparaître par hasard. Avec un peu de chance est d'attention il est très probable qu'au cours de sa vie on rencontre plusieurs camera obscura naturelles. Comme en se réveillant tard dans une chambre à coucher plongée dans l'obscurité dont l'un des volets est percé, le soleil qui brille déjà fort à l'exterieur et on découvre au plafond l'image en couleur et en mouvement des passants dans la rue.

Frappé par la rencontre d'une camera obscura naturelle et motivé par l'envie de pouvoir revivre l'expérience à volonté, on peut avoir envie d'en fabriquer une artificielle. On découvrira alors qu'un très grand nombre de variables sont en jeu, toutes plus ou moins dépendante les unes des autres et déterminante pour la qualité de l'expérience.

## Complexité liés à la fabrication d'une camera obscura

Malgré la simplicité du principe de base décrit ci-dessus. Quand on veut construire une chambre noire avec une image grande, nette et lumineuse, on se heurte à plusieurs problèmes pratiques et limites théoriques dus au grand nombre de paramètres et à l'interdépendance de certains de ces paramètres.

Ce diagramme résume les liens entre nos besoins et les différentes variables d'ajustement :

{% include pdf.html url="/contenu/img/systeme-optique-besoins-et-variables.pdf" %}

Lien du diagramme (modifiable) : [tldraw](https://www.tldraw.com/r/PTp9ABojWfnR5E5pJ1Lpf?viewport=-3313,-959,5296,2475&page=page:Pfaj0dIyyjuVpmR7na4eN)

## Principe optique

 plan d'ensemble

A : Acteur	S : Système optique	O : Opérateur		E : Écran	R : Regardeur

t : tirage	p : profondeur		h : hauteur		l : largeur	d : diamètre de l’écran

## Premiers essais

Les premiers essais ont été réalisés avec un process lens Zeiss tessar 5,6/360 chiné sur ebay.

Les process Lens étaient construits à l'origine pour des dispositifs de reproduction d’image et sont aujourd’hui utilisés par des photographes qui font du grand et du très grand format. Avec cet objectif, nous sommes arrivé à projeter une image de 60 cm de diamètre. La netteté à l'infini est obtenue en plaçant l'écran à environ 40 cm de la lentille frontale. L'image est magnifique, relativement lumineuse et incroyablement définie. Bien entendu elle est inversée. Suite à ces premiers test, nous avons identifié plusieurs problèmes à résoudre.

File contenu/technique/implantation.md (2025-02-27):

# Schéma d'implantation

Le schéma d'implantation est un document que l'on créé pour chaque lieu ou on implante Camera Obscura, le document montre la position de l'ensemble sur une carte du lieu.

Ces documents peuvent être trouvés dans le [répertoire des plans](https://github.com/LeonLenclos/camera-obscura/tree/main/contenu/plans) et s'appellent `implantation-carte-[NOM_DE_L_ORGA].pdf` (par exemple : [implantation-carte-mima.pdf](https://camera-obscura.cienokill.fr/contenu/plans/implantation-carte-mima.pdf)).

## À propos de l'implantation

L'implantation de la remorque nécessite un espace plat de 10×15m.

L'orientation se décide en fonction de la course du soleil pour avoir un éclairage optimal à tous les horaire de jeu.

Il y a deux axes de prise de vue, axe frontal et axe latéral la médiane entre ces deux axes doit être orienté au nord. La direction de l'axe Latéral est déterminé par la position du miroir d'Amici. On oriente l'avant de la remorque vers le nord-est si le miroir est à l'ouest et vers le nord-ouest si le miroir est à l'est :

La pente maximum qu'on a testé c'était 2%

## Schéma génériques

### Schéma de l'orientation nord-est

{% include pdf.html url="https://camera-obscura.cienokill.fr/contenu/plans/implantation-orientation-NE.pdf" %}

### Schéma de l'orientation nord-nord-est

{% include pdf.html url="https://camera-obscura.cienokill.fr/contenu/plans/implantation-orientation-NNE.pdf" %}

### Schéma de l'orientation nord-ouest

{% include pdf.html url="https://camera-obscura.cienokill.fr/contenu/plans/implantation-orientation-NO.pdf" %}

## Créer un schéma d'implantation à partir d'un plan OSM

1. Aller sur [OpenStreetMap](https://www.openstreetmap.org/)
2. Taper les coordonées du lieu dans le champs de recherche et cliquer sur *Aller*
3. Cliquer sur le bouton Partager (à droite)
4. Indiquer le format **PNG** 
4. Indiquer l'echelle `1280` (Echelle reelle **1:1000**) ou `640` (Echelle reelle **1:500**)
5. Cocher Définir les dimensions personnalisées et ajuster le cadre
6. Enregistrer l'image dans plans/ avec pour titre `carte-[ORGA].png` et l'importer sous Inkscape dans `plans/implantation-carte.svg`
7. Définir la position et l'orientation de la zone d'implantation avec l'outil symetrie
8. Enregistrer sous `plans/implantation-carte-[ORGA].svg` et `plans/implantation-carte-[ORGA].pdf`

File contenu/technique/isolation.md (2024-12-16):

# Gestion de la chaleur à l'intérieur de la remorque

Camera Obscura est un spectacle de rue, diffusé en été, et nécessitant une bonne luminosité extérieure. La remorque est donc placée en plein soleil et le problème du confort thermique des spectateurs est un point essentiel.

Nous trouvons des solutions techniques dans les domaines suivants :

## Isolation

### Surface de la remorque

La remorque est majoritairement blanche pour refléter un maximum du rayonnement solair.

### Isolation thermique

Utilisation d’un isolant efficace, de faible épaisseur et de faible poids. Les contraintes de dimension (largeur) et de jauge (24 spectateurs) nous imposent une épaisseur d’isolant réduite.

Épaisseur de l'isolant : 100 mm.

#### Sandwich

 Pour l'isolation des parois et du plafond, de l'exterieur à l'interieur :

| materiaux | épaisseur | rôle | lien |
|---|---|---|--|
| Tôle alu laquée | 1.5mm | Finition + Rigide + Réflecteur | [lien](https://e-steel.arcelormittal.com/FR/fr/Aluminium/T%C3%B4le-Aluminium/T%C3%B4le-aluminium-laqu%C3%A9e/T%C3%B4le-aluminium-laqu%C3%A9e-poudre/p/000000000002120158) |
| Panneau coton METISSE | 100mm  | Isolant | [lien](https://www.eco-logis.com/boutique/isolation/laine-coton-panneaux/?attribute_conditionnement=BUITEX) |
| Protecflam HDF | 2,5mm  | Rigide |[lien](https://protecflam.fr/fibroflam-panneaux-ignifuges/73-fibroflam-igni-m-protection-ignifuges-hdf.html) |
| Kalmut  | 2mm | Finition | [lien](https://www.azur-scenic.com/produit/kalmuk/) |

L'épaisseur totale réelle est de 104,5mm

Pour le faux plafond

| materiaux | épaisseur | rôle | lien |
|---|---|---|--|
| Tôle alu laquée | 1.5mm | Finition + Rigide + Réflecteur | [lien](https://e-steel.arcelormittal.com/FR/fr/Aluminium/T%C3%B4le-Aluminium/T%C3%B4le-aluminium-laqu%C3%A9e/T%C3%B4le-aluminium) |
| Panneau coton METISSE | 100mm  | Isolant | [lien](https://www.eco-logis.com/boutique/isolation/laine-coton-panneaux/?attribute_conditionnement=BUITEX) |
| Protecflam HDF | 2,5mm  | Rigide |[lien](https://protecflam.fr/fibroflam-panneaux-ignifuges/73-fibroflam-igni-m-protection-ignifuges-hdf.html) |
| Air | 100mm ? | Aération | |
| Protecflam HDF | 2,5mm  | Rigide |[lien](https://protecflam.fr/fibroflam-panneaux-ignifuges/73-fibroflam-igni-m-protection-ignifuges-hdf.html) |
| Peinture noire  | | Finition | |

Pour l'isolation du sol

| materiaux | épaisseur | rôle | lien |
|---|---|---|--|
| Tôle galva brut | 0,8mm | Rigide |  |
| Panneau coton BUTEX | 100 mm  | Isolant | [lien](https://www.eco-logis.com/boutique/isolation/laine-coton-panneaux/?attribute_conditionnement=BUITEX) |
| OSB | 15mm | Rigide | [lien](https://www.panofrance.fr/p/panneaux/panneau-kronoply-osb3-milieu-humide-250x125cm-15mm-A1012584) |
| Moquette | 6 mm | Finition + Isolant | [lien](https://www.saint-maclou.com/produit/moquette-velours-roxane-col-noir-rouleau-4-00-m-002109-00098#photos) |

#### Overtures

Bouches :

- Bouche d'aeration du faux plafond à l'exterieur
- Bouche d'aeration du faux plafond à l'interieur
- Bouche d'aeration de l'interieur à sous les gradins
- Bouche d'aération de sous les gradins à sous la remorque

Vitres :

- 10 hublots (2 vitres de 4mm par hublot)
- Vitre de projection  (6mm)

Portes :

- Portes public
- Trappes régie
- Trappes arrière

## L'air dans la remorque

On va aborder 3 axes :

- On veut que l'air soit bien renouvelé pour éviter que l'atmosphère soit "étouffante".
- On veut que la température de l'air soit basse pour qu'il fasse pas trop chaud.
- On veut des petits courants d'air pour donner une sensation de frais aux gens.

## Schéma

schéma de l'aération et isolation de la remorque

- En rouge : L'épaisseur d'isolant.
- Flèches : Direction de l'air à chaque endroit où une bouche d'aération permet une circulation de l'air.
- Zones :
  1. Sous la remorque : l'endroit ou l'air est le plus frais (voir : [raffraichissement-de-lair](Raffraichissement de l’air))
  2. Une bouche d'aération laisse entrer l'air de l'extérieur vers l'interieur.
  3. Sous le gradin : le système de ventilation (voir : [renouvellement-de-lair](Renouvellement de l’air))
  4. Sous le gradin : l'endroit le plus frais de la remorque, une bouche sous chaque paire de siège envoie l'air aux pieds des spectateurs.
  5. La salle : au plafond des bouches laissent s'échapper l'air par le faux-plafond, Des petits ventilateurs peuvent être placés pour donner une sensation de frais (voir :  [sensation-de-frais](Sensation de frais)).
  6. La régie.
  7. Le faux plafond : un large conduit de 80mm de hauteur qui permet d'évacuer l'air sans faire entrer de lumière.
  8. Évacuation : l'air ressort par le haut.

### Renouvellement de l’air

Mise en place d'un système de renouvellement de l’air à l’intérieur de la remorque. Système d'extraction d'air composé d'un faux-plafond équipé de bouches d'aération qui débouchent sur l'extérieur, à l'arrière de la remorque.

L'arrivée d'air se fait par le sol à travers des bouches d'aération individuelles sous chaque siège.

Cette implantation permet une convection naturelle qui est utile, mais pas suffisante par grandes chaleurs.

En cas de grandes chaleurs, on ajoute donc 2 grands ventilateurs (ventilateurs de voiture sur batterie) sous le gradin, sur la grille d'entrée de l'air.

### Raffraichissement de l’air

L'air arrive de sous la remorque, c'est naturellement l'endroit où l'air est le plus frais.

Pour qu'il soit encore plus frais on mouille le sol. Si c'est de l'herbe on mouille l'herbe et ça marche super bien. Sinon on a aussi des gros tapis qu'on place sous la remorque et qu'on mouille et ça marche bien aussi.

L'idée de rafraîchir l'air sur le trajet du flux avec un matériaux humidie, s'inspire des climatisations pour chapiteau, où un flux d'air traverse un ballot de paille humide. À un moment on a un peu essayé un truc comme ça mais c'était pas si efficace et ça sentait très fort...

Voir : RAE, [rafraîchisseur d'air évaporatif (wikipedia)](https://fr.wikipedia.org/wiki/Refroidisseur_par_%C3%A9vaporation)

### Sensation de frais

Avoir un petit courant d'air sur sa peau c'est ce que les gens cherchent en utilisant un ventilateur ou un éventail par exemple. Ça ne rafraîchis pas l'air mais ça déplace la fine couche d'air tiède-humide qui flotte autour de notre corps et ça fait du bien.

On a donc placé un ventilateur à l'intérieur orienté directement sur le public.

## Améliorations envisagées pour l'été 2025

### Doubler les ventilateurs sous les gradins 

Au lieu de deux ventilateurs pour le renouvellement de l'air on passera à 4 ventilateurs.

### Amélioration sensation de frais

Au lieu d'un ventilateur au sol pour la sensation de frais, on installera une série de ventilateurs plus petits en hauteur, plus précisément dirigés sur les differentes zones du gradins

## Amélioration évoquées pour le long terme

Les hélices des ventilateurs de renouvellement de l'air pourraient être entraînés par un système de poids entraînant un engrenage et remonté entre chaque représentation. Un système de poulies peut permettre de démultiplier la longueur de corde.

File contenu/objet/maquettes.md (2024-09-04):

# Maquettes (abandonné)

Deux paysages de route en campagne, dans deux saisons (printemps/hiver).

Notes :
- Échelle 1:32 (échelle I).
- Trouver 11 voitures et 1 camion, tout en double.
- Peut-être effet de perspective ?
- La maquette est inclinée à 45° et à l'envers.
- Sol : environ 1000×1000 mm ; réfléchir à une forme en trapèze (champs de vision) pour alléger.
- Animations des voitures dans la première maquette et d'un perso dans la deuxième
- à voir le problème de l'éclairage (reflecteur)

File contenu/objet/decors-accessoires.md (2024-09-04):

# Décors

Les décors sont réfléchis pour être filmés au 1000mm.

## Dimensions

Le décors doit être à 300 du sujet. Avec la lentille de f=1000 mm le sujet est à 1870 mm de la lentille, le décors est donc à 2170 mm. à 2170 le plan visible est de 1817×1326. En prenant ~100 de marge de chaque côté et en arrondissant on a **une feuille de décors de 2000×1500**.

Voici le tableaux des dimensions que doivent avoir les feuilles de décors en fonction de la distance relative au sujet

| distance relative | distance lentille | surface visible | avec marge de 100 |
| --- | --- | --- | --- |
| 0 | 1870 | 1565×1142 | 1765×1342 |
| 100 | 1970 | 1649×1203 | 1849×1403 |
| 200 | 2070 | 1733×1264 | 1933×1464 |
| **300** | 2170 | 1816×1326 | **2016×1526** |
| 400 | 2270 | 1900×1387 | 2100×1587 |
| 500 | 2370 | 1984×1448 | 2184×1648 |
| 600 | 2470 | 2067×1509 | 2267×1709 |
| 700 | 2570 | 2151×1570 | 2351×1770 |
| 800 | 2670 | 2235×1631 | 2435×1831 |

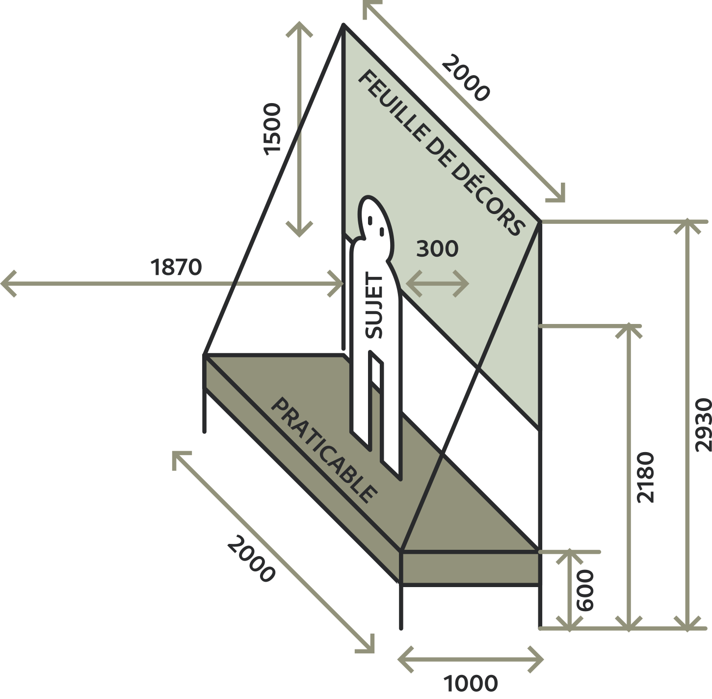
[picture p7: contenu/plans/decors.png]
Structure décors


## Fond noir

- Scratché sur le dos du réflecteur.

## Chambre

Une feuille de 2000×1500 mm. Tous les accéssoires sont fixés dessus :

- Moquette
- Matelas (en mousse légère).
- Litterie : Drap Drap house couette oreillée.
- Table avec livre et lampe.
- Vetements qui traînent.
- etc.

# Décors abandonnés 

## Cuisine

Feuille de décors avec du papier-peint 2000×1500 mm
Ou portant à roulette avec tissu tendu de 2000×1500 mm
Table avec nappe et dossier de chaise réfléchis pour un faux-assis (debout sur le praticable

## Mur de brique

En faux-vertical : au sol comme si adossé à un mur.
Rouleau de lino mur de brique.
Peut-être affiche de pub pour le feu sans fumée, grafiti du futur, ou autre.

## Voiture

Voiture jouée en debout faux assis.
Une feuille de décors avec en trompe l'oeil :
  - Portière
  - Tableau de bord
  - Parbrise + vitres
Un volant sur pied.
La feuille de décors est recto verso pour contre-champ.
Ou alors une autre feuille de décors pour un plan de face.
Effets :
- Paysage qui défile (branches d'arbres à la main)
- Goutes d'eau sur la vitre

# Accessoires

- Cuillère
- Verre d'eau
- Lunettes de retournement de la vision
- clavier

Effets :
- Paillette (à trouver)
- Buée (à trouver)

## Prothèse

Fausses mains, journal, buste, épaule et cou
Manipulation possible des mains (légère souplesse)
Pour masquer le vrai corps : col roulé ou tissu noir tenu à la main.

## Journaux

1. Maqueter un faux-journal qui s'appelle "Le journal".
2. L'imprimer en 1 exemplaire.
2. Prendre en photo la personne très influente qui le tient à l'envers.
3. Maquetter un autre numéro de "Le journal". Avec une photo en une.
4. L'imprimer en 10 exemplaires environ. Et aggrandir un détail du journal sur une feuille de 1000 × 730 mm.

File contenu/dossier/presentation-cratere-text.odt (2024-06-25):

Slide 1 : Présentation

I am Léon from the company Nokill. I am an actor and author and today I'm here to talk to you about our new project : Camera Obscura.

I will start by describing the show (wich has a quite unusual form) and then i will explain the reasons why I'm here.

Slide 2 : Calendar

So Camera Obscura is a travelling optical theater, designed to be played in public spaces, that we like to refere as post-cinema.

We are currently at the end of two years of creation, with the premiere scheduled in a 1 month's time.

Slide 3 : Camera Obscura principle

The ambition of this project is to place the public inside a camera obscura.

The camera obscura is an optical principle whose discovery is difficult to date, but traces of it can be found as far back as the 4th century before christ.

It is as simple as a dark room with a pinhole or a lens that opens to a brigh outside. When inside this setup, we can see an image of the outise projected inside the room.

So this principle is nothing new, it is the basis of how our vision works, but also how a camera works. We just built it big enough to put people inside.

The idea behing our show is to use this princile along with a range of mechanical, optical and acoustic devices, to create the illusion of a movie projection, without using any form of electricity.

We aim to reproduce the codes of the cinema: editing, voice-over, soundtrack, special effects, cross-fades, using of different field sizes, end credits and so on. But without using its technique.

Slide 4 : our camera

In concrete terms, this is a trailer with 21 seats, where viewers sit facing a 2 meters wide screen to watch a 30 minute film. The show is performed 4 times a day.

Inside the trailor, behind the screen, there is a person that make, music, sound effecs and voice-over, but who also opens, closes and switches lenses.

Outside, two comedians act out the scenes in person or by activating animated transparent plates to project cartoon scenes.

Slide 5 : memories from the future

The film shown is called Memories From The Future, it is a kind of sketch film with about 20 vague visions of different possible futures. These are anticipation stories, but no science fiction. Rather both strange and banal stories from a future that seems both near and far from us.

Slide 6 : show translation

With our theater company we have been doing shows since 2016. Some of them have been played a lot, some still do. but only in France or french speaking countries.

In our shows, text and orality play a central role. And as you can guess hearing me speaking, I'm not fluent in english. And even if I can try to make myself understood in a context like that, performing in a language other than French would be a real challenge for us.

Camera Obscura has a lot of text too, but it takes the form of a film. And a film can have subtitles !

One of the first questions we ask ourself about translating a show into a new language is whether the number of performances scheduled in that language is sufficient to justify the translation work, which can be very time-consuming, especially in languages we don't speak.

In addition to being consistent with the cinematic form of our show, the idea of using subtitles to translate our show would greatly reduce the time and cost of a new translation. We could then translate our show into a new language even for a few performances.

We think we'll be able to setup the subtitling system by 2025, but first we'd like to know if some professionals might be interessed. We are thinking in particular about neighbouring countries. Don't hesitate to come back to me, whether you're interested or not.

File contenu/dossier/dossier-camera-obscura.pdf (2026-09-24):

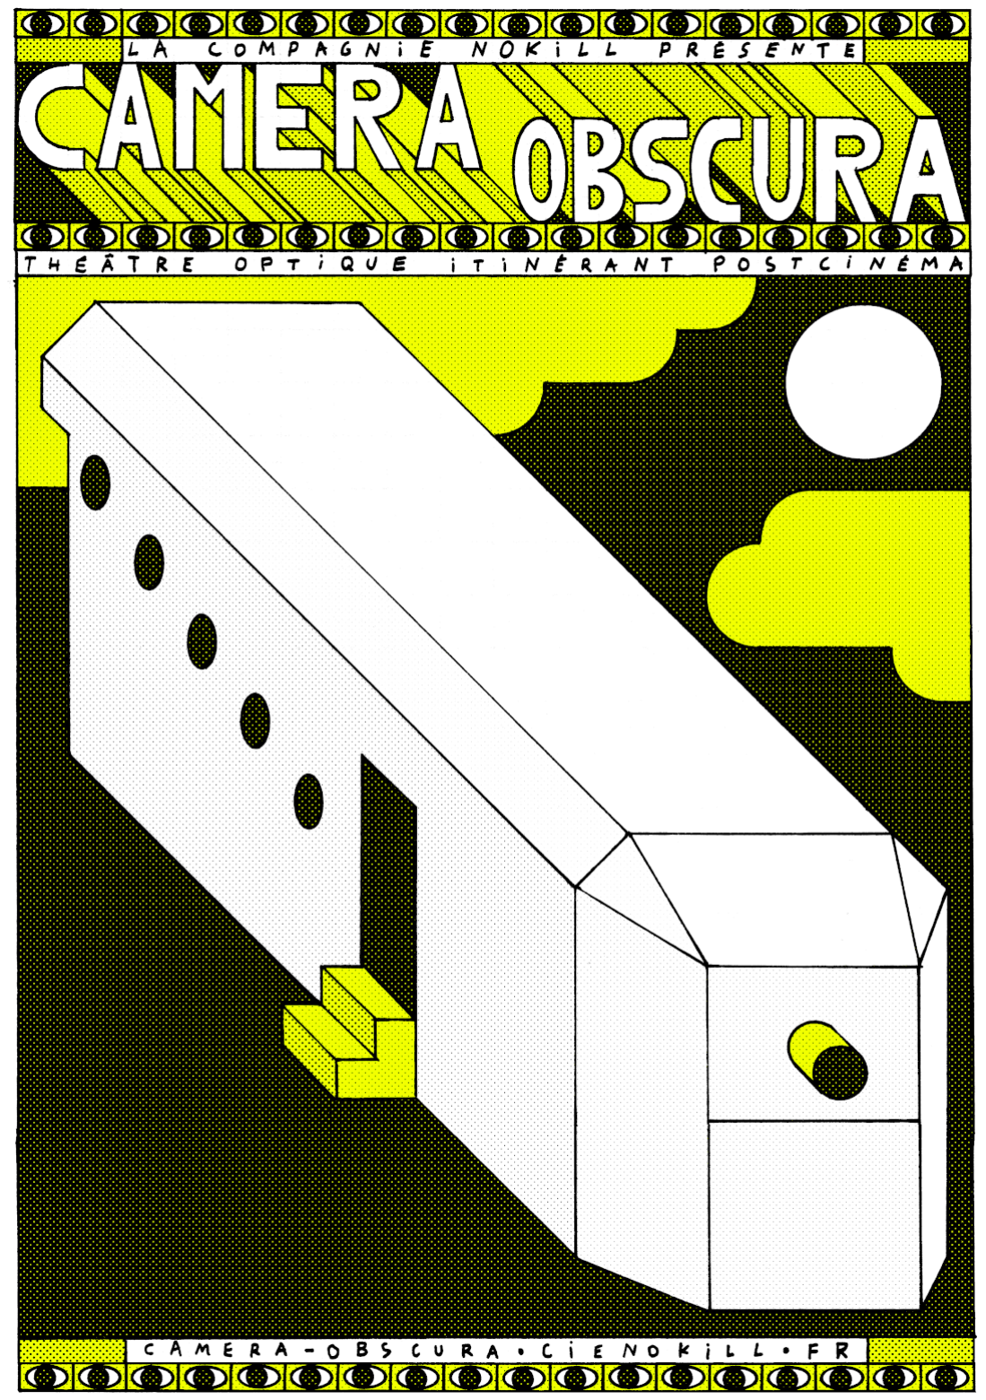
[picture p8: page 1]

# Camera Obscura

éâtre optique post-cinéma Cie NOKILL
Dossier de présentation

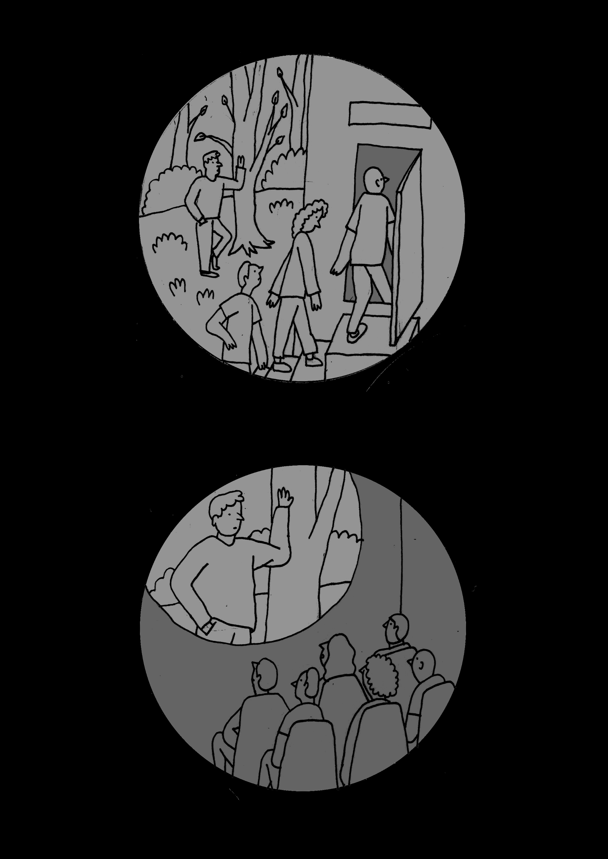
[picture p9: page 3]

Texte d’introduction dit par Léon à l’entrée du public dans la Camera Obscura

Bertrand est en train de s’installer parmi ses instruments, derrière l’écran.

### Lucile est sortie de la remorque, elle est allée finir de préparer les éléments de machinerie que vous avez vu dehors en

arrivant.

### Je vais vous demander de petit à petit fermer les hublots de chaque côté du gradin. L’idée c’est d’entrer, petit à petit dans

l’obscurité.

### Pendant les 30 prochaines minutes, tous les trois, on va activer différents dispositifs optiques, acoustiques et mécaniques pour

fabriquer un film qui sera projeté sur cet écran.

### C’est un film qui est produit en direct et sans utiliser du tout

d’électricité, pas de micro, pas de caméra, pas de projecteur.

Le principe optique qui fait que vous voyez une image sur l’écran ça s’appelle la camera obscura. C’est un phénomène qui se produit quand on est dans une pièce très obscure et qu’il y a dans le mur un petit trou ou une lentille qui donne vers un environnement très lumineux. and on est dans ces conditions, on voit, comme ça, une image de l’extérieur

apparaître à l’intérieur.

Cee image est assez sombre, c’est pour ça qu’on se plonge dans le noir pour la regarder et aussi qu’on prend le temps d’adapter notre vision à l’obscurité avant de commencer la séance. Mais là je pense qu’on commence à être pas mal, je vais aller rejoindre lucile à l’extérieur et dans quelques instant

on va pouvoir commencer.

### Bon film…

«

»

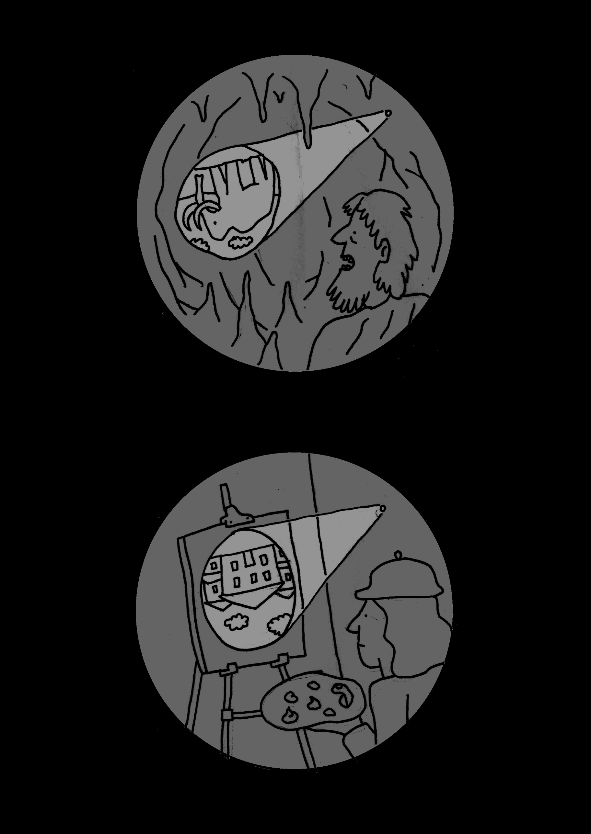
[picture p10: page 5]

# Le dispositif

Camera Obscura est un dispositif qui propose au public l’expérience unique d’une séance de cinéma sans électricité. Les spectateur·ices s’installent dans la camera obscura et assistent à la projection d’un film réalisé en temps réel à l’extérieur. Les images sont projetées grâce à un système optique fait de lentilles et de miroirs. Les sons et la musique sont produits et interprétés en direct sur un ensemble d’instruments acoustiques et mécaniques.

# La remorque

Le spectacle Camea Obscura se regarde de l’intérieur d’une remorque, un cinéma itinérant construit sur mesure équipé d’un gradin de 25 places et d’un écran de 1,80 m de large. La remorque se déploie avec un système optique (soufflet, objectifs, obturateurs, etc.) à l’avant du dispositif, de larges escaliers pour l’accès public et une structure scénique servant d’espace de jeu et de manipulation.

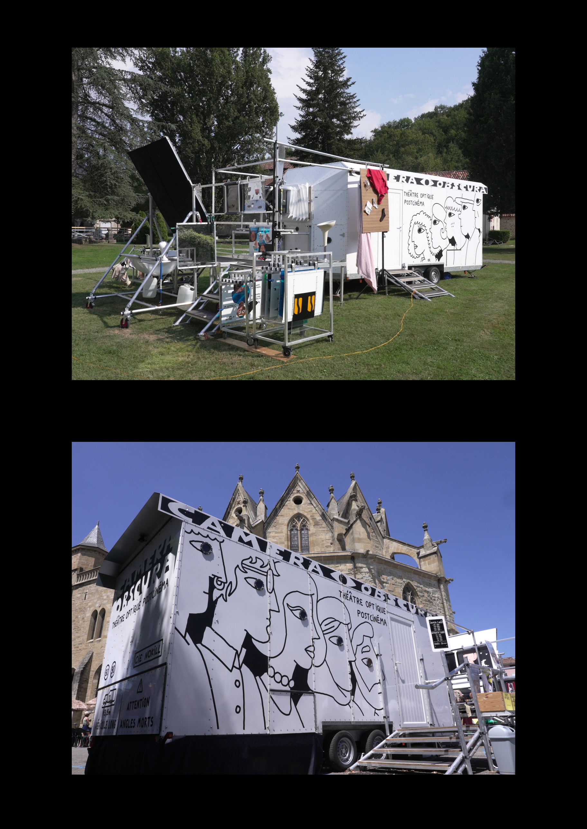
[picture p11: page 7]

# Souvenirs du futur

Le film projeté est Souvenirs du futur. (https://camera-obscura.cienokill.fr/contenu/ecriture/souvenirs-du-futur.html) C’est une collection de fragments, des évocations vagues ou anecdotiques de futurs possibles. Des récits d’anticipation qui s’affranchissent des thèmes de la science fiction et proposent une vision ni utopique ni apocalyptique d’un futur pluriel, banal et étrange.

Souvenirs du futur est pensé comme un film à sketchs, construit à partir d’une vingtaine de fragments indépendants. Les fragments sont courts ou longs ; avec ou sans voix off ; en animation ou en prise de vue réelle ; portés par une histoire anecdotique ou un fait général.

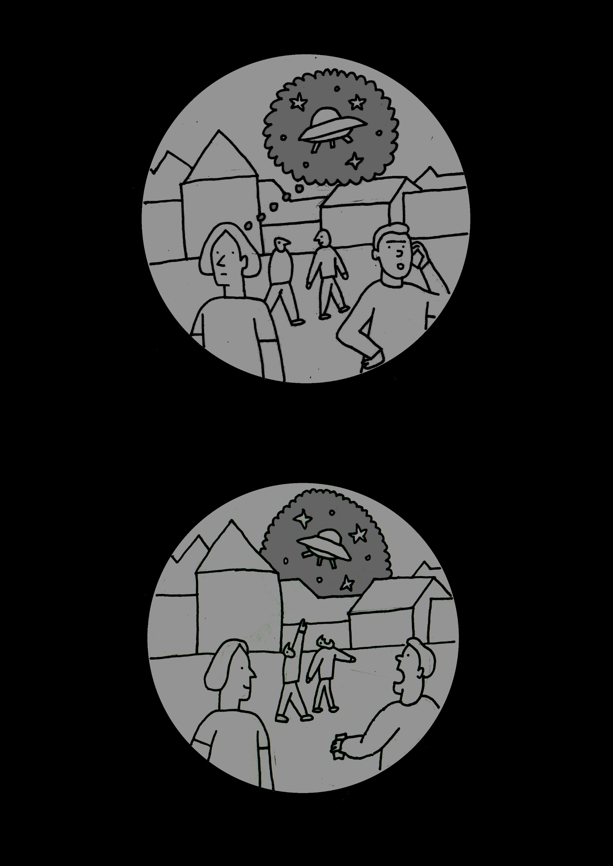
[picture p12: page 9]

Le prologue de Souvenirs du futur

### Je me souviens les guerres de l’eau. Des fêtes qui n’en finissaient pas dans les centres commerciaux abandonnés, le discours des “deux façons de voir les choses” et la révolte du paradigme. Je me souviens du mot interdit, les bonbons à la beerave, la première nouvelle couleur, la deuxième nouvelle

couleur, comment on était bien dans ce village sans nom,

### l’interdiction de regarder les agents dans les yeux. Deux couchés de soleil dans la même journée, je me souviens des mouches qui nous tournaient autour. qui a écrit cee chanson ? personne n’a écrit cee chanson, cee chanson s’est écrite

toute seule.

### Les lots de chaussees dépareillées dans les magasins, la publicité pour “le feu sans fumée”. Je me souviens la mort de la science-fiction, traverser l’atlantique à pied, ce livre que

tout le monde prétendait avoir lu, l’objet perdu, la météorite. une fine couche de neige sur les toits ce matin de janvier.

«

»

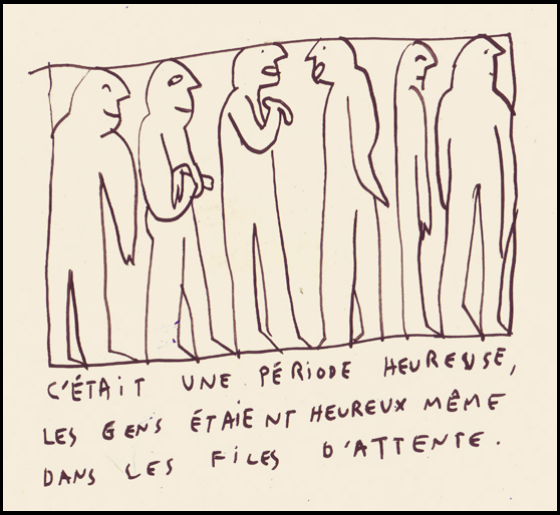
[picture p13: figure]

# Historique de la création

- Août 2016 : Léon rencontre une camera obscura au musée du cinéma de Gérone
- Décembre 2017 : Bertrand rencontre une camera obscura naturelle dans sa chambre à coucher
- Mai 2019 : Léon rencontre une camera obscura naturelle dans le camion de la compagnie lors d’une résidence de Turing Test
- Mai 2020 : début du développement du spectacle
- Juillet 2020 : première tentative de créer des camera obscura dans des pièces de la maison avec différents objectifs placés sur des fenêtres obstruées
- Janvier 2021 : premier dossier de présentation
- Décembre 2022 : fabrication du premier prototype de camera obscura, Les yeux dans le dos
- Octobre 2023 : début de construction de la remorque
- Janvier 2024 : finalisation du scénario de Souvenirs du futur
- Avril 2024 : début du travail de mise en scène avec Lucile
- Août 2024 : première du spectacle
Soit quatre ans d’échanges et de réflexions éparses, deux ans de recherche et développement, un an de prototypage, un an de création à plein temps

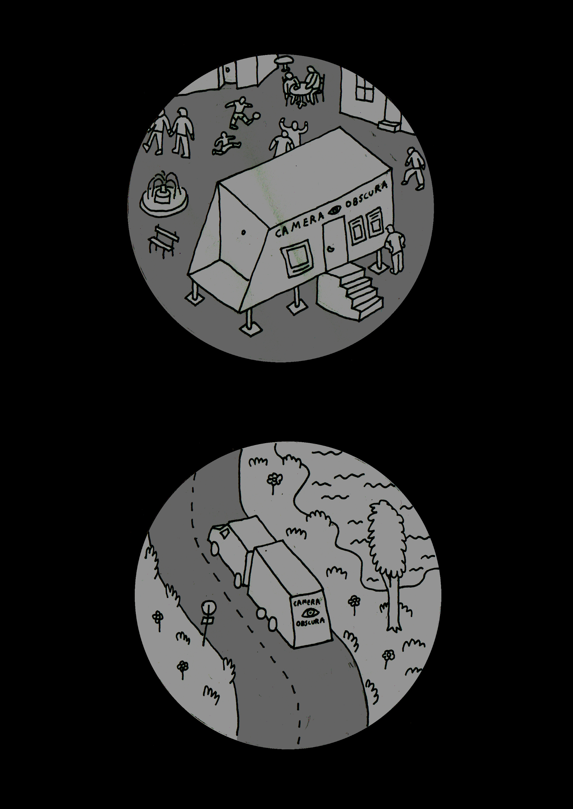
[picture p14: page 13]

## Pour plus d’informations

Nous vous invitons à consulter :
- Le site du spectacle : hps://camera-obscura.cienokill.fr
- Le site de la compagnie : hps://cienokill.fr
- La fiche technique du spectacle : hps://camera-obscura.cienokill.fr/contenu/technique/fiche-technique.pdf

## Équipe

En tournée, l’équipe artistique et technique est composée de
- Lucile Balézeaux
- Bertrand Lenclos
- Léon Lenclos

## Contact

La diffusion de Camera Obscura est assurée par Myléna Profit
- Téléphone : 06 11 99 24 73
- Mail : diff@nokill.fr

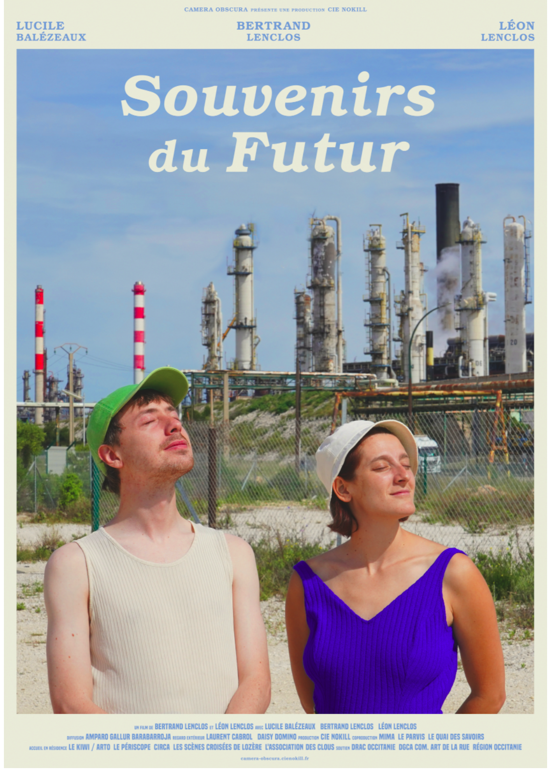
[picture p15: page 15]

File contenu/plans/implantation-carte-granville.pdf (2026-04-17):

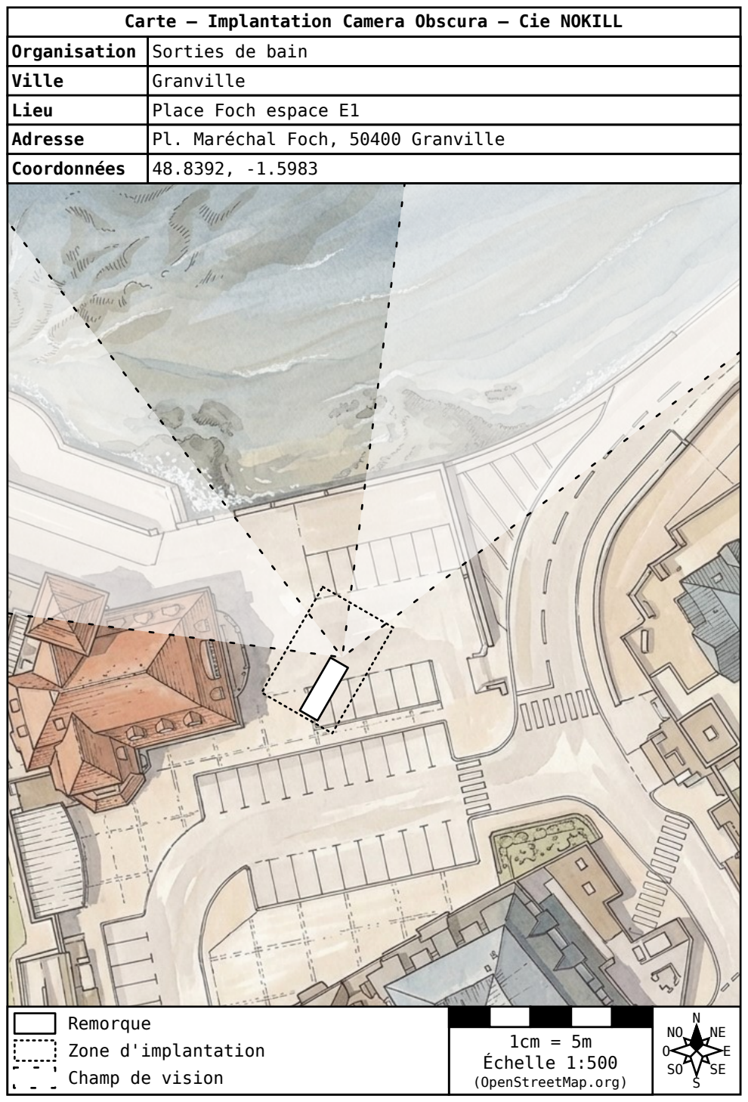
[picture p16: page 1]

Carte — Implantation Camera Obscura — Cie NOKILL
Organisation | Sorties de bain
Ville | Granville
Lieu | Place Foch espace E1
Adresse | Pl. Maréchal Foch, 50400 Granville
Coordonnées | 48.8392, -1.5983

(OpenStreetMap.org)

NO | NE
SO | SE

N

S

O | E

Remorque
Zone d'implantation
Champ de vision

Échelle 1:500

1cm = 5m

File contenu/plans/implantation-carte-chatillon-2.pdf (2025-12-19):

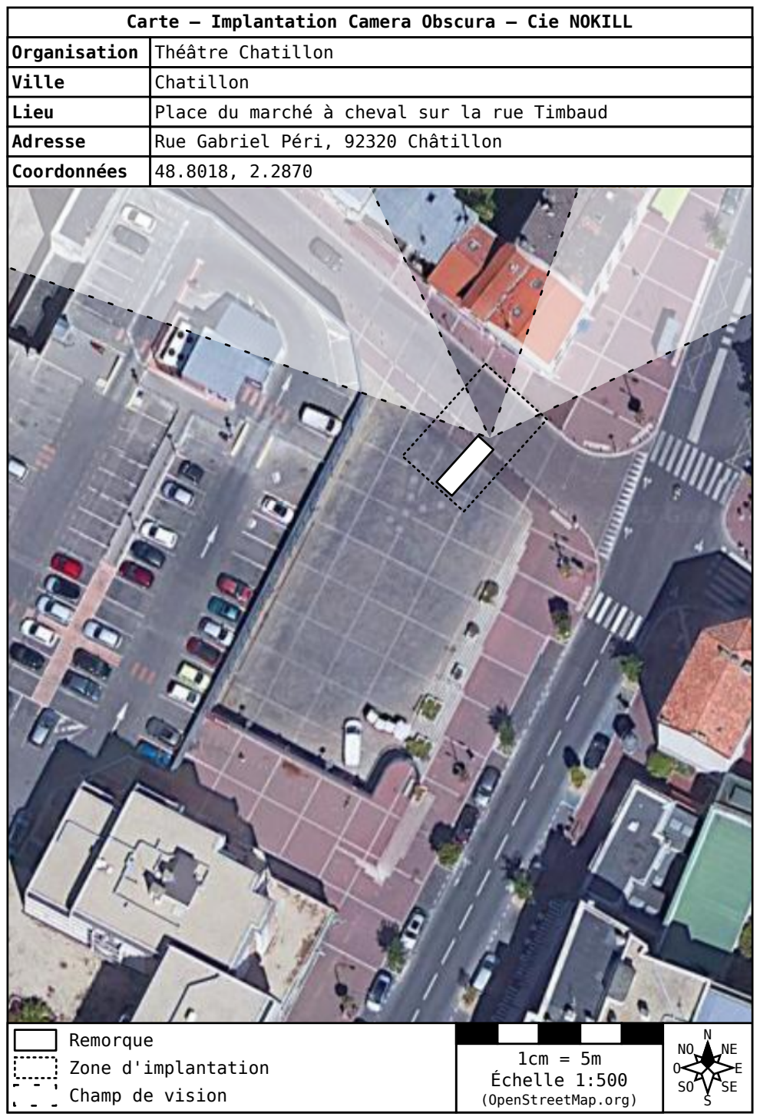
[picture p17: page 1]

Carte — Implantation Camera Obscura — Cie NOKILL
Organisation | Théâtre Chatillon
Ville | Chatillon
Lieu | Place du marché à cheval sur la rue Timbaud
Adresse | Rue Gabriel Péri, 92320 Châtillon
Coordonnées | 48.8018, 2.2870

(OpenStreetMap.org)

NO | NE
SO | SE

N

S

O | E

Remorque
Zone d'implantation
Champ de vision

Échelle 1:500

1cm = 5m

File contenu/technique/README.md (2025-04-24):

# Technique

Shéma d'implantation

Voici la liste des questions et spécifications techniques liés au spectacle *Camera Obscura*.

- [Introduction](introtechnique.md) : principes généraux qui guident notre travail
- [Fiche technique](fiche-technique.md)
- [Schéma d'implantation](../plans/implantation-orientation-NNE.svg): Quelle place occupe le dispositif dans l'espace public
- [Liste matos tournée](liste_matos_tournee.md) : pour ne rien oublier
- [Notice de montage](notice-montage.md) : pour monter

## Optique
- [Principes optiques](optique.md) : généralités sur la caméra obscura
- [Machinerie](machinerie.md) : quels mécanismes pour régler les differents paramètres optiques pendant le film 
- [Calage des éléments optiques](calage.md) : où placer les différents éléments optiques
- [Renversement de l'image](renversement.md) : comment retourner l'image de 180° (et autres rotations)
- [Luminosité](luminosite.md) : comment obtenir l'image la plus lumineuse possible
- [Futs](../technique/futs.md) : conceptions des futs pour les lentilles
- [Trucage optique](../technique/surimpression.md) : incrustation et surimpression
- [Soufflets](soufflets.md) : comment et pourquoi faire des soufflets
- [Iris](iris.md) : comment et pourquoi faire des iris
- [Abaque](abaque.md) : abaque des distances de tirage pour quelques objectifs
- [Vitres](vitres.md) : travailler avec des vitres et des miroirs

## Audio
- [diffusion du son dans la remorque](son.md) : comment donner l'illusion du son cinéma
- [Instrumentarium](instrumentarium.md) : instruments de musique et de bruitage

## Accueil public
- [Accessibilité](accessibilite.md) : sur l'accessibilité du spectacle pour les publics.
- [Isolation et climatisation](isolation.md) : faire du frais dans la remorque
- [Fauteuils](fauteuils.md) : garantir un max de confort avec un minimum d'encombrement et de poid
- Vendre des pop-corns cuits au four solaire
- [Norme ERP cat 5](norme-erp.md) : les obligations des ERP de 5e catégorie (< 50 spectacteurs)
  
## Divers
- [Soleil](soleil.md)
- [Implantation](implantation.md)
- [Marionettes](marionettes.md)
- [Habillage](habillage.md)
- [Fournisseurs](fournisseurs.md) : liste de fournisseurs.
- [Électricité](electricite.md) (oui, il y a un peu d'électricité au final...)
- [Vrac](vrac.md) : idées à creuser

## Documents
- [calcul_optique.ods](calcul_optique.ods) : tableur pour calcul des vartiables optiques
- [camera_obscura.doc](camera_obscura.doc) : notes de Gérard Tayeb sur differentes questions optiques
- [chantier_remorque.ods](chantier_remorque.ods) : organisation du chantier de construction de la remorque

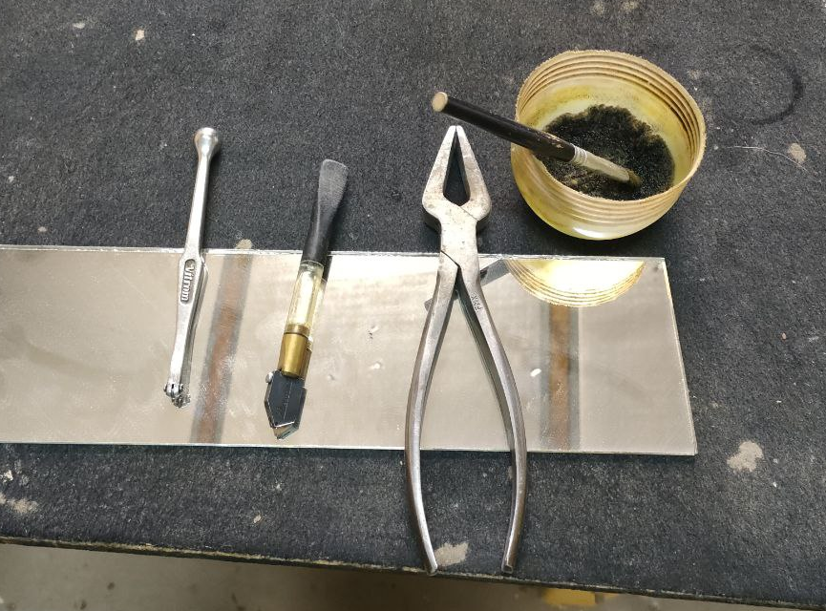
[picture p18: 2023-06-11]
contenu/photos/outils_verre.png

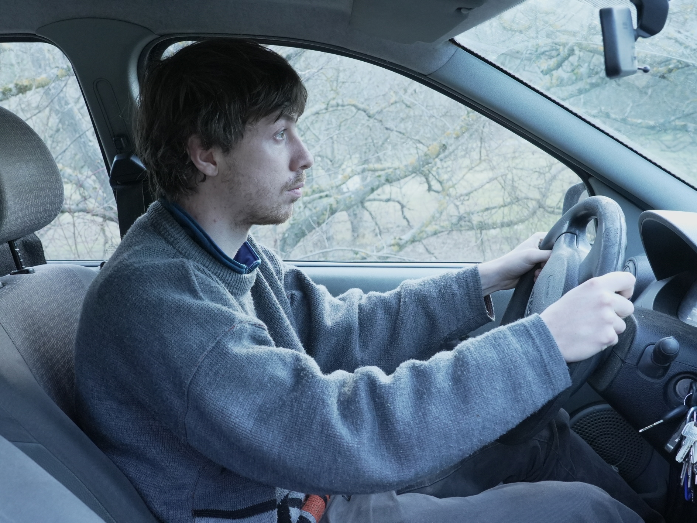
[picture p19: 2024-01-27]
contenu/photos/reference_voiture_2.jpg

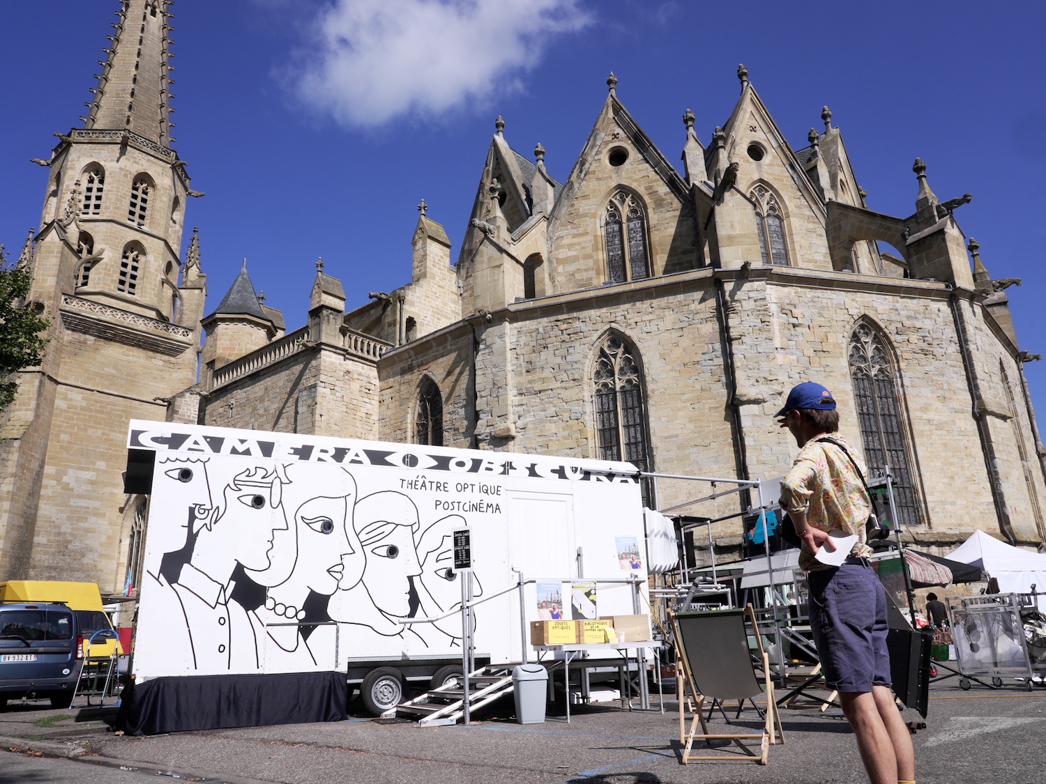
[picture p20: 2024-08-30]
contenu/photos/co-mima-2.JPG

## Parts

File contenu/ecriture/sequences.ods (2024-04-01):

ID | SÉQUENCE |  | IMAGE |  |  |  |  |  |  |  |  |  |  | SON |  |  |  |  | DISTRIBUTION
 | TITRE | Durée | Type | Plans | Esthétique | Accéssoirs | Costumes | Décors | Valeur | Focale | Miroir | Anim | Notes | voix |  | Musique | Bruitage | Notes | Persos |  |  | Figu | Casting |  |  | Régie
 |  |  |  |  |  |  |  |  |  |  |  |  |  | off | in |  |  |  | L | P | A |  | Lu | Lé | Be | Lu | Lé | Be
GÉNÉRIQUE DÉBUT | / | 00:30 | G | 3 | Générique | / | / | / | / | 750 | / | 1 plaque (1 anim) |  | / | / | / | Ocean drum (vague) |  | / | / | / | / | / | / | / | / | / | Be
PROLOGUE | / | 02:10 | A | 1 | Vitrail | / | / | / | L | 750 | / | 1 plaque (2 anims) |  | oui | / | / | clés (soleil) + Harbonium C2/Basse (sirenne) + ocen drum (vague) |  | / | / | 1 | / | / | / | / | / | / | Be
MATIN | Je me souviens du jour ou personne ne s'est levé | 01:10 | L | 1 | Décors | Couverture |  | Chambre | M | 1000 | 45° | / |  | oui | / | La belle époque A (Arpège guitarre : Gm Fm Ebm Dbm Cm) | Appeau (oiseaux) |  | 1 | / | / | / |  |  | / | / | / | Be
NIVEAU DE L’EAU | Je me souviens le niveau de l'eau | 02:20 | A | 1 | Vitrail | / | / | / | L | 750 | / | 1 plaque (2 anims) + 2 marios | Effet pluie | / | / | Souvenirs (Hamonium + Scie : Cm) | Harbonium C2/Basse + spring drum (orage) + ploc-ploc sur la mario + pluie + coquillages (eau) + bulles (poissons) + scie (baleine) + clés (soleil) + feutre (corde à linge) |  | / | / | 1 | / | / | / | / | / | / | Be
PLEIN EMPLOI | Le plein emploi | 01:20 | L | 1 | Large | / |  | Rue | L | 2000 | Amici | / |  | oui | / | Marina, Georges Briez (Gramophone Disque PA 2244) | Ambiance exterieur ? + bruitage zoomé (cuillère, pas, sac plastique, etc.) |  | / | / | / | oui | ? | ? | / | / | / | Be
PÉRIODE HEUREUSE | Une période heureuse (les gens étaient heureux même dans les files d'attente) | 00:45 | A | 1 | Ombre | / | / | / | L | 750 | / | 1 plaque + 1 mario |  | / | / | La belle époque B (Rythmique guitarre : Gm Fm Ebm Dbm Cm) | / |  | / | / | 4 | / | / | / | / | / | / | Be
LUNE | Le jour où la lune s’est écrasée sur terre | 00:50 | L | 1 | Décors | Cuillère + Verre d’eau |  | Cuisine | M | 1000 | Amici | / |  | / | / | Apocalypse (Cymballe arché + spring drum + Coquillages, percus) | Cuillère et verre (touillage) |  | 1 | / | / | / |  |  | / | / | / | Be
BON SENS | Le bon sens | 01:30 | L | 4 | Large | Journaux + lunettes + Prothèse |  | Rue flou + Rue + Fond noir | GP + M + L | 750 + 1000 + 2000 | Amici | Journal géant |  | oui | / | Marina, Georges Briez (Gramophone) | Papier (Journal) + Ambiance exterieur ? + elastique lunettes |  | 3 | 1 | / | oui | Lu | Lé | / | / | / | Be
MUTATION | La mutation | 01:30 | A | 1 | Vitrail | / | / | / | M | 750 | / | 1 plaque (2 anims) | fondu au noir | oui | / | La nuit (Harmonium en obstinato et descente : Dm) ou variante de Souvenirs arpege obstinato | Tube (ouverture des yeux) + Tine harmonium (interupteur torche) |  | / | / | 2 | / | / | / | / | / | / | Be
VACANCES | Les vacances à Saint-Tropez | 00:50 | P | 3 | Photo | / | / | / | L | 750 | / | 3 plaques |  | / | / | Les vacances (Harmonium accords nostalgique : Fm Gm7 Fm Gm7 Cm/G Abm7 Ab0 G7 Cm/G Abm7 Ab0 G7 F#0 Fm7 F0 G7 C) | / |  | / | 2 | / | / | / | / | / | / | / | Be
PODIUM | Le podium | 01:00 | A | 1 | Ombre | / | / | / | L | 750 | / | 1 plaque + 2 marios |  | oui | / | / | Frog Drum (podium et pas) + Balle rebondissante (voix) + Tambour applodissement (foule) |  | / | / | 8 | / | / | / | / | / | / | Be
EMBOUTEILLAGE | Je me souviens de l'embouteillage | 01:45 | L | 6 | Décors | Livre |  | Voiture | M + L | 1000 | Amici | 1 maquette (2 anim) + 1 maquette (anim) | Effets pluie et neige | / | oui | / | Boite en métal (moteur) + feutre (frein + vitre) + kazoo et klaxon (klaxon) + coquillages (pluie int) + bocal (vitre) + tambour pluie (ext) + papier (livre) + tambour vent (neige) |  | 2 | / | / | / | Lu | / | Be | / | Lé | /
BLAGUE | La blague | 01:00 | L | 1 |  | / |  | Rue flou | GP | 750 | Amici | / |  | oui | / | Sonate Pathétique N°8 op.13, 1e mv. 1e pt., Beethoven (Gramophone) | / |  | 1 | / | / | / |  |  | / | / | / | Be
PÉRIODE MALHEUREUSE | Une période malheureuse (les gens étaient malheureux même dans les parcs d’attractions) | 00:40 | A | 1 | Vitrail | / | / | / | L + M | 750 | / | 1 plaque (1 anim) + 1 mario |  | / | / | La belle époque B (Rythmique guitarre : Gm Fm Ebm Dbm Cm) | Rondelles (roues) |  | / | / | 4 | / | / | / | / | / | / | Be
GOLDEN RECORD | Le Golden Record | 01:15 | A | 3 | Vitrail | / | / | / | L + GP | 750 | / | 3 plaque (1 anim par plaque) |  | oui | / | / | Scie et spring drum (fusée) + craquement gramophone (disque) + scie (déception) |  | / | / | 2 | / | / | / | / | / | / | Be
FROID | Je me souviens le froid | 01:25 | L | 1 |  | Buée |  | Rue flou | M | 1000 | Amici | / | Effet neige | / | / | Souvenirs (Hamonium + Scie : Cm) | Tambour à vent (neige) + effet expiration. |  | 1 | / | / | / |  |  | / | / | / | Be
COMPORTEMENT | Le comportement | 01:50 | A | 2 | Vitrail | / | / | / | GP + L | 750 | / | 1 plaque (~10 anims) + 1 plaque (1 anim) |  | oui | / | Bla (Percu : spring drum, monocorde, cymbale, cymbale arché, gong) | / |  | / | / | 6 | / | / | / | / | / | / | Be
MODE | La mode | 01:00 | P | 1 | Photo | / | / | / | L | 750 | / | 1 plaque |  | oui | / | Cycles (Sanza) | / |  | / | 1 | / | / | / | / | / | / | / | Be
CONVERSATION | La conversation | 00:50 | L | 6 |  | 2 tel |  | Rue flou + Mur de brique | GP + M | 750 + 1000 | Amici + 45° | / |  | / | / | Marina, Georges Briez (Gramophone) | / |  | 2 | / | / | / | Lu | Lé | / | / | / | Be
CHANSON | L’ultime chanson | 01:30 | L | 2 |  | Clavier + micro + paillettes |  | Fond noir | GP | 750 | Amici ou 45° ? | / | Incrustation | oui | oui | I survived (Harmonium et chant) | / |  | 1 | / | / | / | / | Lé | / | Lu | / | Be
ÉPILOGUE | / | 01:25 | A | 2 | Vitrail | / | / | / | M + L | 750 + 1000 | / | 1 plaque (1 anim) + 1 plaque (1 anim) |  | oui | / | / | Bulles (perso), clés (reflet de l’eau), coquillages (eau) |  | / | / | perso prologue | / | / | / | / | / | / | Be
GÉNÉRIQUE FIN | / | 01:50 | G | 1 | Générique | / | / | Rue ? | L ? | 750 + 2000 ? | Amici ? | 1 plaque (1 anim) |  | / | / | Souvenirs (Hamonium + Scie : Cm) | / |  | / | / | / | / | / | / | / | / | / | Be
TOTAL |  | 28:25 |  | 44 |  |  |  |  |  |  |  | ~20 plaques + 2 maquettes + 6 mario |  |  |  |  |  |  | 12 | 4 | 28
 |  |  |  |  |  |  |  |  |  |  |  |  |  |  |  |  |  |  | 44

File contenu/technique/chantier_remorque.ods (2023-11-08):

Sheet: métal
tube carré alu 30x30 ep 2 |  |  |  |  | tube carré alu 30x40 ep 2 |  |  |  |  | Plat alu 30 ep 3 |  |  |  |  |  | galva 40 x 40 ep 2 |  |  |  |  |  | Contreplaqué antidérapant Riga Tex 1525x3000 ep 9 |  |  |  |  | Liège expansé 1500 x 1000 ep 20
 |  |  |  |  |  | ref | qte | l | l total |  | ref | qte | l | L | L en 30 |  | ref | qte | l | l total
 | ref | qte | l | l total |  | #1101 | 50 | 451 | 22550 |  | #201 | 4 |  |  |  |  | #301 | 2 | 435 | 870 |  |  | ref | qte | S réel | plaques |  | ref | qte | S réel | plaques
 | #001 | 20 | 254 | 5080 |  | TOTAL |  |  | 22550 |  | #202 | 72 | 30 | 70 | 5040 |  | #302 | 10 | 575 | 5750 |  |  | PLANCHER 1 | 1 | 2,05 |  |  | LIEGE SUD |  | 6,33
 | #002 | 10 | 2046 | 20460 |  | PC |  |  | 3,7583333333 |  | #207 | 4 | 30 | 50 | 200 |  | #303 | 1 | 685 | 685 |  |  | PLANCHER 2 | 1 | 3,38 |  |  | LIEGE NORD |  | 4,39
 | #003 | 2 | 1094 | 2188 |  | commande PC |  |  | 4 |  | #208 | 4 | 30 | 100 | 400 |  | #304 | 1 | 415 | 415 |  |  | PLANCHER 3 | 1 | 2,68 |  |  | LIEGE EST |  | 14,65
 | #004 | 10 | 120 | 1200 | barre ronde 10mm Aluminium |  |  |  |  |  | TOTAL |  |  |  | 5640 |  | TOTAL |  |  | 7720 |  |  | PLANCHER 4 | 1 | 2,71 |  |  | LIEGE OUEST |  | 14,65
 | #005 | 4 | 980 | 3920 |  | ref | qte | l | l total |  | PC |  |  |  | 0,94 |  | PC |  |  | 1,2866666667 |  |  | PLANCHER 5 | 1 | 1,54 |  |  | LIEGE PLAF |  | 14,74
 | #006 | 1 | 1590 | 1590 |  | #1101 | 100 | 20 | 2000 |  | commande PC |  |  |  | 1 |  | commande PC |  |  | 2 |  |  | PLANCHER 6 | 1 | 0,33 |  |  | LIEGE FAUX PLAF |  | 14,74
 | #007 | 20 | 2396 | 47920 |  | #1102 | 50 | 80 | 4000 |  |  |  |  |  |  |  |  |  |  |  |  |  | PLANCHER 7 | 1 | 0,33
 | #008 | 16 | 2417 | 38672 |  | TOTAL |  |  | 6000 | Plat alu 80 ep 3 |  |  |  |  |  | galav U 60 x 160 ep 4 |  |  |  |  |  |  | PLANCHER 8 | 1 | 0,33 |  |  | TOTAL |  | 69,5 | 50
 | #009 | 2 | 1992 | 3984 |  | PC |  |  | 1 |  | ref | qte | l | L | L en 80 |  | ref | qte | l | l total |  |  | MARCHE 1 | 1 | 1,59
 | #010 | 1 | 767 | 767 |  | commande PC |  |  | 2 |  | #201 | 4 |  |  |  |  | #401 | 2 | 837 | 1674 |  |  | MARCHE 2 | 1 | 1,64
 | #011 | 1 | 1495 | 1495 | tube carré alu 35x35 ep 2 |  |  |  |  |  | #203 | 5 | 80 | 40 | 200 |  | #402 | 1 | 1060 | 1060 |  |  | MARCHE 3 | 1 | 1,94
 | #012 | 2 | 486 | 972 |  | ref | qte | l | l total |  | #204 | 4 | 80 | 50 | 200 |  | TOTAL |  |  | 2734 |  |  | MARCHE 4 | 1 | 3,05
 | #013 | 2 | 1000 | 2000 |  | #101 | 34 | 239 | 8126 |  | #205 | 6 | 80 | 60 | 360 |  | PC |  |  | 0,4556666667 |  |  | CONTRE MARCHE 1 | 1 | 0,42
 | #014 | 2 | 2007 | 4014 |  | #102 | 1 | 995 | 995 |  | #206 | 6 | 80 | 45 | 270 |  | commande PC |  |  | 1 |  |  | CONTRE MARCHE 2 | 1 | 0,47
 | #015 | 2 | 756 | 1512 |  | #103 | 1 | 795 | 795 |  | TOTAL |  |  |  | 1030 |  |  |  |  |  |  |  | CONTRE MARCHE 3 | 1 | 0,47
 | #016 | 1 | 1572 | 1572 |  | #104 | 1 | 595 | 595 |  | PC |  |  |  | 0,1716666667 | Tole perfo C10T12 galva 2000 x 1000 ep 1 |  |  |  |  |  |  | CONTRE MARCHE 4 | 1 | 0,47
 | #017 | 2 | 731 | 1462 |  | #105 | 1 | 395 | 395 |  | commande PC |  |  |  | 1 |  | ref | qte | S réel | plaques
 | #018 | 2 | 533 | 1066 |  | #106 | 1 | 197 | 197 |  |  |  |  |  |  |  | STANDARD | 19 | 1,14 |  |  |  | TOTAL |  | 23,4 | 8
 | #019 | 1 | 1085 | 1085 |  | #107 | 4 | 206 | 824 | tole alu laqué poudre 3000 x 1500 ep 1,5 |  |  |  |  |  |  | GRILLE 1 | 1 | 1,91
 | #020 | 4 | 841 | 3364 |  | #108 | 2 | 86 | 172 |  | ref | qte | S réel | plis | plaques |  | GRILLE 2 | 1 | 0,41 |  |  | tube rond alu 50 ep 2
 | #021 | 4 | 448 | 1792 |  | TOTAL |  |  | 12099 |  | N1 | 1 | 2,83 | 4 |  |  | GRILLE 3 | 1 | 0,86 |  |  |  | ref | qte | l | l total
 | #022 | 2 | 921 | 1842 |  | PC |  |  | 2,0165 |  | N2 | 1 | 1,56 | 2 |  |  | GRILLE 4 | 1 | 0,86 |  |  |  |  | 2 | 3580 | 7160
 | #023 | 4 | 1331 | 5324 |  | commande PC |  |  | 3 |  | E1 | 1 | 2,33 |  |  |  | GRILLE 5 | 1 | 0,51 |  |  |  |  | 4 | 2910 | 11640
 | #024 | 2 | 1000 | 2000 |  |  |  |  |  |  | E2 | 1 | 0,191 |  |  |  | GRILLE 6 | 1 | 0,51 |  |  |  |  | 2 | 2576 | 5152
 | #025 | 4 | 417 | 1668 | Cornière alu 100 x 50 ep 3 |  |  |  |  |  | E3 | 1 | 2,8 |  |  |  | TOTAL |  | 6,2 | 4 |  |  |  | 2 | 1800 | 3600
 | #026 | 16 | 714 | 11424 |  | ref | qte | l | l total |  | E4 | 1 | 3,28 |  |  |  | PC |  |  | 3,1 |  |  |  | 1 | 1435 | 1435
 | #027 | 4 | 524 | 2096 |  | #501 | 17 | 60 | 1020 |  | E5 | 1 | 2,74 |  |  |  | commande PC |  |  | 4 |  |  |  | 2 | 396 | 792
 | #028 | 6 | 894 | 5364 |  | #502 | 4 | 45 | 180 |  | W1 | 1 | 2,33 |  |  | tole galva 1500 x 3000 ep 0,8 |  |  |  |  |  |  | TOTAL |  |  | 29779
 | #029 | 4 | 494 | 1976 |  | #503 | 2 | 100 | 200 |  | W2 | 1 | 0,191 |  |  |  | ref | qte | S réel | plis | plaques |  | PC |  |  | 4,9631666667
 | #030 | 4 | 464 | 1856 |  | #504 | 4 | 762 | 3048 |  | W3 | 1 | 2,8 |  |  |  | T1 | 1 | 0,97 |  |  |  | commande PC |  |  | 8
 | #031 | 4 | 717 | 2868 |  | #505 | 4 | 1174 | 4696 |  | W4 | 1 | 3,28 |  |  |  | T2 | 1 | 3,14
 | #032 | 8 | 531 | 4248 |  | #506 | 2 | 930 | 1860 |  | W5 | 1 | 2,74 |  |  |  | T3 | 1 | 3,06
 | #033 | 8 | 960 | 7680 |  | #507 | 4 | 968 | 3872 |  | C1 | 1 | 3,13 | 4 |  |  | T4 | 1 | 2,5 |  |  | Liège expansé 1500 x 1000 ep 20
 | #034 | 8 | 857 | 6856 |  | TOTAL |  |  | 14876 |  | C2 | 1 | 2,78 | 4 |  |  | T5 | 1 | 0,34
 | #035 | 6 | 696 | 4176 |  | PC |  |  | 2,4793333333 |  | C3 | 1 | 3,92 | 4 |  |  | T6 | 1 | 0,65 | 2 |  |  | ref | qte | S réel | plaques
 | #036 | 4 | 1168 | 4672 |  | commande PC |  |  | 3 |  | C4 | 1 | 4,48 | 4 |  |  | T7 | 1 | 0,34 |  |  |  | LIEGE SUD |  | 6,33
 | #037 | 4 | 2297 | 9188 |  |  |  |  |  |  | C5 | 1 | 4,49 | 4 |  |  | TOTAL |  | 11 |  | 3 |  | LIEGE NORD |  | 4,39
 | #038 | 2 | 6003 | 12006 |  |  |  |  |  |  | S1 | 1 | 0,22 |  |  |  | PC |  |  |  | 3 |  | LIEGE EST |  | 14,65
 | #1001 | 50 | 359 | 17950 |  |  |  |  |  |  | S2 | 1 | 2 |  |  |  | commande PC |  |  |  | 3 |  | LIEGE OUEST |  | 14,65
 | #1002 | 50 | 370 | 18500 |  |  |  |  |  |  | S3 | 1 | 2 |  |  |  |  |  |  |  |  |  | LIEGE PLAF |  | 14,74
 | #1003 | 50 | 706 | 35300 |  |  |  |  |  |  | S4 | 1 | 0,96 |  |  |  |  |  |  |  |  |  | LIEGE FAUX PLAF |  | 14,74
 | #1004 | 50 | 310 | 15500 |  |  |  |  |  |  | S5 | 1 | 0,96 |  |  | tube rond alu 35 ep 2
 | #1005 | 50 | 375 | 18750 |  |  |  |  |  |  | TOTAL |  | 52,012 |  | 17 |  | ref | qte | l | l total |  |  | TOTAL |  | 69,5 | 50
 | AMICI | 5 | 1000 | 5000 |  |  |  |  |  |  | PC |  |  |  | 17 |  |  | 3 | 1452 | 4356
 | TOTAL |  |  | 342359 |  |  |  |  |  |  | commande PC |  |  |  | 18 |  |  | 6 | 735 | 4410 |  | Cornière acier 30 x 30 ep 3
 | PC |  |  | 57,0598333333 |  |  |  |  |  | tole alu brut 3000 x 1500 ep 1,5 |  |  |  |  |  |  |  | 2 | 424 | 848 |  |  | ref | qte | l | total l
 | commande PC |  |  | 60 |  |  |  |  |  |  | ref | qte | S réel | plis | plaques |  |  | 3 | 876 | 2628 |  |  | Support Manchon | 40 | 50 | 2000
 |  |  |  |  |  |  |  |  |  |  | CAISSE1 | 1 | 0,97 | 1 |  |  | TOTAL |  |  | 12242 |  |  | TOTAL |  |  | 2000
 |  |  |  |  |  |  |  |  |  |  | CAISSE2 | 1 | 0,97 | 1 |  |  | PC |  |  | 2,0403333333 |  |  | PC |  |  | 0,3333333333
 |  |  |  |  |  |  |  |  |  |  | CAISSE3 | 1 | 1,96 | 2 |  |  | commande PC |  |  | 3 |  |  | commande PC |  |  | 1
 |  |  |  |  |  |  |  |  |  |  | CAISSE4 | 1 | 1,96 | 2
 |  |  |  |  |  |  |  |  |  |  | TOTAL |  | 5,86 |  | 2
 |  |  |  |  |  |  |  |  |  |  | PC |  |  |  | 2
 |  |  |  |  |  |  |  |  |  |  | commande PC |  |  |  | 2

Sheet: Visserie
tige fileté M5
 | ref | qte | l | l total
 | #1301 | 50 | 25 | 1250
 | TOTAL |  |  | 1250
manchon M10 30mm hexa
 | ref | qte | l | l total
 |  | 50 |  | 0
 | TOTAL | 50 |  | 0
Collier duratruss 50 mm
 | ref | qte | l | l total
 |  | 50 |  | 0
 | TOTAL | 50 |  | 0
Collier duratruss 50 mm
 | ref | qte | l | l total
 |  | 40 |  | 0
 | TOTAL | 40 |  | 0
Collier duratruss 35 mm
 | ref | qte | l | l total
 |  | 40 |  | 0
 | TOTAL | 40 |  | 0

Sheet: retro-planning
31 aout | devis métal
 | contact durant
1 er quinzaine aout | code
 | dessin marches et rampe
1 er quinzaine sept | permis
08/09/23 | achat proto hublot + étude prix fournisseurs
08/09/23 | achat aglo M1 pour le sol
4 sept → 4 octobre | livraison isolant+bois
4 sept → 4 octobre | livraison métal
4 sept → 4 octobre | achat fenêtre et porte
4 sept → 4 octobre | Presta façonnage
4 sept → 4 octobre | Prépa (coupe tube)
4 sept → 4 octobre | Préparer gabarit arche
4 sept → 4 octobre | hublot
18 sept | récupération remorque
09/10/23 | extension plateau
10/10/23 | tôle sol galva
11/10/23 | arche
12/10/23 | arche
13/10/23 | Arche + renforts
14/10/23 | Pose des arches+ poutre principale porte
16/10/23 | Structure 1, 2,3,4
17/10/23 | Isolation + plancher + grilles
18/10/23 | fixation porte + renfort + trappe
19/10/23 | Marches gradins + grilles
20/10/23 | Manchons
21/10/23
23/10/23 | pose tole
24/10/23 | pose tole
25/10/23 | pose tole
26/10/23 | sièges
27/10/23 | sièges, clim, tube cage, miroir amici, vitre
30/10/23 | voyage Assier
31/10/23 | Isolation laine de coton
01/11/23 | Isolation liege + faux plafond
02/11/23 | raccord soufflet
03/11/23 | ecran+cage+ test image

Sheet: Achat
 |  |  |  |  | ARCELOR MITTAL
BARRE/TUBE ALU |  | ARCELOR MITTAL |  |  |  |  | https://e-steel.arcelormittal.com/FR/fr/ |  |  |  |  | tube carré alu 30x40 ep 2 |  |  |  |  | Plat alu 30 ep 3 |  |  |  |  |  | galva 40 x 40 ep 2 |  |  |  |  |  | Contreplaqué antidérapant Riga Tex 1525x3000 ep 9
 |  | CODINA |  |  |  |  | https://www.codinaproduitsmetallurgiques.fr/vente-de-fer-soual.html
 |  | DURAND JEAN |  |  |  |  | https://www.durandjean.fr/
 | tube carré alu 30x30 ep 2 |  | 60 | barres de 6 m | 24,15 | 1449
 | tube carré alu 30x40 ep 2 |  | 4 | barres de 6 m |  | 0 |  | ref | qte | l | l total |  | ref | qte | l | l total |  | ref | qte | l | L | L en 30 |  | ref | qte | l | l total |  |  | ref | qte | S réel | plaques | ref | qte | S réel | plaques
 | tube carré alu 35x35 ep 2 |  | 3 | barres de 6 m | 29,19 | 87,57 |  | #001 | 20 | 254 | 5080 |  | #1101 | 50 | 451 | 22550 |  | #201 | 4 |  |  |  |  | #301 | 2 | 435 | 870 |  |  | PLANCHER 1 | 1 | 2,05 |  | LIEGE SUD |  | 6,33
 | tube rond alu 35 ep 2 |  | 3 | barres de 6 m | 23,4 | 70,2
 | tube rond alu 50 ep 2 |  | 8 | barres de 6 m | 32,55 | 260,4
 | Cornière alu 100 x 50 ep 3 |  | 3 | barres de 6 m |  | 0 |  | #002 | 10 | 2046 | 20460 |  |  |  |  |  |  | #202 | 72 | 30 | 70 | 5040 |  | #302 | 10 | 575 | 5750 |  |  | PLANCHER 2 | 1 | 3,38 |  | LIEGE NORD |  | 4,39
 | barre ronde 10mm Aluminium |  | 2 | barres de 6 m | 9,58 | 19,16 |  | #003 | 2 | 1094 | 2188 |  | TOTAL |  |  | 22550 |  | #207 | 4 | 30 | 50 | 200 |  | #303 | 1 | 685 | 685 |  |  | PLANCHER 3 | 1 | 2,68 |  | LIEGE EST |  | 14,65
 | Plat alu 30 ep 3 |  | 1 | barres de 6 m | 12,76 | 12,76 |  | #004 | 10 | 120 | 1200 | barre ronde 10mm Aluminium |  |  |  |  |  | #208 | 4 | 30 | 100 | 400 |  | #304 | 1 | 415 | 415 |  |  | PLANCHER 4 | 1 | 2,71 |  | LIEGE OUEST |  | 14,65
 | Plat alu 80 ep 3 |  | 1 | barres de 6 m |  | 0 |  | #005 | 4 | 980 | 3920 |  |  |  |  |  |  |  |  |  |  |  |  |  |  |  |  |  |  | PLANCHER 5 | 1 | 1,54 |  | LIEGE PLAF |  | 14,74
 |  |  |  |  |  | 0 |  | #006 | 1 | 1590 | 1590 |  | ref | qte | l | l total |  | TOTAL |  |  |  | 5640 |  | TOTAL |  |  | 7720 |  |  | PLANCHER 6 | 1 | 0,33 |  | LIEGE FAUX PLAF |  | 14,74
 |  |  |  |  |  | 0 |  | #007 | 20 | 2396 | 47920 |  | #1101 | 100 | 20 | 2000 |  | en m |  |  |  | 5,64 |  |  |  |  | 7,72 |  |  | PLANCHER 7 | 1 | 0,33
TOLE ALU |  |  |  |  |  | 0 |  | #008 | 16 | 2417 | 38672 |  | #1102 | 50 | 80 | 4000 | Plat alu 80 ep 3 |  |  |  |  |  | galav U 60 x 160 ep 4 |  |  |  |  |  |  | PLANCHER 8 | 1 | 0,33 |  | TOTAL |  | 69,5 | 50
 | tole alu laqué poudre 3000 x 1500 ep 1,5 |  | 18 | Plaques 4,5 m2 | 167,03 | 3006,54 |  | #009 | 2 | 1992 | 3984 |  |  |  |  |  |  |  |  |  |  |  |  |  |  |  |  |  |  | MARCHE 1 | 1 | 1,59
 | tole alu brut 3000 x 1500 ep 1,5 |  | 2 | Plaques 4,5 m2 | 117,92 | 235,84 |  | #010 | 1 | 767 | 767 |  | TOTAL |  |  | 6000 |  | ref | qte | l | L | L en 80 |  | ref | qte | l | l total |  |  | MARCHE 2 | 1 | 1,64
 |  |  |  |  |  | 0 |  | #011 | 1 | 1495 | 1495 | tube carré alu 35x35 ep 2 |  |  |  |  |  | #201 | 4 |  |  |  |  | #401 | 2 | 837 | 1674 |  |  | MARCHE 3 | 1 | 1,94
BARRE/TUBE GALVA |  |  |  |  |  | 0 |  | #012 | 2 | 486 | 972 |  |  |  |  |  |  | #203 | 5 | 80 | 40 | 200 |  | #402 | 1 | 1060 | 1060 |  |  | MARCHE 4 | 1 | 3,05
 | galva 40 x 40 ep 2 |  | 2 | barres de 6 m | 52,95 | 105,9 |  | #013 | 2 | 1000 | 2000 |  | ref | qte | l | l total |  | #204 | 4 | 80 | 50 | 200 |  |  |  |  |  |  |  | CONTRE MARCHE 1 | 1 | 0,42
 | galav U 60 x 160 ep 4 |  | 1 | barres de 6 m |  | 0 |  | #014 | 2 | 2007 | 4014 |  | #101 | 34 | 239 | 8126 |  | #205 | 6 | 80 | 60 | 360 |  | TOTAL |  |  | 2734 |  |  | CONTRE MARCHE 2 | 1 | 0,47
 |  |  |  |  |  | 0 |  | #015 | 2 | 756 | 1512 |  | #102 | 1 | 995 | 995 |  | #206 | 6 | 80 | 45 | 270 |  |  |  |  | 2,734 |  |  | CONTRE MARCHE 3 | 1 | 0,47
TOLE GALVA |  |  |  |  |  | 0 |  | #016 | 1 | 1572 | 1572 |  | #103 | 1 | 795 | 795 |  |  |  |  |  |  | Tole perfo C10T12 galva 3000 x 1500 ep 1,5 |  |  |  |  |  |  | CONTRE MARCHE 4 | 1 | 0,47
 | Tole perfo C10T12 galva 2000 x 1000 ep 1,5 |  | 4 | Plaques 2 m2 | 49,53 | 198,12 |  | #017 | 2 | 731 | 1462 |  | #104 | 1 | 595 | 595 |  | TOTAL |  |  |  | 1030
 | tole galva 1500 x 3000 ep 0,8 |  | 3 | Plaques 4,5 m2 | 69,36 | 208,08 |  | #018 | 2 | 533 | 1066 |  | #105 | 1 | 395 | 395 |  | en m |  |  |  | 1,03 |  | ref | qte | S réel | plaques |  |  | TOTAL |  | 23,4 | 8
 |  |  |  |  |  | 0 |  | #019 | 1 | 1085 | 1085 |  | #106 | 1 | 197 | 197 | tole alu laqué poudre 3000 x 1500 ep 1,5 |  |  |  |  |  |  | STANDARD | 19 | 1,14
BARRE/TUBE ACIER |  |  |  |  |  | 0 |  | #020 | 4 | 841 | 3364 |  | #107 | 4 | 206 | 824 |  |  |  |  |  |  |  | GRILLE 1 | 1 | 1,91 |  |  | tube rond alu 50 ep 2
 | Cornière acier 30 x 30 ep 3 |  | 1 | barres de 6 m | 17,31 | 17,31 |  | #021 | 4 | 448 | 1792 |  | #108 | 2 | 86 | 172 |  | ref | qte | S réel | plis | plaques |  | GRILLE 2 | 1 | 0,41
 |  |  |  |  |  | 0 |  | #022 | 2 | 921 | 1842 |  |  |  |  |  |  | N1 | 1 | 2,83 | 4 |  |  | GRILLE 3 | 1 | 0,86 |  |  |  | ref | qte | l | l total
DIVERS |  |  |  |  |  | 0 |  | #023 | 4 | 1331 | 5324 |  | TOTAL |  |  | 12099 |  | N2 | 1 | 1,56 | 2 |  |  | GRILLE 4 | 1 | 0,86 |  |  |  |  | 2 | 3580 | 7160
 | Couvre-joint finition / cornière finition |  |  |  |  | 0
VISSERIE |  | CAPUS |  |  |  | 0
 | écrou à embase crantée M5 et M6 |  | 1400 |  |  | 0
 | BTR 5x(40/45/65) cyl fixation structure |  | 270
 | écrou à serti M5 + pince hublot |  | 120
 | BTR 6x16 fraisé fixation cornière |  | 400
 | BTR 5x16 bombé fixation hublots |  | 120
 | BTR 5X10 bombé fixation galva sol |  | 200
 | Rivet étanche dia 4mm long 9,6 mm |  | 2750 |  |  |  | https://gfix.fr/45-rivet-etanche-tete-plate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
 | manchon m10 hexa en 30 ou 40 mm |  | 150
TOTAL METAL |  |  |  |  |  | 5670,88 |  | #024 | 2 | 1000 | 2000 |  | en m |  |  | 12,099 |  | E1 | 1 | 2,33 |  |  |  | GRILLE 5 | 1 | 0,51 |  |  |  |  | 4 | 2910 | 11640
 |  |  |  |  |  |  | https://www.eco-logis.com/
ISOLATION |  |  |  |  |  |  |  | #025 | 4 | 417 | 1668 | Cornière alu 100 x 50 ep 3 |  |  |  |  |  | E2 | 1 | 0,191 |  |  |  | GRILLE 6 | 1 | 0,51 |  |  |  |  | 2 | 2576 | 5152
 |  | ECOLOGIS | 67,5 | 9 plaques | 11,25 | 759,375 | https://www.eco-logis.com/ | #026 | 16 | 714 | 11424 |  |  |  |  |  |  | E3 | 1 | 2,8 |  |  |  |  |  |  |  |  |  |  | 2 | 1800 | 3600
 | BUTEX laine de coton 100mm | ECOLOGIS | 92,16 | 16 paquets | 8,33 | 767,6928 | https://www.eco-logis.com/ | #027 | 4 | 524 | 2096 |  | ref | qte | l | l total |  | E4 | 1 | 3,28 |  |  |  | TOTAL |  | 6,2 | 2 |  |  |  | 1 | 1435 | 1435
 | kalmut | AZUR SCENIC |  |  |  |  |  | #028 | 6 | 894 | 5364 |  | #501 | 17 | 60 | 1020 |  | E5 | 1 | 2,74 |  |  | tole galva 1500 x 3000 ep 0,8 |  |  |  |  |  |  |  | 2 | 396 | 792
 | Moquette | ST MACLOU |  |  |  |  | https://www.sicm-france.fr/expo-velours/873-expo-velours-9520.html | #029 | 4 | 494 | 1976 |  | #502 | 4 | 45 | 180 |  | W1 | 1 | 2,33 |  |  |  |  |  |  |  |  |  |  |  |  | 0
 | divers joint |  |  |  |  |  |  | #030 | 4 | 464 | 1856 |  | #503 | 2 | 100 | 200 |  | W2 | 1 | 0,191 |  |  |  | ref | qte | S réel | plis | plaques |  | TOTAL |  |  | 29779
 |  | DISPANO |  |  |  |  |  | #031 | 4 | 717 | 2868 |  | #504 | 4 | 762 | 3048 |  | W3 | 1 | 2,8 |  |  |  | T1 | 1 | 0,97 |  |  |  | en m |  |  | 29,779
BOIS |  |  |  |  |  |  |  | #032 | 8 | 531 | 4248 |  | #505 | 4 | 1174 | 4696 |  | W4 | 1 | 3,28 |  |  |  | T2 | 1 | 3,14
 | isorel HDF |  | 9 | Plaques 2,5 x 1,25 | 102,09 | 918,81 | https://www.dispano.fr/p/panneau-brut/panneau-contreplaque-tebopin-flam-pin-maritime-ignifuge-b-s2-d0-selon-en-13501-1-classe-3-e1-tsca-faces-i-ii-format-250x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
 | isorel M1 |  |  |  |  |  | https://protecflam.fr/plastiflam-films-baches-ignifuges/59-protection-ignifuge-plastiflam-tbord-270.html | #033 | 8 | 960 | 7680 |  | #506 | 2 | 930 | 1860 |  | W5 | 1 | 2,74 |  |  |  | T3 | 1 | 3,06 |  |  | Liège expansé 1500 x 1000 ep 20
 | plancher OSB 15mm |  |  | 2,5 x 5
 | plancher OSB 9mm |  |  | 2,5 x 6 |  |  |  | #034 | 8 | 857 | 6856 |  | #507 | 4 | 968 | 3872 |  | C1 | 1 | 3,13 | 4 |  |  | T4 | 1 | 2,5
PLASTIQUE |  |  |  |  |  |  |  | #035 | 6 | 696 | 4176 |  |  |  |  |  |  | C2 | 1 | 2,78 | 4 |  |  | T5 | 1 | 0,34 |  |  |  | ref | qte | S réel | plaques
 | Plaque alvéolaire au m2 | CONEX |  |  |  |  |  | #036 | 4 | 1168 | 4672 |  |  |  |  |  |  | C3 | 1 | 3,92 | 4 |  |  | T6 | 1 | 0,65 | 2 |  |  | LIEGE SUD |  | 6,33
 | Joints bords de tole | LABBÉ |  |  |  |  | https://www.labbe-ccm.fr/profil-u-standard-c102x3586120
 | Tube PVC pression HUBLOT | MALRIEUX |  |  |  |  |  | #037 | 4 | 2297 | 9188 |  | TOTAL |  |  | 14876 |  | C4 | 1 | 4,48 | 4 |  |  | T7 | 1 | 0,34 |  |  |  | LIEGE NORD |  | 4,39
VERRE |  | COPROVER |  |  |  |  |  | #038 | 2 | 6003 | 12006 |  | en m |  |  | 14,876 |  | C5 | 1 | 4,49 | 4 |  |  |  |  |  |  |  |  | LIEGE EST |  | 14,65
 | Vitre de projection |  |  |  |  |  |  | #1001 | 50 | 359 | 17950 |  |  |  |  |  |  | S1 | 1 | 0,22 |  |  |  | TOTAL |  | 11 |  | 4 |  | LIEGE OUEST |  | 14,65
 | verre Hublot
HUISSERIES
 | portes service | LEROY MERLIN |  |  |  | 948,33
 | charnières trappe arr et hublots
 | Hublot Vitrage
 | Hublot PVC TEST
 | Hublot PVC | CAPUS + CONNEXION PRESSION
 | trappe de comble | MANO MANO |  |  |  | 192,32 | https://pro.manomano.fr/p/trappe-de-comble-plusieurs-tailles-disponibles-3058857?product_id=61127100
 |  |  |  |  |  |  |  | #1002 | 50 | 370 | 18500 |  |  |  |  |  |  | S2 | 1 | 2 |  |  |  |  |  |  |  |  |  | LIEGE PLAF |  | 14,74
GARNITURE SIEGES |  |  |  |  |  |  |  | #1003 | 50 | 706 | 35300 |  |  |  |  |  |  | S3 | 1 | 2 |  |  |  |  |  |  |  |  |  | LIEGE FAUX PLAF |  | 14,74
 | mousse |  |  |  |  |  | contact@guiraud-mousse.fr | #1004 | 50 | 310 | 15500 |  |  |  |  |  |  | S4 | 1 | 0,96 |  |  | tube rond alu 35 ep 2
 |  |  |  |  |  |  |  | #1005 | 50 | 375 | 18750 |  |  |  |  |  |  | S5 | 1 | 0,96 |  |  |  |  |  |  |  |  |  | TOTAL |  | 69,5 | 50
Quicaillerie |  |  |  |  |  |  |  |  |  |  |  |  |  |  |  |  |  |  |  |  |  |  |  | ref | qte | l | l total
 | joint silicone |  |  |  |  |  |  | TOTAL |  |  | 337359 |  |  |  |  |  |  | TOTAL |  | 52,012 |  | 17 |  |  | 3 | 1452 | 4356 |  | Cornière acier 30 x 30 ep 3
FACONNAGE TOLE | AQUABRASION : E3-E4-E5-W3-W4-W5-N1-N2 |  |  |  |  |  |  |  |  |  | 56,2265 |  |  |  |  |  | tole alu brut 3000 x 1500 ep 1,5 |  |  |  |  |  |  |  | 6 | 735 | 4410
 | DURAND PLIAGE : N1-N2- |  |  |  |  |  |  |  |  |  |  |  |  |  |  |  |  |  |  |  |  |  |  |  | 2 | 424 | 848 |  |  | ref | qte | l | total l
 | DURAND PLIAGE + COUPE : C1_C2_C3_C4_C5 CAISSES |  |  |  |  |  |  |  |  |  |  |  |  |  |  |  |  | ref | qte | S réel | plis | plaques |  |  | 3 | 876 | 2628 |  |  | Support Manchon | 40 | 50 | 2000
 | DURAND COUPE SEULE : E1_E2_W1_W2_S1_S2S_S3_S4_S5 + GRILLES |  |  |  |  |  |  |  |  |  |  |  |  |  |  |  |  | CAISSE1 | 1 | 0,97 | 1 |  |  |  |  |  | 0
 |  |  |  |  |  |  |  |  |  |  |  |  |  |  |  |  |  | CAISSE2 | 1 | 0,97 | 1 |  |  |  |  |  | 0 |  |  | TOTAL |  |  | 2000
 |  |  |  |  |  |  |  |  |  |  |  |  |  |  |  |  |  | CAISSE3 | 1 | 1,96 | 2 |  |  |  |  |  | 0 |  |  | en m |  |  | 2
 |  |  |  |  |  |  |  |  |  |  |  |  |  |  |  |  |  | CAISSE4 | 1 | 1,96 | 2 |  |  | TOTAL |  |  | 12242
 |  |  |  |  |  |  |  |  |  |  |  |  |  |  |  |  |  |  |  |  |  |  |  | en m |  |  | 12,242
 |  |  |  |  |  |  |  |  |  |  |  |  |  |  |  |  |  | TOTAL |  | 5,86 |  | 2

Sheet: Demande devis Arcelor
Article | REF | Quantité
Tube carré 30x2mm Aluminium extrudé | AW6060T6 EN 573-3 6000 | 60
Tube carré 35x2mm Aluminium extrudé | AW6060T6 EN 573-3 6000 | 3
barre ronde 10mm Aluminium extrudé | AW6060T6 EN 573-3 6000 | 2
barre rectangulaire 30x3mm Aluminium extrudé | AW6060T6 EN 573-3 6000 | 1
tôle Aluminium laqué poudre RAL9016 Brillant/EN 573-3 1,5x1500x3000mm | AW5005H42 filmé blanc-noir | 18
tôle Aluminium laminé 1,5x1500x3000mm Longueur : 3 000 mm | AW5754H111 EN 573-3 | 2
tuberond35x2mm Aluminium extrudé | AW6060T6 EN 573-3 6000 | 3
tube rond 50x2mm Aluminium extrudé | AW6060T6 EN 573-3 6000 | 8
profil creux carré soudé 40x2 mm galvanisé Sendzimir | S235JRH EN 10219-1 6000 | 2
tôle perforée C10U12 Galvanisé Acier 1x1000x2000 |  | 4
tôle EN 10143 Galvanisé E-passivation EN 10346 0,8x1500x3000mm | DX51D+Z275 MA | 3
cornièreàaileségales 1PC 30x3mm EN 10056-1 | S275JR 6000 | 1
Non dispo sur le site
Article | REF | Quantité
Tube rectangle 30x40x2mm Aluminium extrudé en 6m |  | 4
Cornière alu 100x50x3mm Aluminium extrudé en 6m |  | 3
barre rectangulaire (plat) 80x3mm Aluminium extrudé en 6m |  | 1
profil U galvananisé 60x160x4mm en 6m |  | 1

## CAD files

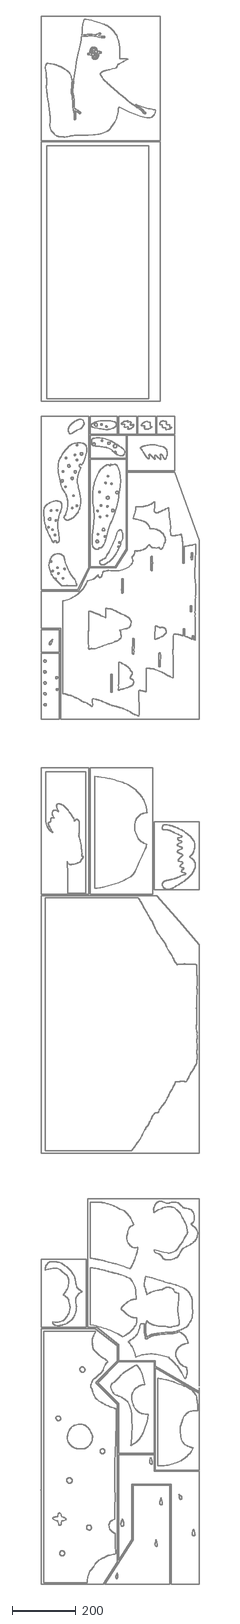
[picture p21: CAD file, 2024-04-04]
contenu/animations/colo/M_049.dxf
498.8 x 4922.3

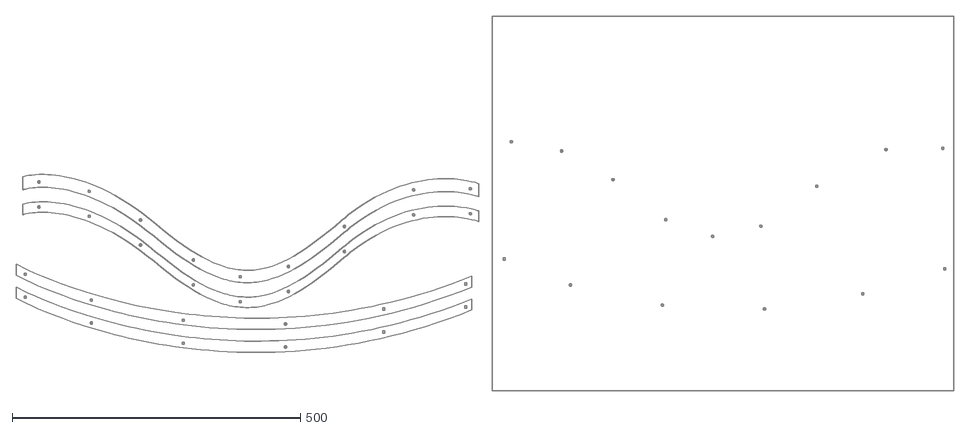
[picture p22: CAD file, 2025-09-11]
contenu/animations/periodemalheureuse-plexi.dxf
1625.4 x 650.0

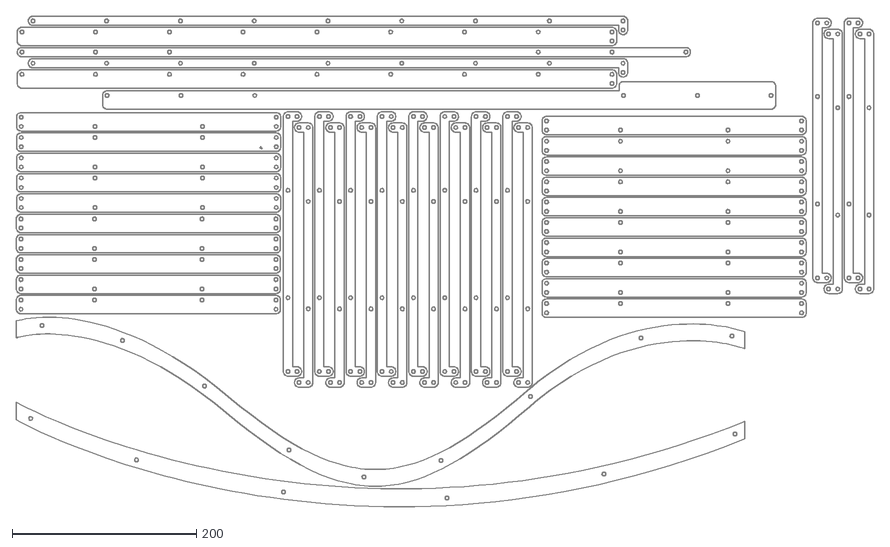
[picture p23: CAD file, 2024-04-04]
contenu/animations/plexi/trans4-3.dxf
929.8 x 531.9

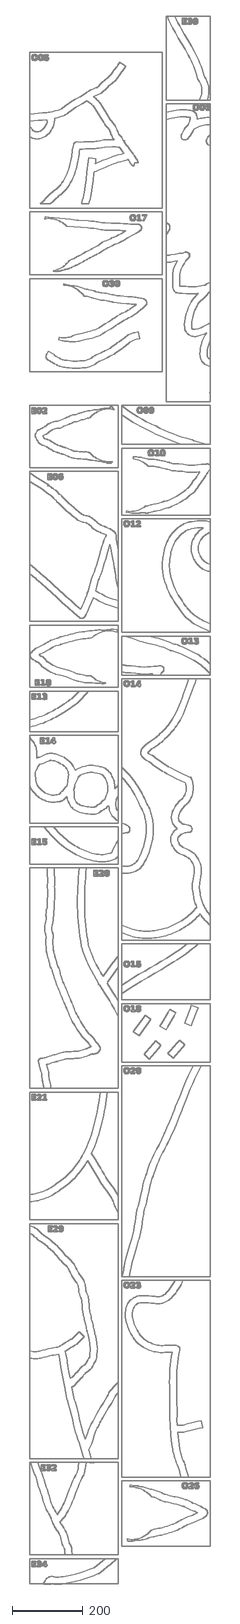
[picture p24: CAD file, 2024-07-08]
contenu/plans/remorque-aspect-rouleau-4.dxf
510.7 x 4430.1

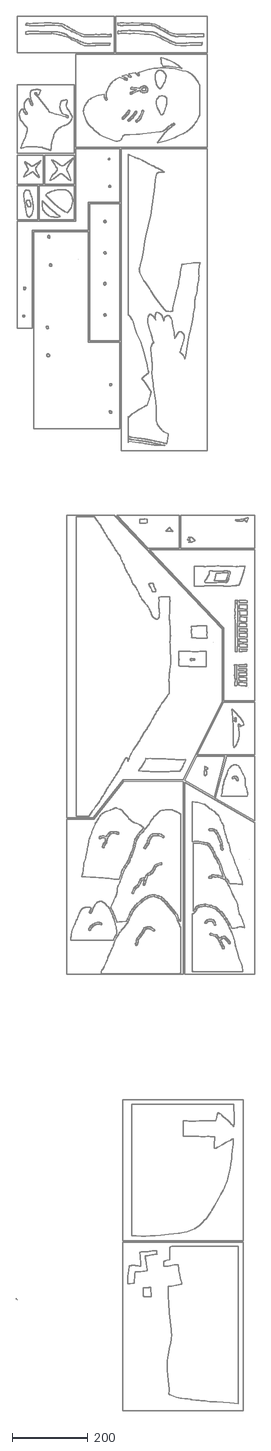
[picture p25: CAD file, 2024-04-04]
contenu/animations/colo/M_073.dxf
629.6 x 3677.1

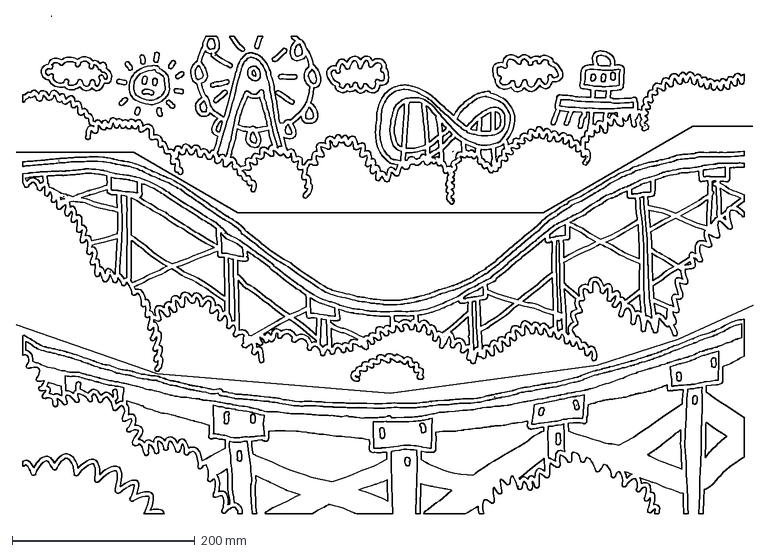
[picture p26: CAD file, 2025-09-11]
contenu/animations/periodemalheureuse-colo-070.dxf
807.2 x 545.2 mm

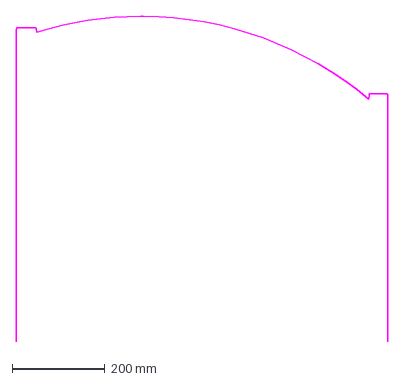
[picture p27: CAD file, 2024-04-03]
contenu/animations/plexi/trans3-8-big.dxf
800.0 x 700.0 mm

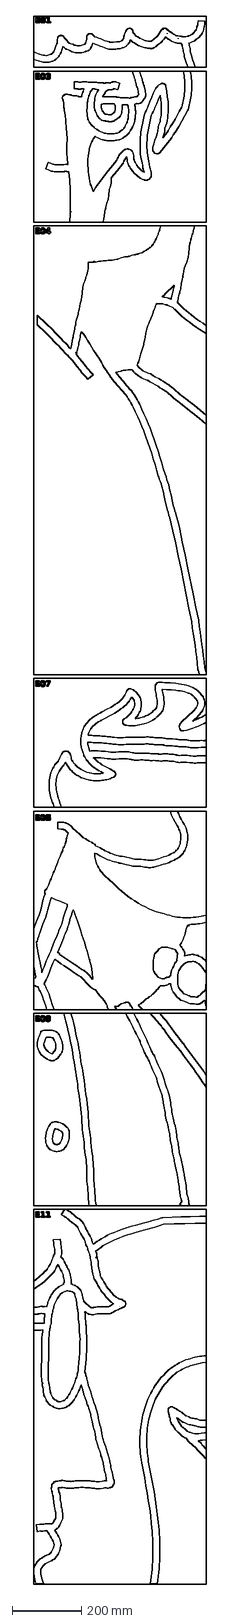
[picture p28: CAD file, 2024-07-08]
contenu/plans/remorque-aspect-rouleau-1.dxf
500.0 x 4533.5 mm

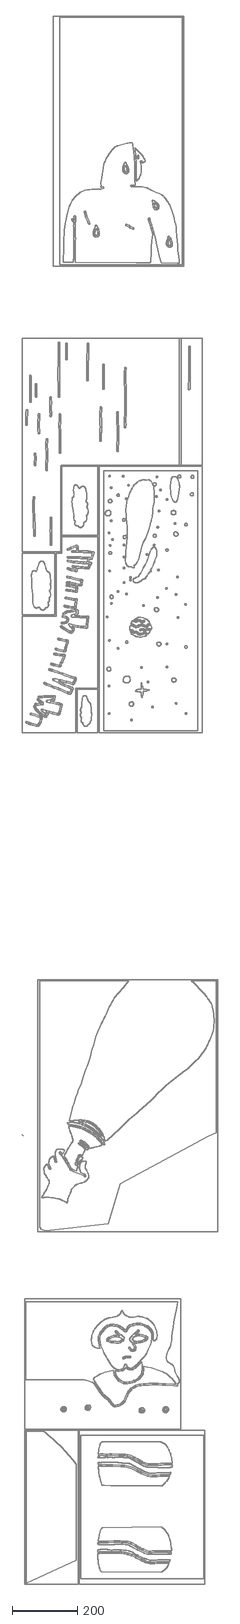
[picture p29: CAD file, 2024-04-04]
contenu/animations/colo/M_070_B.dxf
598.9 x 4799.2

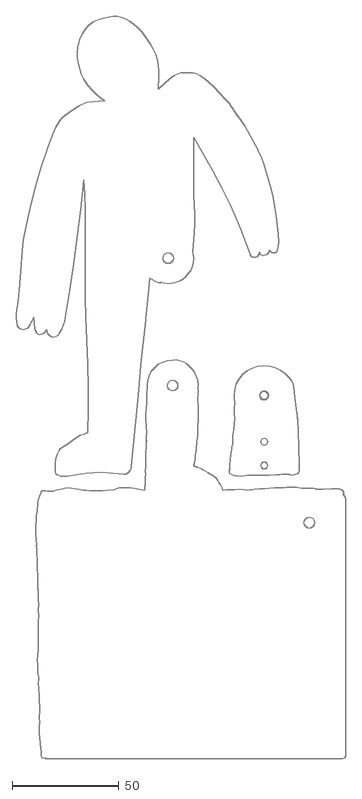
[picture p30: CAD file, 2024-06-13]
contenu/animations/plexi-noir-session-juin.dxf
154.5 x 347.9

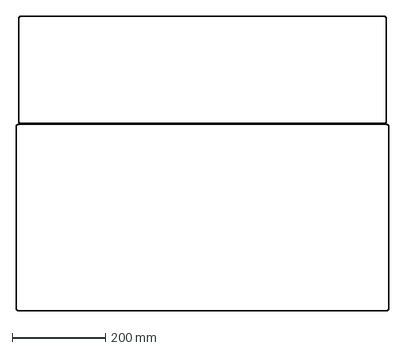
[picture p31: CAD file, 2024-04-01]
contenu/animations/plexi/trans3-5.dxf
800.0 x 632.0 mm

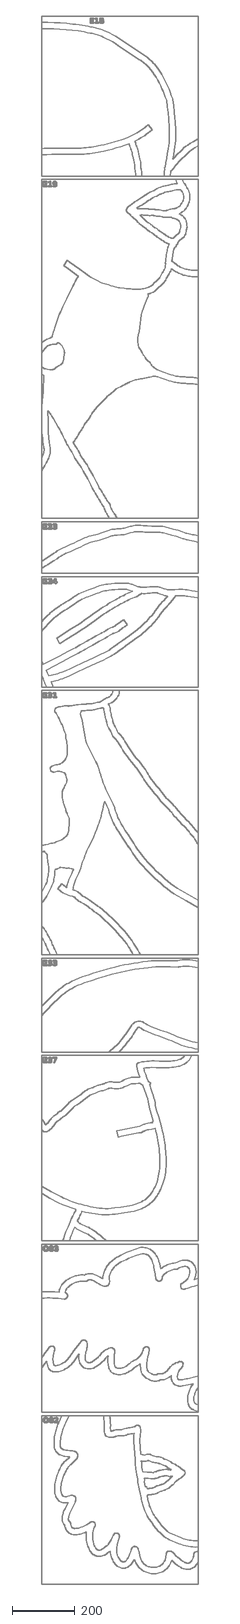
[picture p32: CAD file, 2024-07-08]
contenu/plans/remorque-aspect-rouleau-2.dxf
500.0 x 4996.7

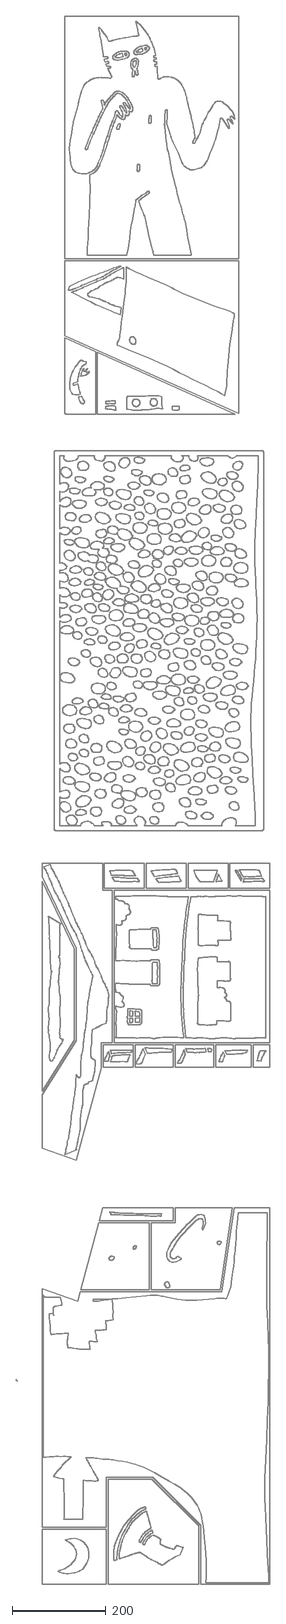
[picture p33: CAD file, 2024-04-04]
contenu/animations/colo/M_074.dxf
541.6 x 3345.3

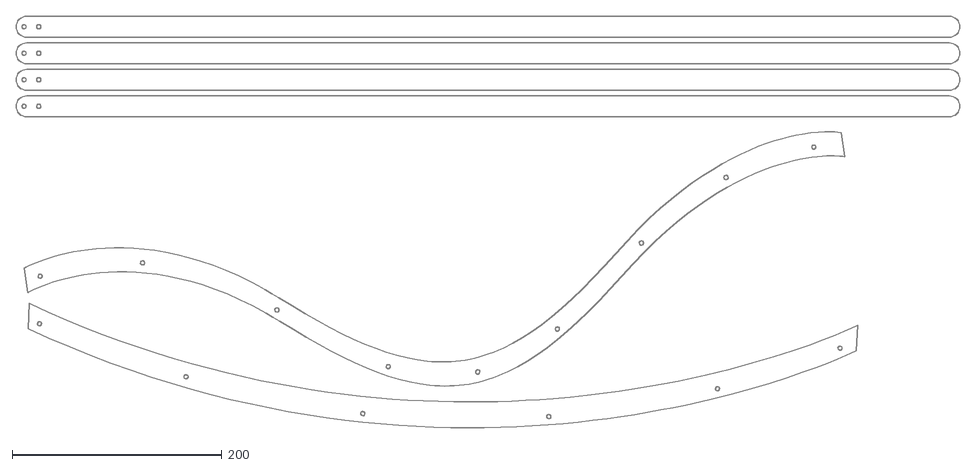
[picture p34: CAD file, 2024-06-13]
contenu/animations/plexi-trans4mm-session-juin.dxf
900.0 x 392.4

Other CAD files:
contenu/animations/plexi/noir3-3.dxf
contenu/plans/remorque-aspect-rouleau-5.dxf
contenu/animations/colo/M_070_A.dxf
contenu/animations/periodemalheureuse-colo-073.dxf
contenu/animations/colo/020.dxf
contenu/animations/colo/031.dxf
contenu/animations/colo/049.dxf
contenu/animations/colo/053.dxf
contenu/animations/colo/061-grand.dxf
contenu/animations/colo/061-moyen.dxf
contenu/animations/colo/061-petit.dxf
contenu/animations/colo/061.dxf
contenu/animations/colo/069.dxf
contenu/animations/colo/070.dxf
contenu/animations/colo/073.dxf
contenu/animations/colo/074.dxf
contenu/animations/colo/M_020.dxf
contenu/animations/colo/M_031.dxf
contenu/animations/colo/M_061.dxf
contenu/animations/colo/M_069.dxf
contenu/animations/colo/M_070.dxf
contenu/animations/mecanique-animations-test.dxf
contenu/animations/periodemalheureuse-colo-074.dxf
contenu/animations/plexi-noir-session-mai.dxf
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

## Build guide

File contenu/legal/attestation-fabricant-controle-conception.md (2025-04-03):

---
type: legal
---

# Camera Obscura

## Contrôle de la solidité et de la stabilité à la conception

**Objet : déclaration du fabricant attestant du respect des dispositions relatives à la solidité et à la stabilité**

Je, soussigné Bertrand Lenclos, fabricant de l'établissement itinérant recevant du public CAMERA OBSCURA,

atteste que l'ensemble a été conçu et fabriqué de manière à assurer sa solidité et sa stabilité.

En particulier, vu le TITRE III relatif à la solidité de l'arrêté du 25 juillet 2022 fixant les règles de sécurité et les dispositions techniques applicables aux structures provisoires et démontables, j'atteste que :

- Les matériaux utilisés sont suffisamment durables conformément à l'article 8 ;
- Les principaux éléments de structure sont marqués conformément à l'article 9 ;
- Le dimensionnement des structures a été conçu tenant compte des sollicitations et charges auxquels elles seraient soumises, conformément à l'article 10.

Fait à <input>, le <input>.

Signature, cachet du fabricant :

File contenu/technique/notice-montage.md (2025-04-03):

# Notice de montage de Camera Obscura

__ATTENTION DOCUMENT EN COURS DE RÉDACTION__

### Préconisations relatives aux appuis au sol

Lors du montage, vérifier :

- la bonne horizontalité de la REMORQUE par le réglage des béquilles.
- la bonne horizontalité de la STRUCTURE SCÉNIQUE et de la STRUCTURE optique par le réglage des socles réglables à vis.
- l'utilisation de cales sous les appuis de la REMORQUE et de la STRUCTURE SCÉNIQUE si l'ensemble est implanté sur un sol meuble.

### Les modes de préhension et d'élingage

L'assemblage des éléments se fait principalement avec des colliers clamps serrage à papillon et des raccords tubulaires serrage à vis.

Lors du montage, vérifier :

- le bon serrage des colliers et raccords tubulaires.
- l'utilisation d'élingues si du matériel est suspendu à la structure.

### Les procédures de montage et de démontage en sécurité ;

Personnel : 2 personnes minimum.

Utiliser les équipements de sécurité adaptés.

Effectuer le montage dans cet ordre :

1. Placement de la remorque
2. Calage de la remorque
3. Montage des plateforme et des escaliers
4. Montage du reste de la structure

### L'outillage et les moyens de manutention nécessaires pour le montage et le démontage en sécurité ;

Voir la **notice de montage** en pièce jointe.

### Les plans de montage et les plans d'ensemble des différentes configurations de la structure ;

# Protocole de montage

### 1. Positionnement de la remorque

Matériel :

- Plan d'implantation
- Boussole
- Antivol

1. Avec le plan d'implantation comme référence positionner la remorque dans l'espace (utiliser une boussole pour vérifier l'azimut)
2. Actionner le frein à main de la remorque
4. Dés-atteler la remorque (ne pas oublier de mettre l'antivol)

### 2. Calage de la remorque

Outils :

- niveau à bulle
- manivelle pour béquilles

- 2 Cales de roue
- 4 Cales plates

1. Placer les cales de roues
2. Régler la hauteur de la roue jockey jusqu'à atteindre une bonne horizontalité sur l'axe nord-sud (vérifier l'horizontalité en plaçant un niveau sur le pas d'une des deux portes) 
3. Placer une cale plate sous chaque béquille
4. Descendre les 4 béquilles jusqu'au sol à l'aide de la manivelle.
5. Ajuster la hauteur des béquilles jusqu'à atteindre une bonne horizontalité sur l'axe est-ouest (vérifier l'horizontalité en plaçant un niveau sur la flèche). Vérifier que l'horizontalité sur l'axe nord-sud est conservée pendant cette étape. 

### 3. Montage de l'escalier principal

N.B l'escalier principal peut-être placé à l'ouest ou à l'est de la remorque.

Matériel :

- Plateau praticable 1×1
- 4 pieds 40
- Rallonge
- Raccords praticable
- Boulon rallonge
- 2 grands montants
- 4 petits montants
- main courante (3 pièces + 2 raccords tubulaires)
- 9 crochets
- Escalier
- Cales plates
- 4 socles réglables à vis

Outils :

- Niveau à bulle
- Clés pour serrage raccords praticable.

1. Fixer 4 colliers aux manchons 12 14 22 24.
2. Monter la rallonge du plateau en fonction de la position de l'escalier (se référer au marquage)
3. Monter les pieds carrés sur le plateau, placer l'ensemble au sol sur des socles réglables à vis.
4. Régler grossièrement la hauteur pour que le plateau arrive au niveau du plancher de la remorque.
5. Assembler l'escalier avec les raccords côté plateau et boulon côté rallonge. (2 personnes : une personne maintien l'escalier, une personne procède à l'assemblage)
6. Positionner l'ensemble devant la porte.
7. Assembler et monter la rampe. Un grand montant est fixé aux crochets 12 et 14 ; un grand montant est fixé aux crochets 22 et 24 ainsi qu'à un crochet sur l'escalier. Les petits montants sont chacun fixés à un crochet sur l'escalier ou la rallonge.
8. Vérifier que la porte peut s'ouvrir, vérifier la stabilité et l'horizontalité de l'ensemble régler le positionnement des crochets et des socles si besoin, utiliser des cales plates sous les montants si nécessaire.
9. Vérifier le serrage des crochets.

### 4. Montage de l'escalier de secours
### 5. Montage de la structure optique
### 6. Montage de la structure scénique
### 7. Montage du réflecteur
### 8. Montage du portique

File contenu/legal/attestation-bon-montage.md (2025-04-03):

---
type: legal
---

# Camera Obscura

## Attestation de bon montage

### Événement

**Nom :** <input>  
**Adresse :** <input>  
**Dates :** <input>  

### Entreprise en charge de l'installation

**Nom :** NOKILL  
**Adresse :** 6 Rue du Docteur Bastié — 81300 Graulhet  
**Courriel :** cie@nokill.fr  
**Téléphone :** 06 09 90 38 97

**Responsable du montage :** <input>  
**Téléphone :** <input>  
**Fonction :** référent technique

### Caractéristiques de l'ensemble démontable

**Fabriqué par :** NOKILL  
**Descriptif sommaire :** Camera Obscura, Salle de spectacle itinérante

**Documents et plans utilisés pour l'installation :**

- [schéma d'implantation](../technique/implantation.md) ;
- [notice technique](/notice-technique.md).

**Liaison au sol :** autoporté

### Vitesse de vent

**Vitesse de vent retenue (km/h) :** <input>

(Vitesse de vent maximum : 72 km/h)

### Sécurisation des équipements techniques suspendus

Réalisée conformément aux dispositions de l'article 26 de l'arrêté du 25 juillet 2022 fixant les règles de sécurité et les dispositions techniques applicables aux structures provisoires et démontables.

---

Je, soussigné <input> (Référent Technique)

certifie avoir monté l'ensemble démontable conformément :

- aux pièces graphiques ;
- à la notice technique et aux plans du fabricant ;
- à l'arrêté fixant les règles de sécurité et les dispositions techniques applicables aux structures provisoires et démontables.

Fait à <input>, le <input>

en deux exemplaires originaux.

Signature du référent technique :

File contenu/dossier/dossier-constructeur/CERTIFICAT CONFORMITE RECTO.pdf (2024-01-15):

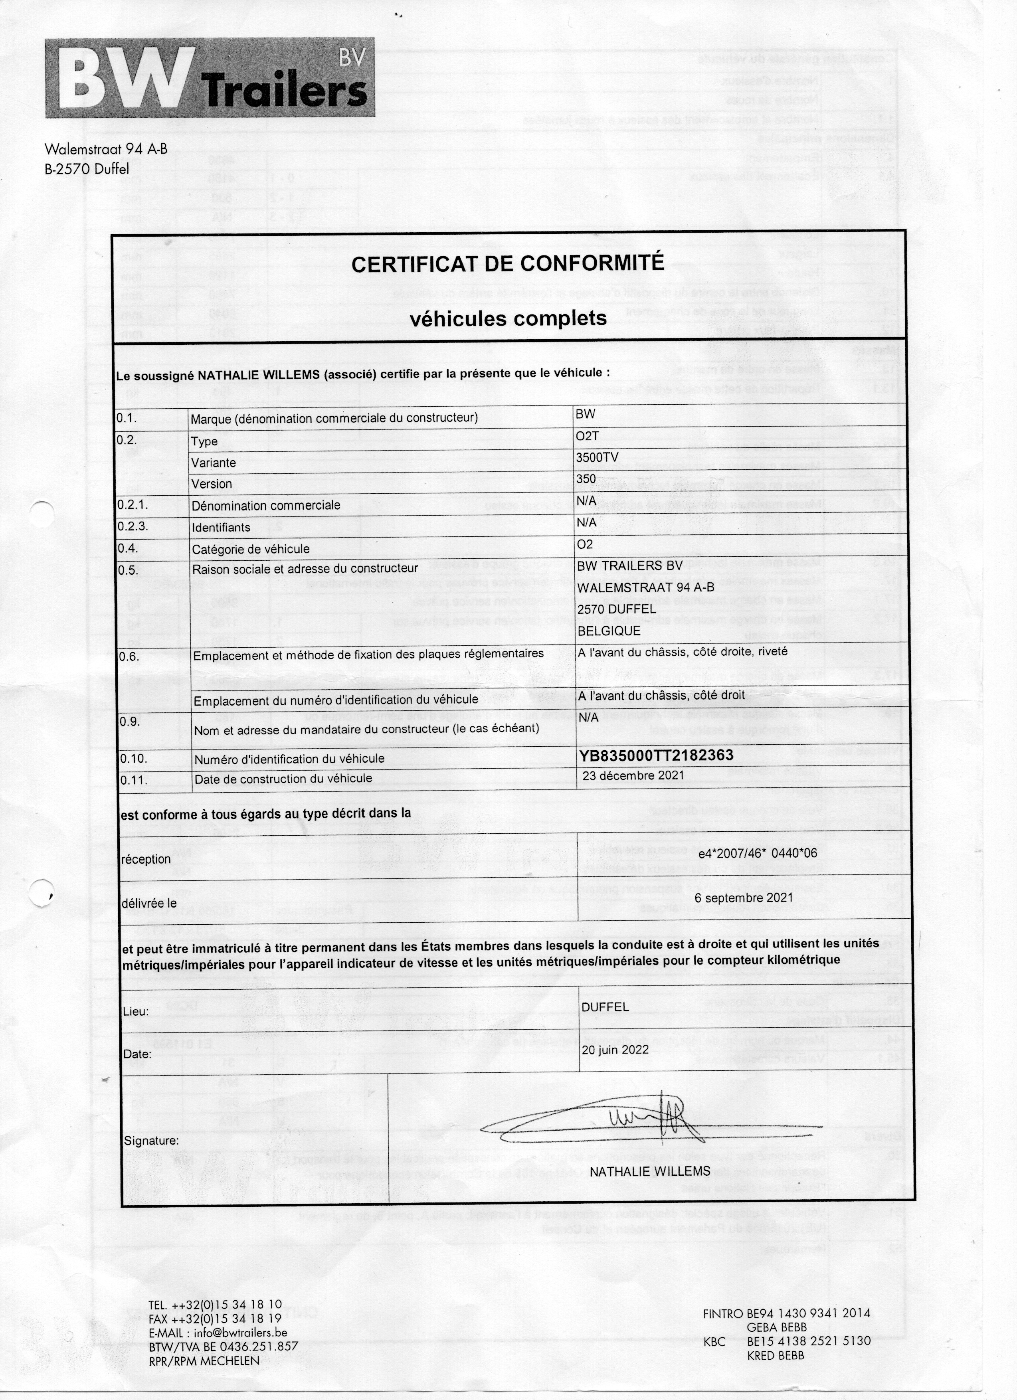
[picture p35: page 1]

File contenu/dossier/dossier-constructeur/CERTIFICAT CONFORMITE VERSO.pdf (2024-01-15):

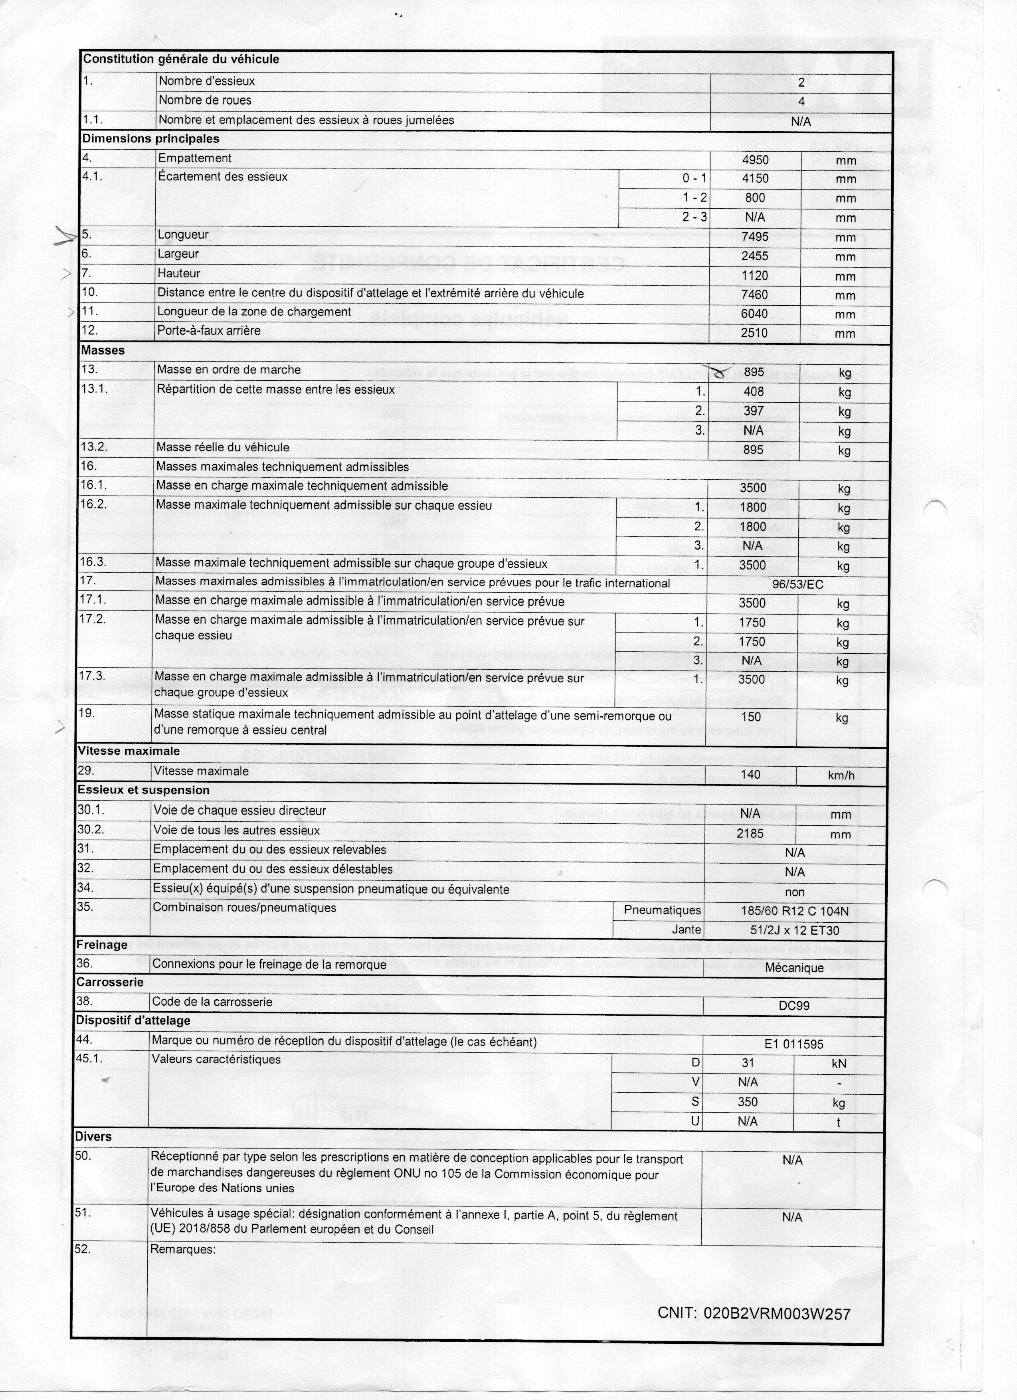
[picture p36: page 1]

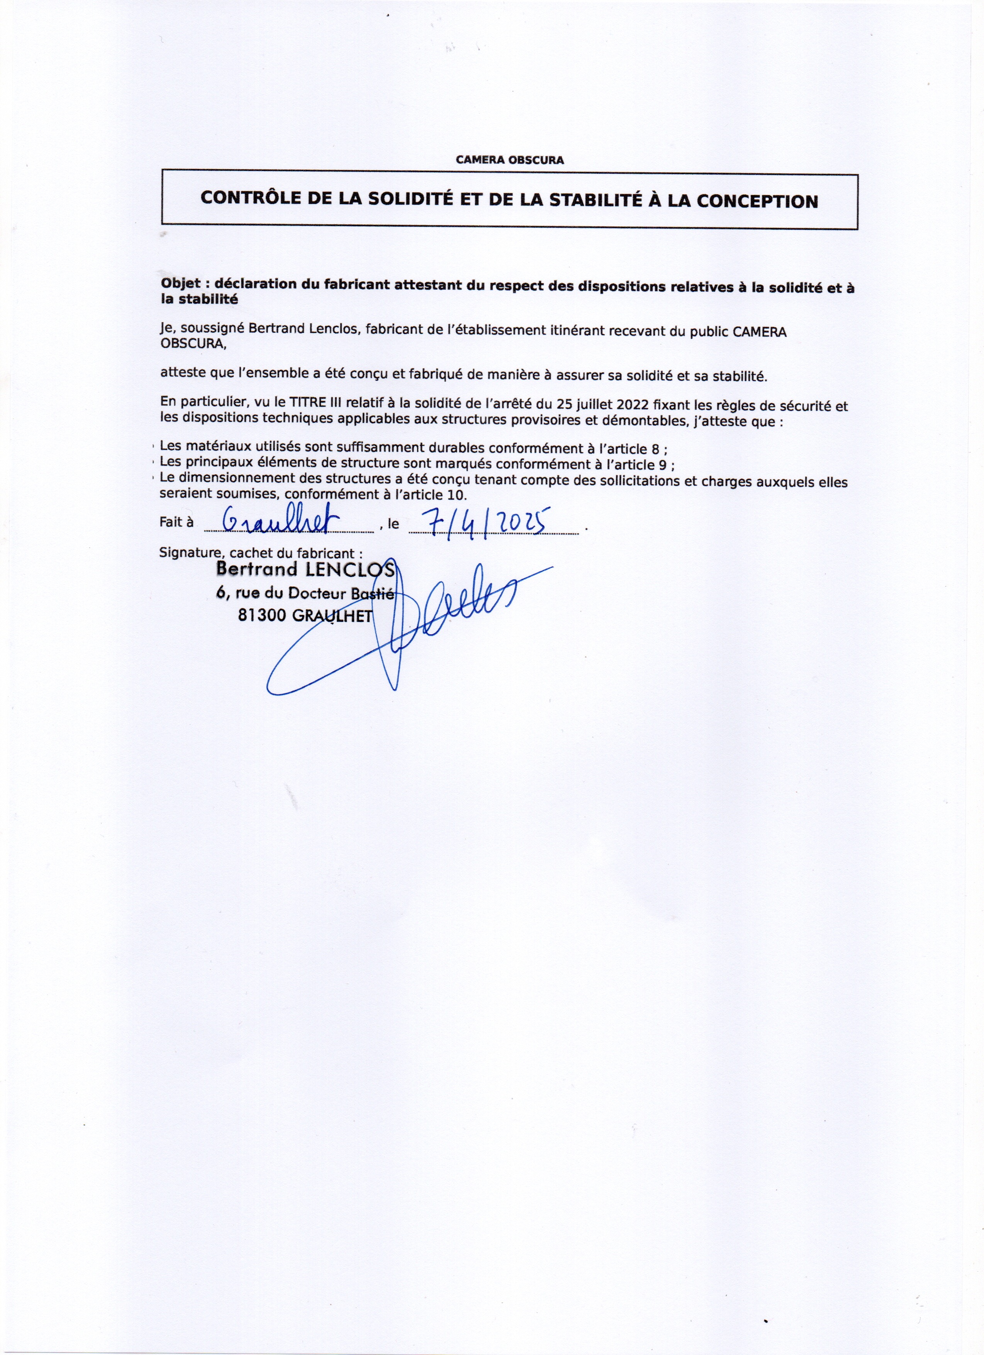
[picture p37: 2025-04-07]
contenu/legal/attestation-fabricant-controle-conception-signe.jpg

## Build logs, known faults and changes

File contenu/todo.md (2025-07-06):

{% include alert.html type="pas-interessant" %}

# TODO
      
Les todo ont été déplacés vers l'onglet Production

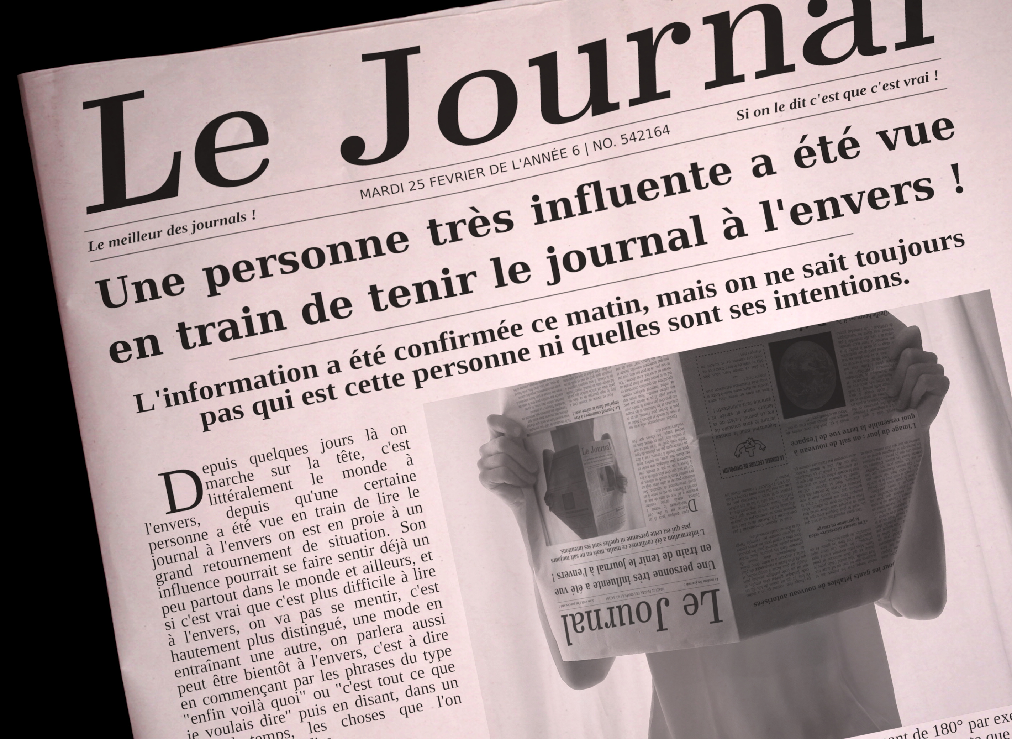
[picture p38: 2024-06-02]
contenu/photos/rouleau-photo/photo-journal.jpg

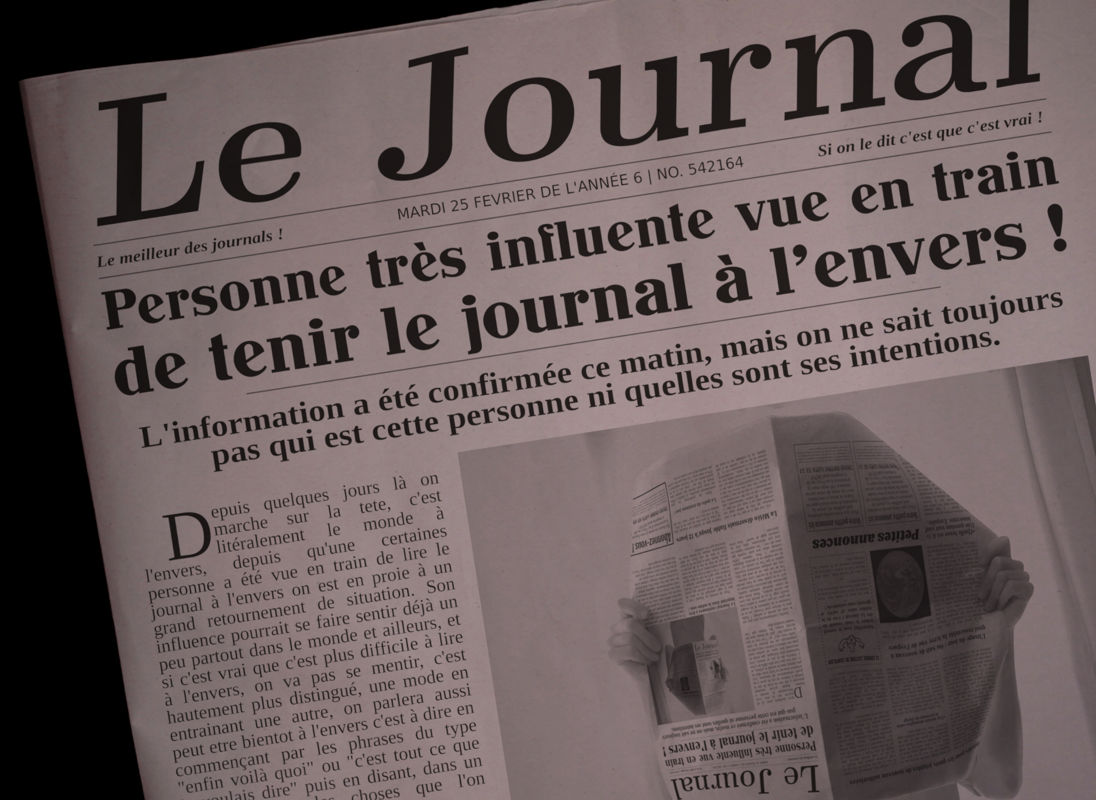
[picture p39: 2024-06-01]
contenu/objet/journal/le-journal.jpg

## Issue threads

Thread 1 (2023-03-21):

passer tout le site dans docs/

LeonLenclos, 2023-03-21:
1. renommer contenu/ en docs/
2.  mettre la racine de github pages sur doc
3. `mv /README.md /docs/`
4. créer un nouveau README.md à la racine pour renvoyer sur le site.

Closed 2023-03-23.

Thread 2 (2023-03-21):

créer un dossier pout les questions tech

LeonLenclos, 2023-03-21:
créer un dossier questiontech/ ou autre nom avec dedans un README.md qui recense tous les domaines techniques dans lesquels on a des problemes ou des solutions. Créer une page pour chacun de ces domaines.

BertrandLenclos, 2023-03-23:
fait

Closed 2023-03-23.

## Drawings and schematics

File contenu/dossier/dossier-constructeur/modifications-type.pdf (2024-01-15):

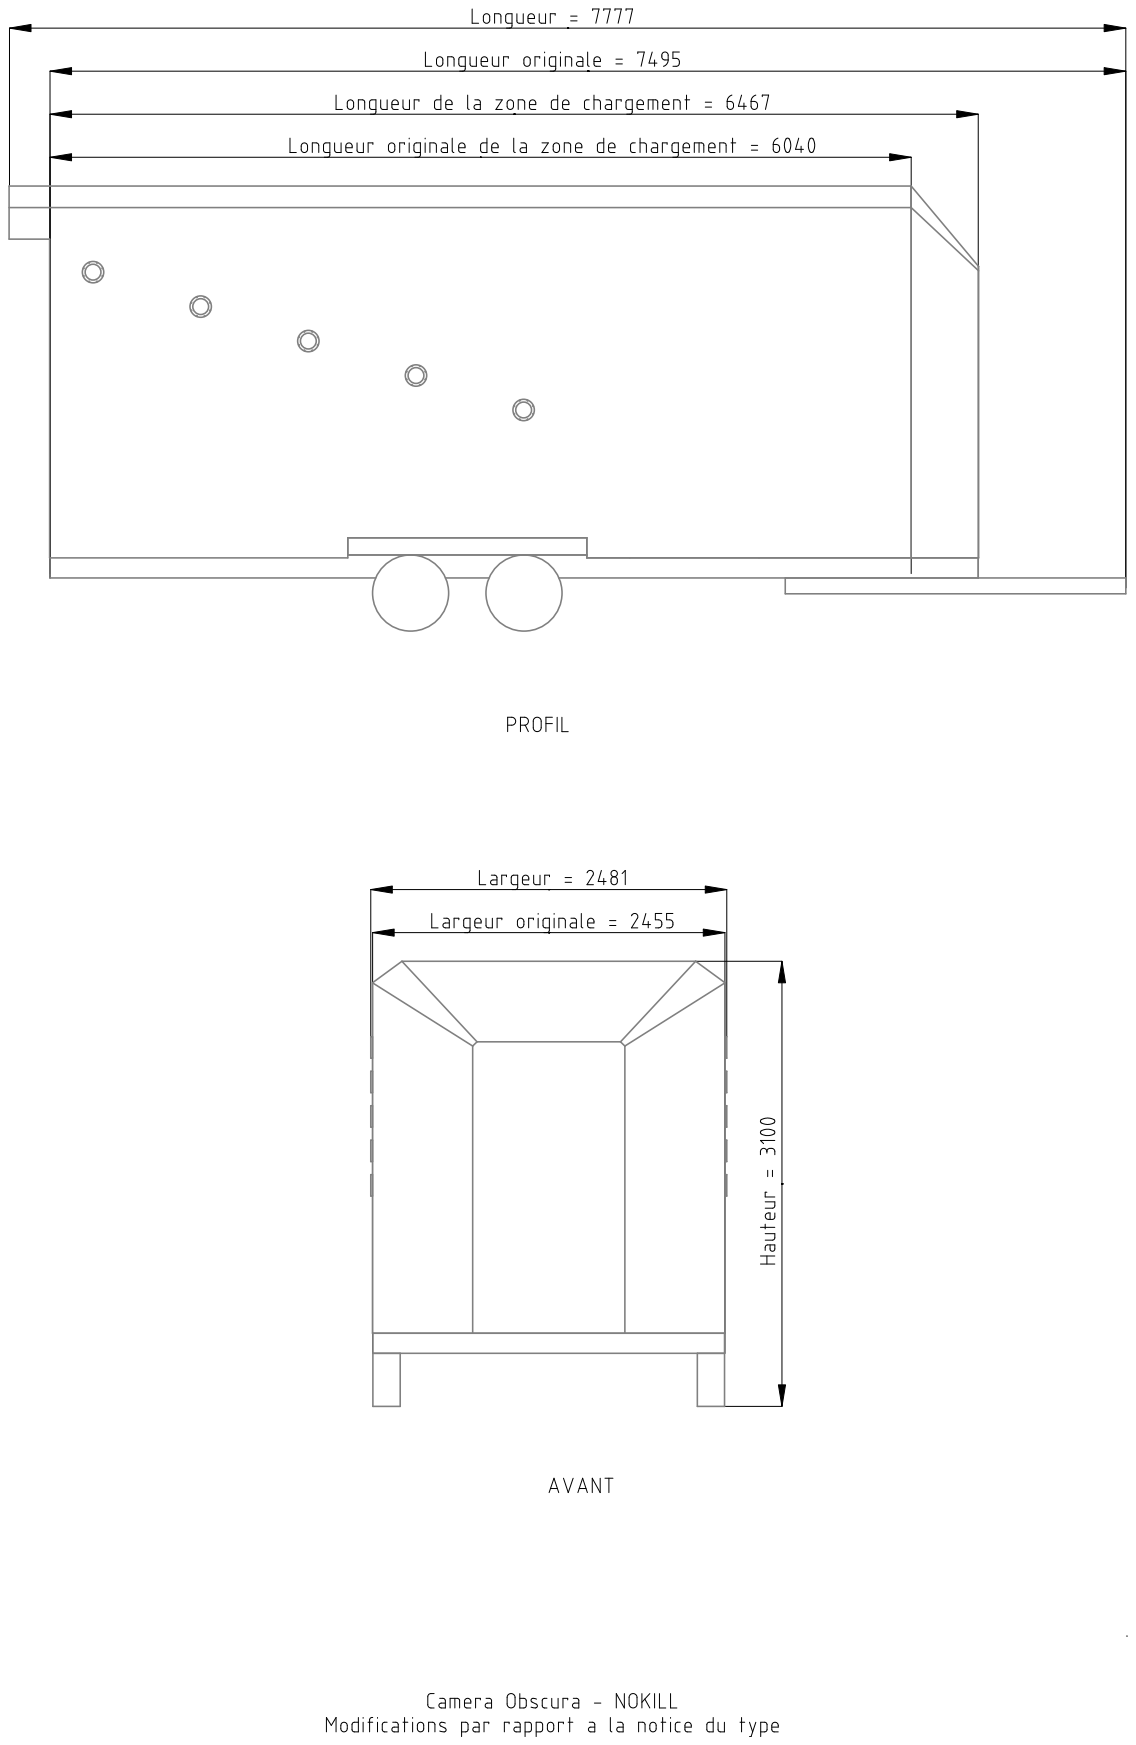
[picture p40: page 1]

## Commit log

2023-06-07 plan miroir
    [decoupe-miroir-en-toit.dxf]
2023-06-07 miroir a 45
    [mirroir-a-45.dxf]
2023-06-11 miroirs et planchette
    [planchette-draft.dxf]
2023-06-14 ('<_ '
    [calcul_optique.ods]
2023-06-15 Passage du tableau des lentilles en vertical
    [calcul_optique.ods]
2023-07-14 Dessins tech
    [cage.dxf, mirroir-a-45-structure.dxf, toit-amici-structure.dxf]
2023-09-20 plans aquabrasion
    [remorque-detail-aquabriasion.dxf, remorque.dxf]
2023-09-20 relecture en visio
    [calcul_optique.ods]
2023-09-22 corrections plan remorque
    [remorque.dxf]
2024-01-10 slides et planchette
    [planchette-draft.dxf]
2024-02-10 fiche tech print
2024-02-23 anim et fut
    [fut.dxf]
2024-03-05 tentative de redirection
2024-03-05 FUT pour Fablab
    [fut.dxf]
2024-06-03 fut 138
    [fut.dxf, fut138V1-laser.dxf]
2024-08-20 Rename Fiche technique _ Camera Obscura.pdf to fiche-technique.pdf
2024-10-15 Rename Fiche technique _ Camera Obscura_2410.pdf to fiche-technique.pdf
2025-08-24 Rename Fiche technique _ Camera Obscura.pdf to fiche-technique-camera-obscura.pdf
